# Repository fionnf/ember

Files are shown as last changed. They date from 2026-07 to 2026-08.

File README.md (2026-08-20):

# Ember

Two Raspberry Pi Pico W boards keeping their SK6812 RGBW LED strips in sync over MQTT. Touch one lamp and both shift colour together. Control everything from a web app that works on any phone or browser.

---

## Overview

```
[Web UI] ──MQTT (WebSocket)── [board_a / BOSS] ──sync── [board_b / follower]
                                SK6812 strip               SK6812 strip
```

One board (`board_a`, display name **A**) is the BOSS; the other (`board_b`, **B**) is the follower. Both subscribe to the same MQTT topic and keep their strips in sync. The web UI publishes JSON commands to the same topic and reflects live state from both boards.

---

## Hardware

| Part | Notes |
|---|---|
| Raspberry Pi Pico W (×2) | The W variant — needs WiFi |
| SK6812 RGBW LED strip | 10 LEDs per board, GRBW byte order |
| Data pin | GPIO 5 |
| 300–470 Ω resistor | Series on DIN — prevents ringing |
| 5 V power supply | USB or direct to strip |

### Wiring

```
Pico W GPIO 5 ──[330Ω]──── DIN ────────────── DOUT
5 V / 3.3 V   ─────────── VCC
GND           ─────────── GND

Pico W TOUCH_PIN ──┬──── copper pad / foil
                   └─[1MΩ]── GND
```

> Data flows DIN → DOUT; connect the board's data wire to the **DIN** end of the strip.

If board B connects via the far end (DOUT side), set `REVERSE_LEDS = True` in `config.py` to flip group order in software.

---

## Firmware

### Files

| File | OTA-updated | Purpose |
|---|---|---|
| `boot.py` | Never | OTA bootstrap — downloads firmware from GitHub on every boot |
| `main.py` | Yes | Main loop: WiFi, MQTT, touch, alarms, BOSS sync |
| `colour.py` | Yes | Colour engine: groups, fades, breathing, drift |
| `sk6812.py` | Yes | PIO-based SK6812 RGBW driver |
| `touch.py` | Yes | Capacitive touch detection |
| `config.py` | Never | Per-board constants (never overwritten by OTA) |

### OTA Updates

`boot.py` runs before `main.py` on every boot. It connects to WiFi and downloads the latest `main.py`, `colour.py`, `sk6812.py`, and `touch.py` from the `master` branch of this repo. `config.py` and `boot.py` are never touched. If WiFi is unavailable the board boots from whatever is already on flash.

To update both boards: commit and push to `master`, then click **↺ Reboot Both Boards** in the Settings panel.

Updates are **all-or-nothing**: every file is downloaded and compile-checked before any is installed, so a mid-update network drop can't leave a new `main.py` running against an old `colour.py`.

### Crash-loop rollback

The compile gate rejects firmware that doesn't parse, but valid code can still fail at runtime — a stray function-level `import` once shadowed a module-level one and both boards boot-looped, unreachable until a human pushed a fix. So the boards now keep a way back:

1. `boot.py` increments a counter in `bootfail.txt` on every boot. A **power-on** reset doesn't count — only soft and watchdog resets, which is what a crash loop produces.
2. Once `main.py` has run for a minute it calls `mark_stable()`: the counter is cleared and the running files are promoted to `.ok` backups. Backups are only rewritten when they actually differ, so this costs no flash in steady state.
3. After **3** boots that never reach stability, `boot.py` restores the `.ok` set and skips the update for that one boot — otherwise it would immediately reinstall the firmware that was failing. The lamp comes back on its own in about 15 seconds.
4. The board reports `rolled_back: true` in its heartbeat until it is stable again, so a rejected push is visible rather than silent.

No record is kept of the rejected version: the next scheduled reboot re-downloads `master`, so a pushed fix is picked up with no stale state to clear, and a few quick power cycles can't pin a board to old firmware.

> `boot.py` is **never** updated over the air — a broken bootloader would need USB to recover. Copy it to each board manually once to get this feature (`mpremote connect /dev/ttyACM0 cp boot.py :`).

### Configuration (`config.py`)

```python
BOARD_ID   = "board_a"    # "board_b" on the second Pico
BOSS       = True         # True on board_a only

NUM_LEDS       = 10
LED_PIN        = 5
REVERSE_LEDS   = False

NUM_GROUPS     = 3
GROUP_MIN_LEDS = 1
GROUP_MAX_LEDS = 8

LED_BRIGHTNESS = 0.6
FADE_STEPS     = 60       # steps per colour transition (~1 s at 60 Hz)
BREATHE_SPEED  = 0.0008   # radians/ms
BREATHE_DEPTH  = 0.04     # ±4% brightness oscillation

IDLE_DRIFT_INTERVAL_S = 45

MQTT_BROKER        = "broker.hivemq.com"
MQTT_PORT          = 1883
MQTT_TOPIC_PREFIX  = "ember_CHANGEME"   # ← set to your own unique value

WIFI_NETWORKS = [
    ("YourSSID", "YourPassword"),
]
```

### MQTT

- **Broker:** `broker.hivemq.com:1883` (TCP on device) / `:8884` WSS (web)
- **Events topic:** `<your-prefix>/events`
- **Alarms topic:** `<your-prefix>/alarms` (retained, subscribed by boards)
- **Status topic:** `<your-prefix>/status/<board_id>` (retained, Last-Will)
- **Scenes topic:** `<your-prefix>/scenes` (retained, client-to-client scene library)

All messages are JSON with a `from` field for echo suppression. The full contract is documented in [MQTT Protocol Specification](#mqtt-protocol-specification) — that section is the reference for writing an additional client.

### Colour Engine (`colour.py`)

The `ColourEngine` class manages per-group colour state:

- **Palette position** (`pos`, float 0.0–1.0): maps into a 30-stop hue palette blended with warm white. `0.0` = pure warm white (W channel only); higher values = saturated hues with W fading out.
- **Groups**: the strip is split into 1–N independent colour zones. Each group has a `pos` (hue) and a `w` (warm-white level). Group sizes are stored separately.
- **Fade**: each group independently crossfades from its start colour to its target over `FADE_STEPS` ticks, eased with smoothstep so the transition begins and ends imperceptibly. A fade takes the time it says it does — `fade_steps: 60` really is ~1 s.
- **Breathing**: a per-group sine oscillator adds a slow ±4% brightness pulse with staggered phases.
- **Drift**: optional autonomous colour drift — subtle hue nudges and group-size shifts every `IDLE_DRIFT_INTERVAL_S` seconds. Disabled by default in the web UI (`driftEnabled = false`).
- **Power**: soft on/off with an ~800 ms fade.

### BOSS / Follower Sync

When the BOSS's physical touch sensor fires, it runs `ColourEngine.impulse()` (random colour change), then publishes its new state with `"sync": true`. The follower applies the same groups with a fast fade (`SYNC_FADE_STEPS`) so both strips match immediately.

Every 60 s the BOSS publishes its state with `"sync": true` as a drift-correction heartbeat. The follower applies it with a slow 300-step fade so re-alignment is invisible.

**Independent mode.** That periodic sync would otherwise undo deliberate per-lamp settings — set one lamp with **Send to → B** and it reverted within a minute. So a **targeted** command (one carrying `target`) unlinks the lamps and suppresses the BOSS sync for 30 minutes; a **broadcast** colour command — which sets both lamps to the same thing — re-links them immediately. Boards notice targeted traffic even when it is addressed to the other lamp, so the BOSS knows to stand down.

### Alarms

Each board holds the whole schedule on its own flash (`alarms.json`) and evaluates it against its own clock, so **alarms fire with no client connected**. On each main-loop tick the board compares the current UTC time against enabled alarms and runs:

- **Sunrise** (`type: "sunrise"`): switches on and ramps brightness from 0 to `alarm.brightness` over `duration_min` minutes, sweeping **colour** alongside it — ember red → deep orange → amber → warm white. Because brightness rises together with the colour, the early stops are seen dim and deep, like a real dawn.
- **Bedtime** (`type: "sunset"`): the same sweep in reverse — warm white deepens to ember as it dims — then switches off (restoring the previous brightness so the next power-on isn't dark).

The gradient is `SUNRISE_STOPS` in `colour.py`, deliberately **not** taken from `TINT_PALETTE`: there a single `pos` sets hue and saturation together, so anything warm is also nearly white and a dawn would be an invisible tint.

Stops are evenly spaced by index, so where they sit is what shapes the fade. They are weighted toward the red end: the dawn opens on near-pure red `(255,6,0,0)`, the white LED stays completely dark for the first three fifths, and the turn to warm white happens in the last stretch. Red is never given up — the R channel is full the whole way — so it lands on a warm white with red still under it rather than a cold one. `tests/test_sunrise.py` pins that shape, so the stops stay tunable but the character can't drift back to turning orange almost immediately.

The schedule reaches boards two ways: the **retained** `P/alarms` topic, which boards subscribe to so an offline or rebooting board picks it up on reconnect, and a `set_alarms` message on `P/events` for boards that are already online. Alarms are compared in **UTC**; clients convert local time. See the [protocol spec](#alarms-1) for the exact format.

Two requirements: the board needs a **synced clock** (NTP at boot, retried hourly — the heartbeat's `ntp` field reports this, and the web UI warns when it's false), and it needs to have **received the schedule** (the heartbeat's `alarms` count confirms it). Use the **▶ Test** button on any alarm to run its fade immediately and verify the whole path.

### WiFi Watchdog

If the board loses its MQTT connection (WiFi down or broker unreachable) for more than 10 minutes (`WIFI_OFFLINE_REBOOT_MS = 600000`) it reboots to reconnect and pick up any OTA update. Known networks are the `WIFI_NETWORKS` list in `config.py` plus any saved to `networks.json` on flash, tried in order.

### State Persistence

On/off state and brightness are written to `state.json` and restored on boot before connecting to MQTT — so the lamps come back exactly as they were after the nightly OTA reboot.

Writes are deliberately rationed. The web app includes `on` in every state publish, so persisting on each message meant a flash erase/write on every slider tick (~8 per second while dragging) — needless wear, and each write stalls the render loop. State is now written only when it actually changes: immediately on a power toggle, before any planned reboot, and on a 5-minute flush that bounds what an unexpected power cut can lose.

### Daily OTA reboot

Each board reboots once a day at **17:00 UTC** (`OTA_HOUR_UTC` in `main.py`) to pull the latest firmware. State (on/off + brightness) is saved before the reboot and restored after, so the lamps come back as they were.

### Resilience layers

The firmware is designed to recover from anything without human intervention:

| Layer | Failure it handles |
|---|---|
| Hardware watchdog (8 s) | Firmware *hangs* — stuck DNS, dead socket, lockup → automatic reboot |
| Crash guard | Any unhandled exception → reboot in 5 s, OTA pulls a fix on the way up |
| OTA compile check | A broken push to master, truncated download, or HTML error page is **refused** — boards keep running the last good firmware |
| All-or-nothing OTA | Every file is downloaded and verified before *any* is installed, so a mid-update network drop can't leave a new `main.py` running against an old `colour.py` |
| Flash-write rationing | State is written only when it changes, so slider drags can't wear out the flash |
| Atomic file writes | Power cut mid-write can't corrupt firmware or state/alarm/network files |
| MQTT input validation | The events topic is on a public broker — every field is validated and clamped before touching the engine or flash; malformed messages are logged and dropped |
| MQTT watchdog | Broker unreachable > 10 min → reboot to re-establish everything |
| NTP retry | Failed clock sync at boot retries hourly (otherwise alarms would silently stay dead until the next reboot) |
| State persistence | On/off + brightness restored after any reboot |
| Periodic GC | Heap stays defragmented over weeks of uptime; free memory is reported in every heartbeat |

The watchdog can be disabled per board (`WATCHDOG_ENABLED = False` in `config.py`) while debugging over WebREPL.

---

## Web UI

`index.html` at the repo root is served via **GitHub Pages**. It connects to the HiveMQ broker over WebSockets. No install required — open it in any browser. On a phone you can **Add to Home Screen** to get it as a standalone full-screen app (web manifest included), and the app automatically reconnects when you return to it after backgrounding.

A service worker (`sw.js`) caches the app shell and the mqtt.js library, so the UI keeps working if the CDN is unreachable. HTML is fetched network-first, so a pushed update always lands rather than stranding you on a cached build.

### Controls

| Control | What it does |
|---|---|
| **Power** | Soft on/off; state reflected in board pills immediately |
| **Tap** | Random colour change (same as physically touching the lamp) |
| **Warm White** | Resets all groups to `pos=0.0, w=1.0` (pure warm white) |
| **Brightness** | Global brightness 0–100% |
| **Fade Speed** | Colour transition duration (~0.3 s–10 s) |
| **Send to** | Target Both boards / A only / B only |

### Strip preview

The top card shows the RGBW strip in real time. Click the small divider cells below the strip to split or merge colour groups.

### Groups

Each group gets a numbered handle on the palette bar — drag it along the hue gradient to pick a colour. The **Warm White** slider below each group blends in warm white independently.

### Alarms

Create sunrise/bedtime alarms per lamp with day-of-week selection, duration, and target brightness.

Times are entered in **your local time**; the small `HH:MM UTC` hint beside each one shows what the lamps actually compare against. Because the firmware only knows UTC, the app stores your intended local time and recomputes the UTC value when needed, so an alarm set for 07:00 stays at 07:00 after a daylight-saving change.

Each alarm has a **▶ Test** button that runs its fade on both lamps immediately (20 s) — the quickest way to confirm the whole path works. A warning banner appears if a lamp's clock hasn't synced, since alarms can't fire without it.

### Scenes

Save and load complete lamp states (colours, group layout, brightness, fade speed).

Scenes are stored in `localStorage` **and** mirrored to the retained `P/scenes` topic, so your phone, your laptop and any other client converge on one shared library. The merge is deliberately conservative — no device can destroy another's work:

- scenes merge by `id`, keeping whichever copy has the newer `updated` stamp
- a scene simply missing from another device's list means "not seen yet", never "delete it"
- deletions travel as **tombstones**, so a deleted scene isn't helpfully synced back by a device that still has it (kept to the last 50)

### Settings panel

| Field | Default | Description |
|---|---|---|
| WebSocket URL | `wss://broker.hivemq.com:8884/mqtt` | MQTT broker |
| Topic Prefix | randomly generated per install | Must match `MQTT_TOPIC_PREFIX` on the boards |
| LEDs | `10` | LEDs per strip |
| Groups | `3` | Initial group count |

Also: **Add WiFi Network** (sends credentials to both boards over MQTT), **↺ Reboot Both Boards** (triggers OTA update).

### Board presence pills

The two pills (A / B) at the top right show each board's status. Presence uses MQTT **Last-Will** on a retained per-board topic (`prefix/status/<board_id>`): each board publishes `{"online": true}` (retained) on connect, and the broker itself flips it to `{"online": false}` if the board dies silently (within ~90 s of its last keepalive). Because the status is retained, the pills are correct the instant the page loads. The web app additionally pings both boards on connect and every 2 minutes to refresh their full state.

- **Green (online)** — retained status online (or message seen within 150 s) and lights on
- **Amber (standby)** — same, but lights are off
- **No highlight (offline)** — broker reported the board offline, or nothing heard within 150 s

---

## MQTT Protocol Specification

This is the complete contract. Any client (this web app, another web app,
Home Assistant, a script) only needs these topics — there is no other API.

### Topics

With your `MQTT_TOPIC_PREFIX` (call it `P`):

| Topic | Direction | Retained | Payload |
|---|---|---|---|
| `P/events` | client ⇄ board | no | Command / state object (below) |
| `P/alarms` | client → board | **yes, QoS 1** | Bare JSON **array** of alarm objects |
| `P/status/<board_id>` | board → client | **yes** | `{"online": bool, "fw": str, "ntp": bool}` |
| `P/scenes` | client ⇄ client | **yes** | Shared scene library (below). Boards ignore it entirely |

Board IDs are `board_a` (BOSS, display name A) and `board_b` (follower, B).

A client should subscribe to `P/events`, `P/alarms`, and `P/status/+`.

### Message envelope (`P/events`)

Every message on `P/events` is a JSON **object**. Non-objects are dropped.

| Field | Type | Meaning |
|---|---|---|
| `from` | string | **Required.** Sender ID. A board ignores messages where `from` equals its own ID. IDs starting with `board_` mark board-to-board traffic |
| `target` | string | Optional. If present, only the board with this `board_id` acts on the message |
| `echo` | bool | Optional. Marks an informational state report. **Boards ignore echo-flagged messages** — see below |
| `sync` | bool | Optional. Board-to-board: apply colours with a slow 300-step fade |

> **The `echo` rule matters.** When a board answers a client, it replies with
> its full state plus `"echo": true`. Without that flag the *other* board
> would treat the reply as a real colour change and restart its fade — which
> caused a visible flash on every interaction. If you write a client, never
> set `echo` on commands you send; treat incoming `echo` messages as
> read-only state.

### Commands (client → board, on `P/events`)

All fields are optional; send only what you want to change. Every value is
validated and clamped by the firmware — out-of-range or wrong-typed fields
are ignored, never fatal.

| Field | Type | Range | Effect |
|---|---|---|---|
| `groups` | array | 1…`NUM_LEDS` entries | Per-group colour, below |
| `on` | bool | | Power, with an ~800 ms soft fade |
| `brightness` | number | 0.0–1.0 | Global brightness |
| `fade_steps` | number | 1–2000 | Crossfade length in ~16 ms ticks (60 ≈ 1 s) |
| `drift_enabled` | bool | | Autonomous idle colour drift |
| `drift_interval` | number | 5–86400 | Seconds between drift events |
| `reverse` | bool | | Flip LED order |
| `ping` | any | | Ask boards to reply with their state (`echo: true`) |
| `set_alarms` | array | ≤20 alarms | Install a schedule (see Alarms) |
| `test_alarm` | `"sunrise"` \| `"sunset"` | | Run that fade **immediately** |
| `test_seconds` | number | 2–600 | Duration for `test_alarm` (default 20) |
| `add_network` | object | | `{"ssid": str≤32, "password": str≤64}` — saved to the board's flash |
| `reboot` | truthy | | Save state and restart (triggers an OTA check) |

A `groups` entry:

```json
{"pos": 0.35, "w": 0.8, "size": 3}
```

| Field | Type | Range | Meaning |
|---|---|---|---|
| `pos` | number | 0.0–1.0 | Position in the hue palette. `0.0` = pure warm white (W channel only); higher = saturated tint with W fading out |
| `w` | number | 0.0–1.0 | Warm-white level for this group |
| `size` | integer | ≥1 | How many consecutive LEDs this group covers |

`size` values should sum to `NUM_LEDS`. If they sum to less, the firmware
extends the last group to cover the remainder (so no LED is left showing a
stale colour); if they sum to more, the extra is trimmed. The firmware
resizes its internal group arrays to match the array length, so a per-LED
gradient is simply `NUM_LEDS` groups of `size: 1`.

Example — set three groups and full brightness:

```json
{
  "from": "my_app",
  "groups": [
    {"pos": 0.0,  "w": 1.0, "size": 4},
    {"pos": 0.35, "w": 0.8, "size": 3},
    {"pos": 0.7,  "w": 0.6, "size": 3}
  ],
  "on": true,
  "brightness": 0.6,
  "fade_steps": 60
}
```

### Reports (board → client, on `P/events`)

**State echo** — sent whenever a board acts on a client message (including `ping`):

```json
{
  "from": "board_a", "echo": true,
  "groups": [{"pos": 0.0, "w": 1.0, "size": 10}],
  "on": true, "brightness": 0.6, "fade_steps": 60,
  "drift_enabled": false, "drift_interval": 45
}
```

**Heartbeat** — every 30 s:

```json
{"from": "board_a", "heartbeat": true, "fw": "2026-07-26.5",
 "mem": 102400, "ntp": true, "alarms": 2}
```

| Field | Meaning |
|---|---|
| `fw` | Firmware version |
| `mem` | Free heap bytes — watch for leaks |
| `ntp` | **Clock synced?** If `false`, alarms cannot fire — surface this to the user |
| `alarms` | How many alarms the board currently holds — confirms delivery |

**Impulse / boss sync** — a physical touch, or the BOSS's 60 s sync. Same
shape as a state echo but **without** `echo`, so the other board applies it.
Boss syncs carry `"sync": true`.

### Presence (`P/status/<board_id>`, retained)

```json
{"online": true, "fw": "2026-07-26.5", "ntp": true}
```

Registered as the board's MQTT **Last-Will** with payload `{"online": false}`,
so the *broker* publishes the offline state if a board dies silently
(~90 s, from the 60 s keepalive). Because it is retained, a client knows both
boards' state the instant it subscribes — no waiting for a heartbeat.

Recommended client logic: treat `online: false` as authoritative offline;
otherwise consider a board present if `online: true` or a message arrived
within ~150 s. Show offline if your own broker connection is down.

### Alarms

Two transports, both needed:

1. **`P/alarms`, retained, QoS 1** — the durable schedule. Boards subscribe
   to it, so one that was offline or rebooting when the schedule changed
   receives it on reconnect. Payload is a bare JSON **array**.
2. **`{"set_alarms": [...]}` on `P/events`** — the instant path for boards
   that are already online.

Publish **both** on every change, and **never** set `target` on an alarm
update: which lamp acts is decided by the alarm's own `boards` field.

```json
[
  {
    "enabled": true,
    "type": "sunrise",
    "hour": 5,
    "minute": 0,
    "duration_min": 30,
    "brightness": 1.0,
    "days": [0, 1, 2, 3, 4],
    "boards": ["board_a", "board_b"]
  }
]
```

| Field | Type | Range | Meaning |
|---|---|---|---|
| `enabled` | bool | | Skipped when false |
| `type` | string | `sunrise` \| `sunset` | Fade up, or fade down and switch off |
| `hour` | int | 0–23 | **UTC** — see below |
| `minute` | int | 0–59 | **UTC** |
| `duration_min` | int | 1–180 | Ramp length in minutes |
| `brightness` | number | 0.0–1.0 | Sunrise target (ignored for sunset) |
| `days` | int array | 0=Mon … 6=Sun | Omit or send a non-array for *every day* |
| `boards` | string array | board IDs | Which lamps act. Empty/omitted = all |

Each board evaluates the schedule against **its own** UTC clock and runs its
own ramp, so alarms work even with no client connected. At most one alarm
fires per minute per board; a fired alarm is remembered until the next day
(keyed on hour+minute+type, so a sunrise and a sunset at the same time both
fire).

> **Timezone.** The Pico has no timezone database, so the firmware only
> understands UTC. Clients are responsible for converting. This web app edits
> in local time and stores the user's intent in two extra fields, `lh`/`lm`
> (local hour/minute), recomputing `hour`/`minute` on load so alarms keep
> their wall-clock time across a DST change. The firmware ignores `lh`/`lm`.
> **If you write another client, either use the same convention or send UTC
> directly** — and be aware this app will rewrite `hour`/`minute` from
> `lh`/`lm` if both are present.

To verify a schedule without waiting for the clock, send
`{"from": "my_app", "test_alarm": "sunrise", "test_seconds": 20}` — the
board runs the real alarm code path immediately.

### Scenes (retained on `P/scenes`)

Boards ignore this topic entirely; it exists so multiple clients share one
scene library. Publish **retained** so a client that connects later gets it.

```json
{
  "v": 1,
  "from": "web_app",
  "scenes": [
    {
      "id": "lz4f8x-a91b2c",
      "updated": 1774598400000,
      "name": "Evening",
      "groups": [{"pos": 0.0, "w": 1.0, "size": 10}],
      "boundaries": [], "groupPositions": [0.0], "groupWLevels": [1.0],
      "brightness": 0.4, "fadeSteps": 120, "on": true
    }
  ],
  "deleted": ["old-scene-id"]
}
```

| Field | Meaning |
|---|---|
| `id` | Stable unique string. **Required** for a scene to take part in sync |
| `updated` | Epoch ms of the last edit — the conflict tiebreak |
| `deleted` | Tombstoned ids, capped at the most recent 50 |

Merge rules (implement these and two clients can't fight):

- union by `id`; on a clash keep the higher `updated`
- a scene absent from the other side means "not seen yet", **not** "delete"
- honour incoming tombstones, and keep publishing your own so a delete
  doesn't get synced back by a device that still holds the scene
- if the merge changed nothing, don't republish — otherwise two clients
  ping-pong retained messages forever

Everything except `id`, `updated` and `name` is opaque payload; this app
stores the fields shown, but another client may store whatever it needs.

### Guarantees for client authors

- Malformed messages are logged and dropped; they never crash a board or
  drop its MQTT connection.
- Unknown fields are ignored, so the protocol can be extended safely.
- Boards persist power state, brightness, and alarms to flash and restore
  them after any reboot.
- The events topic is on a **public broker**. Anyone who knows your prefix
  can control your lamps — pick an unguessable `MQTT_TOPIC_PREFIX`, or run
  your own broker with authentication.

---

## First-Time Setup

1. **Flash MicroPython** — download the Pico W UF2 from micropython.org, hold BOOTSEL, drag it on.

2. **Install umqtt** (in Thonny shell or `mpremote`):
   ```python
   import mip
   mip.install("umqtt.simple")
   ```

3. **Upload files** (only once):
   ```bash
   mpremote connect /dev/ttyACM0 cp boot.py config.py :
   ```
   Set your WiFi credentials in `WIFI_NETWORKS` in the board's `config.py`
   (or create `networks.json` on the board — a list of `[ssid, password]` pairs):
   ```json
   [["YourNetwork", "YourPassword"]]
   ```

4. **Edit `config.py`** — set `BOARD_ID`, `BOSS`, `NUM_LEDS`, `LED_PIN`, `MQTT_TOPIC_PREFIX`.

5. **Reboot** — `boot.py` downloads `main.py`, `colour.py`, `sk6812.py`, `touch.py` from master and starts.

---

## Troubleshooting

| Symptom | Cause | Fix |
|---|---|-----|
| Board B LEDs don't light | Connected to DOUT | Run wire to DIN end |
| Wrong colours | Byte-order mismatch | SK6812 uses GRBW — check `sk6812.py` |
| Groups reversed on board B | Far-end connector | `REVERSE_LEDS = True` in `config.py` |
| Touch never fires | Threshold too high | Lower `TOUCH_THRESHOLD` in `config.py` |
| Touch fires constantly | Missing pull-down | 1 MΩ between GPIO and GND |
| Boards not syncing | Different topic prefix | `MQTT_TOPIC_PREFIX` must match on both |
| Board reboots after ~10 min offline | WiFi watchdog | Expected; board reconnects and checks OTA |
| **Alarm fires at the wrong time** | Alarm times are UTC; older clients sent local time as UTC | Times are now edited in local time and converted. Check the small `HH:MM UTC` hint next to each alarm |
| **Alarm never fires** | Board has no clock (NTP failed) | The web UI shows a warning banner; heartbeat `ntp` is false. Retries hourly, or reboot the board |
| **Alarm never fires**, clock is fine | Board never received the schedule | Heartbeat `alarms` count shows 0. Fixed by the retained `P/alarms` topic; press **▶ Test** to confirm the path |
| Alarm only fires on one lamp | Alarm's `boards` list, or a client sending `target` with the update | Enable both lamps on the alarm; never set `target` on alarm updates |
| OTA not updating | `boot.py` not on board | Flash `boot.py` manually once via USB |

---

## Project Structure

```
ember/
├── index.html              # Web UI — single source, served by GitHub Pages
├── sw.js                   # Service worker — caches shell + mqtt.js
├── manifest.json           # PWA manifest (Add to Home Screen)
├── main.py                 # Firmware — main loop (OTA-fetched)
├── colour.py               # Firmware — colour engine (OTA-fetched)
├── sk6812.py               # Firmware — PIO LED driver (OTA-fetched)
├── touch.py                # Firmware — capacitive touch (OTA-fetched)
├── boot.py                 # OTA bootstrap (deployed manually, never overwritten)
├── config.py               # Per-board config TEMPLATE — real credentials live
│                           #   only on the boards, never in the repo
├── hardware_test.py        # Standalone wiring test (no WiFi/MQTT needed)
├── favicon.svg
└── README.md
```

> **Security note:** this repo is public (it serves the web UI via GitHub Pages).
> Never commit real WiFi or WebREPL passwords — edit them only in the `config.py`
> that lives on each board, which OTA never touches.

---

Personal project — no license.

---

## Tests

```bash
python3 tests/test_firmware.py     # boots main(), MQTT commands, flash writes
python3 tests/test_ota.py          # OTA all-or-nothing install
python3 tests/test_rollback.py     # crash-loop rollback
python3 tests/test_sunrise.py      # dawn gradient shape
node    tests/test_scene_sync.js   # scene merge / tombstone rules
```

Runs `main()` against stubbed MicroPython modules (`tests/stubs/`) and checks
that the board boots, arms and feeds the watchdog, subscribes to the events
**and** retained alarms topics, registers its Last-Will, publishes presence and
heartbeats, reboots on command, installs a retained alarm schedule, applies
colour commands, and survives malformed input.

`test_ota.py` drives `boot.py`'s updater against a stubbed HTTP layer and
asserts that a network drop, a syntax error, or an HTTP error part-way
through leaves the existing firmware completely untouched.

Run both before pushing to `master`. `python -m py_compile` only catches syntax
errors — it cannot catch a runtime fault such as a stray function-level
`import`, which once shadowed a module-level import for the whole of `main()`
and put every board into a boot loop.

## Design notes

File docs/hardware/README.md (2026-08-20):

# EM-15 — integrated lamp board

**Ember · EM-15 rev C · designed by Fionn Ferreira**
<https://github.com/fionnf/ember>

> **rev C supersedes the geometry below.** The electronics moved off the end of the strip
> into a rear bulge at the middle so the USB-C plugs in from the back; the LED row stayed
> continuous. The board is now a 228 × 20 mm strip with a 48 × 28 mm bulge, not 282 × 20.
> Everything else — the schematic, the BOM, the power budget, the bring-up plan — is
> unchanged, with two exceptions noted in [`../../hardware/fl11/README.md`](../../hardware/fl11/README.md):
> `R11` becomes 100 Ω, and SENSE runs in a guarded y=18.6 lane. The built KiCad project
> is in `hardware/fl11/`.

This is the hardware design for a single PCB that replaces the discrete build (Pico W + separate SK6812 strip + a foil touch pad on a wire). One piece of FR4 carries the MCU, the radio, eleven SK6812 RGBW LEDs at standard 60 LED/m pitch, power input and protection, and a capacitive touch pad on a break-away tab. It is designed to be ordered from JLCPCB as a panel, assembled turnkey with no hand-soldering and no per-unit calibration, and to run the existing MicroPython firmware with a six-line `config.py` change and one rewritten driver file.

The optimisation target is **total landed cost per assembled board at qty 100**, subject to a hard floor: it has to work on the first batch. A board that needs rework, per-unit tuning, or a revision spin is not cheap at any BOM price. Everything below states what a choice cost and what would break if it were deleted.

**Where it lands: $7.60 landed per assembled board at qty 100, $17.10 for a complete boxed lamp** including a 2.4 A supply and a self-printed enclosure. That is inside the $20 target with $2.90 of room, and the honest electronics-only floor with these features is about $5.60.

---

## 1. Assumptions, and the decisions still open

### Assumptions this design is built on

| Assumption | Consequence if wrong |
|---|---|
| Volume is 10–100 units, friends scale, possible small sale later | The whole cost model is setup-dominated. At qty 500 the fixed costs vanish and different trades open up (injection moulding, 4 layers, a bare RP2040) |
| Turnkey assembly, strong preference for JLCPCB library parts, no hand-soldering | This is what eliminated the Pico W carrier — JLCPCB does not stock the Pico W, so it is consigned or self-reflowed, and self-reflowing 100 castellated modules *is* hand-soldering |
| Pre-certified radio module, not a bare MCU + antenna | Correct, and I did challenge it — see §4. A bare RP2040 + RM2 layout stacked four independent first-article killers and RM2 is not a JLC library part either, so the radio ends up consigned anyway |
| Keep the 10× SK6812 RGBW linear light engine | Kept, at 11 LEDs. RGBW (four channels, GRBW order) is load-bearing: `colour.py`'s entire model is W-channel-dominant (`BASE_WARM_WHITE = (0,0,0,200)`) |
| MicroPython + existing OTA/config keeps working | Drove the pin map (`LED_PIN` stays 5) and the driver strategy (identical class API, capability-detected back end, one file serves both hardware generations) |

### Open decisions — yours, not mine

| # | Decision | My recommendation | What it costs |
|---|---|---|---|
| 1 | **MCU family.** ESP32-C3-MINI-1 vs a Pico W carrier | **ESP32-C3**, gated on Stage 0 passing before any PCB is ordered | Pico W is **+$5.20/unit, +$520 over 100**, and reintroduces the consignment/self-reflow problem. The C3 costs one rewritten file (~40 lines), testable for $15 on a dev board before you spend anything |
| 2 | **Enclosure: printed in-house or bought in?** | In-house if you can commit the machine time; otherwise the $20 target fails and should be moved | Three printed parts (base, 184 mm spine, top cap), ~55–70 g and **~6.5 machine-hours per lamp → ~650 printer-hours for 100 units**, roughly a month of continuous single-machine printing, plus 5–10 % print failures. Outsourced MJF/SLS is $6–9/unit → complete lamp $22–25, **over target** |
| 3 | **Board width 20.0 mm.** Narrowed from 24.0 to fit the diffuser tube with a spine (see §7.3) | 20.0 mm board in a 30 mm OD tube | Free, in fact −$0.15/board of PCB area. The alternative is a 35 mm OD tube (+$1.20) with a 24 mm board |
| 4 | **Ship a 5 V / 2.4 A supply in the box?** | **Yes** | $3.50. If you don't, `MAX_CHANNEL_SUM` must drop from 680 to ~450 so the lamp survives a legacy 500 mA host — visibly dimmer, and a product decision rather than an implementation detail |
| 5 | **White vs green soldermask** | **White**, unless JLC quotes more than $0.15/board | +$0.10/board. The board is the reflector inside a diffuser tube; 10–20 % more light out is the cheapest optical gain available |
| 6 | **Leaded (Sn63Pb37) vs lead-free reflow** | **Leaded** at friends scale | Leaded is JLC's cheaper option **and** its ~217 °C peak is materially kinder to the SK6812 lens and phosphor than 245–250 °C. It is **not RoHS**. Selling into the EU/UK means lead-free (+~$0.30/board) and revalidation |
| 7 | **Certification, if "possible small sale later" becomes real** | Have this conversation before you commit | The module carries FCC/IC/CE/UKCA modular approval, so no intentional-radiator campaign. A commercial sale still needs FCC Part 15B ($1.5–3k) and a CE/RED DoC ($1–3k). **That bill exceeds the entire BOM cost of your first 300 units** |
| 8 | **`GROUP_MAX_LEDS`: 8 or 9?** | **Keep 8.** See §8.2 — I ran the actual partition algorithm 200 000 times | Raising it to 9 to make the constant "honest" makes `(9,1,1)` the single most common partition, once every nine taps. That is a visible aesthetic regression for a cosmetic correctness gain |
| 9 | **Touch pull-down value and overlay thickness** | Fit **4.7 MΩ**, print the cap's touch face at **1.0 mm**, and settle both from Stage 1 measurement | Both are no-respin knobs. Touch is the least-certain subsystem in this design and §7.5 says so plainly rather than quoting modelled numbers as facts |

---

## 2. Architecture

```
                        EM-15  —  282.0 × 20.0 × 1.6 mm, 2 layer, single-sided SMT

 x=0                       56                                              239           250   282
 |<--------- HEAD --------->|<------------- LIT ZONE 183.33 --------------->|<-- gap -->|<-TAB->|
 +--------------------------+------------------------------------------------+---.---+--------+
 | [USB-C]  470uF  Q1  LDO  | (1) (2) (3) (4) (5) (6) (7) (8) (9) (10) (11)  |   .   | SENSE  |
 |          F1   ESD  [C3]  |      16.6667 mm pitch, all on y = 11.0         |   .   | ------ |
 |               [AHCT] [R] |                                                |   .   |  GND   |
 +--------------------------+------------------------------------------------+---.---+--------+
                                                                  break line ----'  (x = 250)

 USB-C 16P sink --+-- VBUS --[PPTC 2A/4A]--+-- AO3401A P-FET --+-- +5V (~4.94 V)
   CC1 -[5k1]-GND |                    S <-|  soft-start,      |
   CC2 -[5k1]-GND |     R 100k G->GND      |  drain to load    |
   D+/D- ---------+-[USBLC6-2SC6]-> IO19/IO18   C 100n G->S    |
                  |                                            |
                  +-- USBLC6 VBUS pin = ESD clamp              |
                                                               |
   +5V --+-- AP2112K-3.3 (EN -> VIN) -- +3V3 --+-- ESP32-C3-MINI-1-N4
         |                                     +-- 22uF + 100nF local at the module
         |
         +--[LK1 cuttable link / DNP S1A]-- LED_5V --+-- 470 uF + 22 uF
                                                     +-- 74AHCT1G125 Vcc  (OE_n -> GND)
                                                     +-- LD1..LD11 V_DD, 11 x 100 nF

   IO5 --+-[5k1]-GND  ->  AHCT in -> out -[47R]-> LD1.DIN -> ... -> LD11.DOUT -> TP7
   IO3 --+-[5k1]------->  SENSE (guarded, 195 mm) ==bridge== SENSE PAD  (tab)
         +-[4M7]-GND                              ==bridge== GND RETURN PAD (tab)
   IO2 -[5k1]-3V3   IO8 -[5k1]-3V3   IO9 -[5k1]-3V3 + tact SW to GND
   No reset button, by design.
```

Three things about this diagram are worth stating up front because they are the load-bearing choices:

**The 74AHCT1G125 is not optional.** SK6812 `V_IH = 0.7 × V_DD = 3.46 V` at a 4.94 V rail. An ESP32-C3 GPIO delivers 3.1–3.3 V. That is unconditionally out of spec and it is the intermittent field failure no firmware update can reach.

**The touch pad is a split pair, not a single pad.** SENSE and a GND return electrode sit side by side under the same overlay, so the finger's displacement current has a local return that does not depend on the power supply being earthed. This is a correction; see §7.5.

**The break-away tab is an internal routed slot in a plain rectangular outline.** The board profile is a 282 × 20 rectangle. The tab costs zero panel area and zero nesting effort, which is a real advantage over a profiled tab.

---

## 3. Governing constants

These numbers are referenced everywhere else in this document and in the firmware. They live here so there is exactly one place to change them. An earlier draft of this design carried the touch pull-down at three different values in three sections; that is how boards get built wrong.

| Constant | Value | Set by |
|---|---|---|
| Board outline | 282.0 × 20.0 × 1.6 mm | §7.1 |
| LED count / pitch | 11 / 16.66667 mm | §7.2 |
| LED row centreline | y = 11.000 mm | §7.2 |
| LED1 centre / LED11 centre | x = 64.000 / x = 230.667 mm | §7.2 |
| Lit zone | x 55.67 → 239.00 (183.33 mm) | §7.2 |
| Break slot centre | x = 250.000 mm | §7.6 |
| Touch pull-down `R_TPD` | **4.7 MΩ** (0402, land also accepts 10 MΩ) | §7.5 |
| Touch series `R_TS` | 5.1 kΩ | §7.5 |
| Touch overlay thickness | 1.0 mm nominal, 0.8–2.0 mm allowed | §7.5 |
| `MAX_CHANNEL_SUM` | 680 of 1020 | §5.4 |
| Unclamped worst-case input current | 1.24 A | §5.3 |
| Input path / copper sized for | 1.6 A | §5.5 |
| Panel | 6-up, 282 × 140 mm, routed slots + mouse bites | §7.8 |

---

## 4. Design decisions

| Decision | Why | What it cost |
|---|---|---|
| **ESP32-C3-MINI-1-N4**, not a Pico W carrier, not a bare RP2040 + RM2 | It collapses MCU, 4 MB flash, crystal, radio, RF layout, regulatory approval and USB-serial into one reflowed, JLC-placeable, pre-certified part. Every assembly-yield risk that sinks a bare-QFN layout and the supply risk that dents a Pico W carrier simply do not exist. Its one liability — `import rp2` dies — is bounded to one file, OTA-recoverable, and **retirable for $15 before a single PCB is ordered.** A risk you can pre-test is worth several dollars a unit under a first-batch gate | −$5.20/unit versus the Pico W. Costs a ~40-line rewrite of `sk6812.py`, plus a night on a dev board |
| **74AHCT1G125 level shifter on DIN** | `V_IH = 3.46 V` required, 3.3 V available. AHCT at 5 V has *TTL* thresholds: `V_IH(min) = 2.0 V` → +1.3 V input margin, `V_OH(min) = 4.4 V` at −8 mA → +0.94 V output margin. Both margins are rail-independent because the buffer and the LEDs share the same rail | **$0.11 + one 100 nF.** The cheapest insurance on the board. Rejected alternatives are priced in §6.5 |
| **AP2112K-3.3 LDO**, not AMS1117, not a buck | Dropout is the argument. Worst realistic case (5 V charger at −10 %, long cheap cable, full white) puts 4.13 V at the LDO input. AMS1117 needs ~0.8 V at 350 mA and brownouts. A buck saves 0.13 W and costs an inductor, two feedback resistors and a 1.5 MHz switching node 10 mm from a certified antenna | $0.06. Three BOM lines and 40 mm² cheaper than a buck |
| **LEDs run directly off the protected 5 V rail** | Putting 0.9 A through a regulator to gain nothing is a 1.5 W thermal problem | Free |
| **AO3401A P-FET, source on the INPUT side** | Reverse blocking and soft-start are mutually exclusive with one P-FET, and **inrush is the failure that ships**. Source-on-load lets the body diode charge 470 µF straight from VBUS the instant the connector mates — no soft-start at all, the source hiccups, and the user learns "it only turns on if I re-plug it". Reverse polarity is physically unreachable through USB-C | $0.04. Reverse protection for the DNP aux pads is restored by a DNP series Schottky the bench user must fit anyway |
| **11 LEDs, 16.66667 mm pitch** | 11 is the only count that hits both the 167 mm length and the 60 LED/m pitch. 10 LEDs spans 150 mm; forcing 167 mm across 10 gives an 18.56 mm pitch that no longer matches a strip | +1 LED placement (~$0.08) and +$0.02 of bypass cap |
| **Break-away tab as an internal routed slot** | V-score cannot make an interior or partial cut — the blade must traverse the whole panel edge to edge. This is geometry, not preference. An internal slot also keeps the outline a plain rectangle, so the tab costs zero panel area | Zero. Internal slots are part of the profiling operation and carry no surcharge |
| **Plain plated through-hole pads at the break, no connector** | Castellated half-holes at a break line are not manufacturable (the plating tears when you snap it). A JST-PH adds a connector, a housing, a crimp op and ~$0.35 to *every* unit to serve a minority configuration. The drills are already in the drill file | Zero. In the default configuration they are unused copper that doubles as the SENSE/GND test points |
| **Split SENSE/GND touch pad** | The usual single-pad self-capacitance sensor assumes the finger's return is mains earth. This lamp ships with a 2-prong Class II adapter and floats. A local GND return electrode under the same fingertip makes ΔC independent of what the board's ground is referenced to | Zero — it reuses guard-ring copper and an existing net. It halves the peak ΔC and removes a 57–80 % supply-dependent loss, which is a good trade |
| **Routed slots + mouse bites between boards in the panel, not V-score** | The module's antenna must sit near a board edge, and a V-score blade cutting 1/3 depth from each face with ±0.15 mm positional tolerance has no clearance to a module can set back under ~1 mm. Routed separation removes the blade entirely | ~$0.05/board of routing time. It also returns the 0.5 mm V-score copper setback to the touch guard rail |
| **Single-sided assembly, 2 layers, 1.6 mm, HASL** | A pre-certified module means there is no antenna to lay out, so 2 layers is sufficient. Everything fits on the LED face. 1.6 mm is standard, free, and load-bearing for stiffness over 282 mm | Saves ~$0.55/board of second-side setup and the $8.18 second setup fee |
| **No reset button** | Verified against the code, correcting a claim that gets repeated: `boot.py:84-85` increments `bootfail.txt` on any non-`PWRON_RESET` boot, **but `main.py:139-166 mark_stable()` writes it back to "0" after 60 s of running.** One reset press is harmless. The real hazard is narrow — three resets inside 60 s each, i.e. an impatient user — but it is real, and recovery by unplug/replug is what `boot.py` actually wants | −$0.04 and one BOM line. TP10 on `EN` replaces it |
| **PPTC 2 A hold / 4 A trip, not 1.5 A** | Hold current derates ~25 % at 50 °C, so a 1.5 A part holds ~1.15 A against a 1.24 A unclamped worst case — a nuisance trip, not protection | $0.06. Kept because it protects the *user's charger or laptop port*, not the board |

---

## 5. Power budget — computed for eleven LEDs

Every figure here is recomputed for 11. None is a ten-LED number reused.

### 5.1 Per LED and per string

The four channels are **not** interleaved inside the SK6812 die — all four sink simultaneously, so currents add. Do not budget on an average.

| | per LED | × 11 |
|---|---|---|
| Absolute worst (4 ch × 20 mA + 1 mA IC) | 81 mA | **891 mA** (4.46 W) |
| Typical real parts, full white (4 × 16 + 1) | 65 mA | 715 mA |
| At `LED_BRIGHTNESS = 0.6`, full white | 49 mA | 539 mA |
| **With the firmware clamp at 0.667** | 54.5 mA | **598 mA** |
| App default `BASE_WARM_WHITE (0,0,0,200)` @ 0.6 | 10.4 mA | **114 mA** |
| All off (IC quiescent) | 1 mA | 11 mA |

### 5.2 MCU rail

| | mA @ 3.3 V |
|---|---|
| C3 @ 160 MHz running MicroPython, modem-sleep, associated | 30–45 |
| Wi-Fi RX active | ~85 |
| **Wi-Fi TX burst, 802.11b @ 20 dBm, ≤ 2 ms** | **~350** |
| Design continuous | **100** |
| Design peak | **350** |

The 350 mA TX burst is *higher* than the CYW43439's ~290 mA. That is a real, if small, cost of the C3 decision, and it is why the LDO choice is a dropout argument rather than a price argument.

### 5.3 Totals at the 5 V input

| Scenario | LEDs | MCU | Total | Power |
|---|---|---|---|---|
| Idle, LEDs off, TX burst | 11 mA | 350 mA | 361 mA | 1.8 W |
| Normal use (warm white @ 0.6, Wi-Fi idle) | 114 mA | 60 mA | **174 mA** | 0.87 W |
| Clamped worst case | 598 mA | 350 mA | **948 mA** | 4.7 W |
| **Unclamped worst case** (100 % RGBW @ brightness 1.0) | 891 mA | 350 mA | **1.24 A** | **6.2 W** |

**Design rule: size the input path, fuse and copper for 1.6 A** — the unclamped case with 30 % headroom, so that removing the clamp in a future OTA cannot damage hardware. `colour.py:239` clamps brightness to [0,1] and MQTT can command 1.0 with full RGBW at any moment.

### 5.4 The clamp, and why it exists

`MAX_CHANNEL_SUM = 680` caps the per-LED sum of R+G+B+W after brightness and **independently of** `LED_BRIGHTNESS`, so a user setting brightness 1.0 over MQTT cannot exceed it.

It is doing double duty. Electrical input per LED at the clamp is 5 V × 54.5 mA = 0.27 W, of which ~30 % leaves as light → **0.19 W of heat per LED, 2.1 W for the string.**

| Source | Clamped | Unclamped full white |
|---|---|---|
| LED string (heat) | 2.1 W | 3.1 W |
| LDO ((5−3.3) × 0.10) | 0.17 W | 0.17 W |
| P-FET | 0.05 W | 0.09 W |
| PPTC | 0.05 W | 0.08 W |
| **Board total** | **2.37 W** | **3.44 W** |

With generous pour on both layers, ≥60 mm² per LED per layer and ≥4 thermal vias per LED, θ_JA is about **140 °C/W** (versus 250–350 °C/W with pad-sized copper only):

- Clamped, in a 39 °C enclosure interior: ΔT_j = 0.27 × 140 = 38 °C → **T_j ≈ 77 °C.** Under the 85 °C comfort line.
- Unclamped sustained full white, 45 °C interior: ΔT_j = 57 °C → **T_j ≈ 102 °C.** Phosphor lumen-maintenance and colour-point degradation territory.

The clamp lives in the LED driver's write path, which *is* OTA-able, so the value can be revised after the first thermal measurement. **The hardware is sized for the unclamped case regardless.**

**Enclosure requirement, and it is a hard one: ≥180 cm² of external surface with at least passive venting.** A 30 mm OD × 220 mm tube gives 210 cm² and qualifies (ΔT ≈ 14 °C clamped, ≈ 20 °C unclamped). A small sealed diffuser at 100 cm² would double the interior rise and push T_j past 110 °C even clamped.

### 5.5 Copper and IR drop

IPC-2221 external, ΔT = 10 °C, k = 0.048, 1 oz:

```
dT^0.44 = 2.754 ;  k*dT^0.44 = 0.1322
I = 1.6 A -> (1.6/0.1322)^1.379 = 12.10^1.379 = 31.1 mil^2
width = 31.1 / 1.378 = 22.6 mil = 0.57 mm minimum
```

**Specified: 7.8 mm 5 V pour and 3.4 mm GND pour along the row** — 6–14× the minimum, free, and doubling as the LED heatsink.

**IR drop to LED11**, which is the 167 mm question everyone asks. Sheet resistance 1 oz = 0.494 mΩ/sq. Bulk cap to LED11 ≈ 200 mm. With a 7.8 mm pour: 200/7.8 = 25.6 squares → 12.7 mΩ per rail, 25.4 mΩ out and back. The load is distributed (LED1 carries eleven LEDs' current, LED11 carries one), so end-of-line drop is `I_total × R / 2`:

```
0.891 A x 0.0254 ohm / 2 = 11 mV
```

**LED11 sees 4.93 V.** Even a bare 1 mm trace would give 88 mV. The 167 mm length is a complete non-issue for IR drop — no injection points, no second feed.

### 5.6 Bulk capacitance

Largest realistic load step is off → full white, 0 → 0.891 A, against an upstream source loop response of ~200 µs:

```
dV = I*dt/C = 0.891 x 200us / 470uF = 0.379 V  -> rail dips to 4.56 V
```

Harmless: SK6812 tolerates 4.5–5.5 V and the LDO still has over a volt of headroom. Scaling from ten LEDs to eleven moves the droop from 0.345 V to 0.379 V — **no part change**, which is worth stating so nobody re-derives it.

**Not 1000 µF.** That figure is folklore for 30–60 LED strips on flying leads; here it would make the inrush problem twice as bad for no benefit.

Paralleled with **22 µF 0805 X5R** for high-frequency ESR — at 5 V DC bias an X5R 22 µF derates to about 11 µF effective, which is exactly what the LED rail wants. This is why a separate 10 µF line was deleted.

**11 × 100 nF 0402 X7R, one per SK6812 V_DD pin, with a via straight to the plane.** Non-negotiable. Each SK6812 switches four constant-current sinks at its internal PWM rate, and an unbypassed neighbour's di/dt is the *actual* cause of "random flicker" that gets endlessly misdiagnosed as a data-timing problem.

### 5.7 Inrush soft-start arithmetic

```
tau = R_G * C_G = 100k * 100nF = 10 ms
I_inrush ~= C_bulk * V_in / tau = 470uF x 5 V / 10 ms = 235 mA   (under the USB 500 mA default)
Conduction loss at 0.95 A = 0.95^2 x 0.060 = 54 mW, drop 57 mV
V_GS steady state = -5 V, well inside the +/-12 V rating. No gate Zener.
```

**Be honest about this figure: 235 mA is an estimate, not a guarantee.** The gate ramp is exponential in V_GS while I_D is quadratic in (V_GS − V_th), so the real peak is realistically 200–400 mA and depends on the AO3401A transfer characteristic. **Stage 1 must scope VBUS and drain current over at least 20 hot-plug cycles.** Two drop-in fixes if it comes in too high, neither needing a respin:

1. `C_G` → 470 nF (τ = 47 ms, inrush ≈ 50 mA). One BOM value change.
2. Fit `C21`, a DNP 100 nF from GATE to DRAIN — a Miller cap gives *deterministic* dV/dt: 35 µA / 100 nF = 350 V/s → 165 mA. The footprint is laid down for free.

Uncontrolled, charging 470 µF through 0.2 Ω of cable is a theoretical 25 A peak. In practice the source hiccups and you get "the lamp doesn't turn on unless I unplug and re-plug it" — a support burden worth far more than $0.03.

---

## 6. Schematic, block by block

Designators, then the netlist per block. Verified against `config.py`, `main.py`, `colour.py`, `sk6812.py`, `touch.py`, `boot.py` and `hardware_test.py` in this repo.

### 6.0 Designator index

| Ref | Part | Package | Qty |
|---|---|---|---|
| U1 | ESP32-C3-MINI-1-N4 | module, 53-pad | 1 |
| U2 | SN74AHCT1G125DBVR | SOT-23-5 | 1 |
| U3 | AP2112K-3.3TRG1 | SOT-23-5 | 1 |
| U4 | USBLC6-2SC6 | SOT-23-6 | 1 |
| Q1 | AO3401A | SOT-23 | 1 |
| LD1–LD11 | SK6812-class RGBW (GRBW) | 5050-4P | 11 |
| F1 | PPTC 2.0 A hold / 4.0 A trip | 1812 | 1 |
| SW1 | Tact switch, SMD | 3×4 mm | 1 |
| J1 | USB-C 2.0 receptacle, 16-pin, THT shield tabs | — | 1 |
| C1 | 470 µF / 10 V alu SMD | 8 × 10.2 mm | 1 |
| C2–C5 | 22 µF / 10 V X5R | 0805 | 4 |
| C6–C20 | 100 nF / 16 V X7R | 0402 | 15 |
| R1–R7 | 5.1 kΩ ±1 % | 0402 | 7 |
| R8, R9 | 100 kΩ ±1 % | 0402 | 2 |
| R10 | 4.7 MΩ ±5 % | 0402 | 1 |
| R11 | 47 Ω ±1 % | 0402 | 1 |
| DNP | D1 (S1A, SMA), D2 (low-leakage ESD, 0402), D3 (1N5819HW, SOD-123), C21 (0402), J2/J3/J4 (THT pads), LK1 (cuttable copper link) | — | 0 |
| Free | TP1–TP11 exposed pads, H1/H2 mounting holes, PAD_S / PAD_G touch copper | — | 0 |

**50 placements. 16 unique BOM lines. ~204 solder joints. Zero THT placements, zero hand-solder operations.**

### 6.1 Net list

| Net | Members |
|---|---|
| `VBUS_RAW` | J1.A4, J1.B4, J1.A9, J1.B9, U4.5, F1.1 |
| `VBUS_F` | F1.2, Q1.2(S), C7.2, D3.K(DNP), TP11 |
| `+5V` | Q1.3(D), C2.1, U3.1, U3.3(EN), LK1.1, C21.2(DNP) |
| `LED_5V` | LK1.2, D1.K(DNP), C1.+, C5.1, U2.5, C6.1, LD1.1 … LD11.1, C10.1 … C20.1, TP1 |
| `+3V3` | U3.5, C3.1, C4.1, C9.1, U1.3V3, R4.1, R5.1, R6.1, R9.1, TP2 |
| `GND` | everything below, both pours, U1 thermal pad |
| `GATE` | Q1.1(G), R8.1, C7.1, C21.1(DNP) |
| `EN` | U1.EN, R9.2, C8.1, TP10 |
| `CC1` / `CC2` | J1.A5 + R1.1 / J1.B5 + R2.1 |
| `USB_DP_CONN` / `USB_DM_CONN` | J1.A6 + J1.B6 + U4.3 / J1.A7 + J1.B7 + U4.1 |
| `USB_DP` / `USB_DM` | U4.4 + U1.IO19 / U4.6 + U1.IO18 |
| `LED_DATA_3V3` | U1.IO5, R3.1, U2.2(A) |
| `LED_DATA_5V` | U2.4(Y), R11.1 |
| `LED_DIN1` | R11.2, LD1.4(DIN), TP5 |
| `D_n_n+1` | LDn.2(DOUT) → LDn+1.4(DIN), n = 1…10 |
| `LD11_DOUT` | LD11.2, TP7 |
| `TOUCH_GPIO` | U1.IO3, R10.1, R7.1, D2.A(DNP) |
| `TOUCH_SENSE` | R7.2, J2.1, TP6, → centre bridge → J3.1, `PAD_S` |
| `BOOT_N` | U1.IO9, R6.2, SW1.1, SW1.2 |
| `STRAP2` / `STRAP8` | U1.IO2 + R4.2 / U1.IO8 + R5.2 |
| `UART_TX` / `UART_RX` | U1.IO21 + TP8 / U1.IO20 + TP9 |

`TOUCH_SENSE` is one continuous net in the attached (default) configuration; J2 and J3 are unpopulated pads either side of the break, in parallel with the copper crossing the centre bridge.

### 6.2 Block A — USB-C input

```
J1.A4/B4/A9/B9  VBUS -> VBUS_RAW
J1.A1/B1/A12/B12 GND -> GND        J1.SH1..SH4 -> GND (direct, no 1M||4n7 network)
J1.A5 CC1 -> CC1                   R1  5.1k  CC1 -> GND
J1.B5 CC2 -> CC2                   R2  5.1k  CC2 -> GND
J1.A6 + J1.B6 -> USB_DP_CONN       (tie under the connector body)
J1.A7 + J1.B7 -> USB_DM_CONN
U4  USBLC6-2SC6:  1 -> USB_DM_CONN, 6 -> USB_DM, 3 -> USB_DP_CONN, 4 -> USB_DP,
                  2 -> GND, 5 -> VBUS_RAW
F1  PPTC 2A/4A:   VBUS_RAW -> VBUS_F
```

**Two separate 5.1 kΩ Rd resistors, one per CC pin.** A single resistor bridging CC1 to CC2 is the single most common USB-C sink error and produces a port that is dead in one cable orientation.

**A6/B6 and A7/B7 must be shorted on the PCB.** The 16-pin part brings D+ and D− out once per orientation. Short them under the connector body with a short trace, not by routing both pairs separately to the ESD array.

**Shield tied directly to GND.** The product is a floating, adapter-powered object with one connector and no second ground reference, so there is no ground loop to break. A direct tie is what gives the shield an ESD path, and it costs zero parts.

**No 27 Ω series resistors on D±.** The ESP32-C3 USB Serial/JTAG reference design connects D+/D− directly; the on-die drivers are already source-terminated.

**Do not delete USB data.** It is the only recovery path when an OTA bricks a unit, and unlike a Pico W carrier there is no second connector to fall back on. Route as a 90 Ω differential pair, matched within 5 mm, over unbroken ground, no vias, no stubs.

**The USBLC6's VBUS pin is an ESD clamp, not a power TVS.** It will not survive a sustained overvoltage. That is the correct level of protection for a 5 V USB sink that never negotiates PD, but do not describe the board as overvoltage-protected. Reverse polarity is a separate matter, handled in §6.3.

**No barrel jack.** It adds a connector, reverse-polarity exposure, and an ORing problem (two Schottkys wasting 0.35 W, or a P-FET mux). J4 — a DNP 2-pin 2.54 mm footprint downstream of F1 with a DNP series Schottky D3 — lets a bench user inject 5 V without a respin, for zero cost, and D3 having no bypass link is deliberate: the aux path is unusable unless the user fits the diode, which is what restores reverse-polarity protection. **The README must say: use USB-C or J4, never both.** They hard-parallel.

### 6.3 Block B — inrush soft-start

```
Q1  AO3401A   (SOT-23: 1 = G, 2 = S, 3 = D)
Q1.2 (S) -> VBUS_F        SOURCE ON THE INPUT SIDE
Q1.3 (D) -> +5V           drain to load
Q1.1 (G) -> GATE
R8  100k    GATE -> GND
C7  100nF   GATE -> VBUS_F     i.e. GATE-TO-SOURCE, not gate-to-GND
C21 DNP 100nF  GATE -> +5V     Miller cap, deterministic dV/dt if needed
```

Two things here are the most commonly copied schematic errors in this circuit, so they are called out explicitly:

**The capacitor goes gate-to-SOURCE.** If it goes gate-to-GND, at power-up the gate sits at 0 V while the source rises to 5 V, V_GS is −5 V immediately, the FET turns fully on, and there is **no soft-start whatsoever.**

**The source is on the INPUT side.** A P-channel body diode has its anode at the drain and cathode at the source. Source-on-load makes the body diode conduct straight from VBUS into 470 µF the instant the connector mates, and the gate RC then only decides when the channel enhances and drops the 0.5 V diode to 50 mV. You get the full uncontrolled inrush the part was added to prevent. Source-on-input reverse-biases the body diode for load current, so the FET must actively enhance and the gate RC genuinely controls turn-on.

The trade is that reverse polarity is not blocked. That is acceptable because reverse polarity is **physically unreachable** on the shipped board — USB-C cannot present reversed VBUS, and the only exposure is J4, a DNP footprint a bench user must deliberately populate and then mis-wire, which D3 covers. Inrush, by contrast, happens on every unit on every plug-in.

If you want both in the populated path, the cheapest correct answer is two AO3401A back-to-back, common-drain, gates tied — same part number so no new BOM line, +$0.03, +1 placement, +60 mΩ. I do not recommend it: it spends money and dropout headroom protecting a footprint that is empty by default.

**Turn-off behaviour matters too.** On unplug, C1 discharges into the load; with LEDs off and the MCU drawing ~45 mA from 5 V, 470 µF falls below the LDO dropout in about 35 ms. A clean, fast rail collapse is what makes unplug/replug the documented recovery, because `boot.py:84` distinguishes `PWRON_RESET` from a crash. No bleed resistor needed.

### 6.4 Block C — 3.3 V regulation

```
U3  AP2112K-3.3TRG1  (SOT-23-5)
U3.1  VIN   -> +5V
U3.2  GND   -> GND
U3.3  EN    -> +5V        <-- TIED TO VIN. NOT to the LDO's own output.
U3.4  NC    -> no connect
U3.5  VOUT  -> +3V3
C2  22uF 0805   +5V  -> GND   (input,  <=3 mm from U3.1)
C3  22uF 0805   +3V3 -> GND   (output, <=3 mm from U3.5)
```

**EN goes to VIN, not to VOUT.** This is worth a paragraph because bootstrapping EN to the LDO's own output is a plausible-looking mistake that produces a 100 %-correlated dead batch: at power-up VOUT is 0 V, so EN is 0 V, so the regulator stays disabled, so VOUT never rises. There is no mechanism to break the latch. AP2112K, ME6211, RT9013 and SGM2212 all specify EN as a high-impedance logic input with **no internal pull-up to VIN** — their datasheets give EN→VIN as the always-on connection. If you want the option of gating the rail later, lay a DNP 0 Ω from EN to a control net; the copper default stays EN→VIN.

**Dropout budget, honestly.** Worst realistic case — 5 V charger at −10 %, long cheap cable, LEDs at full white:

```
4.50 V source
-0.24 V  cable + connector, 0.2 ohm @ 1.2 A
-0.06 V  F1 PPTC, 0.05 ohm
-0.07 V  Q1, 60 mohm
= 4.13 V at U3.1
minus the 0.379 V transient droop from a simultaneous LED turn-on (worst instant): 3.75 V
```

Against that, use the datasheet **maximum** dropout over temperature, not typical. AP2112K is specified at ~400 mV max at 600 mA, so at 350 mA it is comfortably under 300 mV → ≥3.45 V out, and the ESP32-C3's brownout detector sits far below that. ME6211's typical 250 mV at 350 mA looks better on paper but its max-over-temperature figure is thinner, and AMS1117 needs ~0.8 V and brownouts outright — and it is **SOT-223, so it is not a drop-in fallback.** Pin-compatible SOT-23-5 alternates that *are* drop-ins: ME6211C33M5G, RT9013-33GB, SGM2212-3.3. Avoid XC6206P332MR (200 mA — too small for the 350 mA TX burst).

Add "scope 3V3 at TP2 during a Wi-Fi TX burst with the string at full white, from a 4.5 V source through a 2 m cheap cable" to Stage 1. That single measurement settles the whole argument.

**Dissipation:** (5.0 − 3.3) × 0.10 A = 0.17 W continuous. SOT-23-5 with ~100 mm² of pour on the GND pin, θ_JA ≈ 180 °C/W → ΔT ≈ 31 °C, junction ~70 °C in a 39 °C interior. The 350 mA burst adds 0.6 W for 2 ms against a package time constant of seconds — thermally invisible.

### 6.5 Block D — MCU module

```
U1  ESP32-C3-MINI-1-N4
3V3   -> +3V3        GND -> GND (ALL GND pins, including the thermal pad)
EN    -> EN          R9  100k  EN -> +3V3      C8  100nF  EN -> GND
IO5   -> LED_DATA_3V3      <-- LED_PIN = 5, unchanged from config.py:36
IO3   -> TOUCH_GPIO        <-- TOUCH_PINS = [3]
IO2   -> STRAP2   R4 5.1k -> +3V3     (mandatory: IO2 low at reset = invalid, no boot)
IO8   -> STRAP8   R5 5.1k -> +3V3     (required for download boot)
IO9   -> BOOT_N   R6 5.1k -> +3V3, SW1 to GND
IO18  -> USB_DM        IO19 -> USB_DP        (fixed by silicon)
IO20  -> UART_RX (TP9) IO21 -> UART_TX (TP8)
C4  22uF 0805  +3V3 -> GND   <= 5 mm from the module's 3V3 pin
C9  100nF 0402 +3V3 -> GND   <= 2 mm from the module's 3V3 pin
```

**Pin choices, and why each one:**

| Signal | Pin | Reason |
|---|---|---|
| LED DIN | **IO5** | Deliberately identical to `config.py:36`. `config.py` is never OTA'd (`boot.py:5`) and `hardware_test.py:65` hard-codes `LED_PIN = 5`. Keeping GPIO5 means one golden `config.py` flashes to all 100 units. IO5 is a plain GPIO on the C3 — not strapping, not flash, high-Z at reset |
| Touch sense | **IO3** | GPIO12–17 on the C3 are bonded to the internal SPI flash and are not available on MINI-1, so the current `[12]` cannot survive. IO3 is a plain non-strapping GPIO. It does **not** need to be ADC-capable — the `config.py:47` comment claiming "raw ADC" is false; `touch.py:50-66` is pure digital GPIO timing |
| BOOT / straps / USB / UART0 | IO9 / IO2, IO8 / IO18, IO19 / IO20, IO21 | Fixed by silicon |

**C4 is a fourth 22 µF beyond the two the LDO needs, and it earns its $0.02.** A 350 mA, ≤2 ms 802.11b TX burst into an LDO 10 mm away is the single most common cause of "the module resets whenever it transmits". C4 supplies the burst locally; C3 refills C4. Same BOM line, one extra placement, no setup cost.

**R9 = 100 kΩ on EN is coupled to Q1's soft-start and must not be consolidated into the 5.1 kΩ line.** τ_EN = 10 ms against a rail that itself ramps over 10–15 ms means EN lags the rail throughout and crosses ~2.48 V about 30–35 ms after mate, comfortably after the rail is flat. With 5.1 kΩ (τ = 0.5 ms) EN tracks the ramping rail closely and can release the chip while VDD is still ~2 V, producing a brownout-reset loop on plug-in. 100 kΩ is already on the BOM for R8, so it costs nothing. If Stage 1 shows spurious resets, swap to 10 kΩ — one BOM line, not a respin.

**Antenna keep-out is a schematic-level instruction, not a layout detail.** No copper on any layer inside the datasheet keep-out; nothing — pours, traces, the 470 µF body, a metal screw or heat-set insert — within 8 mm of the antenna region. Violating this forfeits the modular approval, which is the entire reason the module was chosen. It is also why 2 layers is sufficient: you are not laying out an antenna.

> **Uncertainty, stated rather than papered over.** Connections above are by **pin name**, which is what the KiCad symbol carries. I do not have the ESP32-C3-MINI-1 numeric pad map to the standard required for a first-article board and will not invent it. Before layout, cross-check every name against Table 3 "Pin Definitions" in the datasheet and use Espressif's official symbol/footprint. Also verify the strapping table and confirm nothing inside the module already pulls IO2 or IO8 — if it does, delete R4 and/or R5. This is the one place the resistor consolidation could produce dead boards rather than saved pennies.

### 6.6 Block E — level shift and the LED chain

```
U2  SN74AHCT1G125DBVR (SOT-23-5)
U2.1 OE_n -> GND       ACTIVE LOW. Tie to GND to enable the output.
U2.2 A    -> LED_DATA_3V3
U2.3 GND  -> GND
U2.4 Y    -> LED_DATA_5V
U2.5 VCC  -> LED_5V    <-- downstream of LK1/D1, same rail as the LEDs
C6  100nF  LED_5V -> GND      <= 2 mm from U2.5
R3  5.1k   LED_DATA_3V3 -> GND      <= 5 mm from U2.2
R11 47R    LED_DATA_5V -> LED_DIN1  <= 5 mm from U2.4

for n = 1..11:
   LDn.1 (VDD) -> LED_5V ;  LDn.3 (VSS) -> GND ;  100nF directly at LDn.1
LD1.4 (DIN) <- LED_DIN1 ;  LDn.2 (DOUT) -> LDn+1.4 (DIN) ;  LD11.2 -> TP7 only
```

**U2's VCC is on `LED_5V`, downstream of the hedge link — not on `+5V`.** In the normal configuration the two nets are the same node through a 2.5 mΩ copper link, so nothing changes. In the hedge configuration (link cut, series diode fitted) powering the buffer from `+5V` would drive DIN to ~4.85 V into an LED whose own V_DD is 4.2 V, forward-biasing LD1's input protection diode into its rail for the whole 422 µs frame, sixty times a second. R11 limits it to a few mA, which is enough for continuous substrate injection and, on a bad lot, latch-up. On `LED_5V` the buffer runs at the same 4.2 V as the LEDs: V_OH ≈ 4.1 V against V_IH = 0.7 × 4.2 = 2.94 V, still +1.16 V of margin and no overdrive.

**R3 is the floating-input pull-down, and it is the cheapest reliability part on the board.** Before MicroPython runs — through the C3's boot ROM, the MicroPython init, and `main.py`'s import chain — IO5 is a high-Z input. An AHCT input left floating near mid-rail self-oscillates, draws crowbar current through both output transistors, and can clock a garbage frame into the string, producing a flash of random colour at every power-up and every one of the frequent reboots (daily at `main.py:431`, offline at `main.py:667-674`, crash at `main.py:876-894`). $0.001 from an existing value.

**R11 = 47 Ω, not 330–470 Ω.** Two different jobs get conflated in the usual advice. The 330–470 Ω folklore value exists for strips on flying leads; here the U2→LD1 run is ~12 mm and never leaves the PCB, and 470 Ω into LD1's ~15 pF plus ~10 pF of trace would add 12 ns of RC for nothing. The real job is damping: AHCT output impedance is 15–25 Ω into a microstrip that on 1.6 mm FR4 at 0.30 mm width is nearer 120 Ω than the 70–90 Ω usually assumed. At a ~3 ns edge rate the critical length is ~75 mm and this trace is 12 mm, so it is **electrically short and termination is not actually required** — the exact value does not matter. Keep 47 Ω anyway: it costs nothing, it damps whatever the trace does do, and it limits U2's output current into LD1's input ESD diode if 3V3 comes up while the 5 V rail is still on its 10 ms ramp.

**Inter-LED DOUT→DIN hops get no series resistor.** Each SK6812 fully regenerates from its own shift register; a resistor there only degrades the edge.

**Part substitution is the number one way to get this circuit wrong.** Mark the BOM line "AHCT/HCT ONLY — DO NOT SUBSTITUTE" and disable auto-substitution at the assembler.

| Part | Verdict |
|---|---|
| `SN74AHCT1G125DBVR` (LCSC C7484), `74HCT1G125GW` | Correct. Pin-identical, TTL thresholds |
| `SN74AHC1G125DBVR` (LCSC **C7468**) | **Wrong.** AHC at 5 V has V_IH = 3.5 V and fixes nothing. One letter, and the whole design. The LCSC codes differ by two digits |
| `74LVC1G125` at 3.3 V | **Wrong.** Outputs 3.3 V and fixes nothing |
| `SN74LVC1T45DBVR` | **Not pin-compatible** — SOT-23-6. Do not plan on it as a drop-in |
| `74AHCT1G126` | Works, but **OE is active HIGH — tie pin 1 to VCC, not GND** |

**Rejected alternatives to the buffer, with the numbers:**

- *Schottky in the LED V_DD path:* V_F collapses to 0.25 V at the 0.1 A normal operating current → rail 4.7 V → V_IH 3.29 V. The fix evaporates precisely where the lamp lives 99 % of its life. Reject.
- *Silicon diode:* works (rail 4.15–4.35 V), but burns 0.75 W at 0.9 A in one package, costs ~15 % brightness, and shifts the white point of a *lamp* — the W die dims disproportionately. DNP hedge only.
- *Dedicated 4.3 V LED buck:* more parts, more area, a switcher next to a certified antenna, for more money than a $0.11 buffer. Reject.
- *First LED as a sacrificial buffer:* LED1's input still sees the same out-of-spec 3.3 V, and if it mis-latches it corrupts the whole downstream chain. You buy twelve unreliable LEDs instead of eleven. Reject.

**The hedge, kept for $0.00.** `LK1` is a cuttable copper link — a 0.4 mm-wide, 2.0 mm-long neck between `+5V` and `LED_5V` with the soldermask opened and a silkscreen `CUT -> D1` scissors mark — bridging a DNP **SMA (DO-214AC)** land pattern. If the AHCT part ever has to be omitted, cut the link and hand-fit an **S1A**. Zero placements, zero BOM lines, ~15 mm² of head area.

> Do **not** use 1N4148W for this. It is a 300 mA part and the string draws 0.89 A; it would fail short (the level-shift fix silently disappears) or open (dead lamp). And a Schottky is wrong for the same reason it is wrong as a primary fix. The land pattern is SMA, not SOD-123. Caveat for whoever ever uses it: an S1A at 0.89 A drops ~1.0 V and dissipates 0.9 W, brightness is down ~15 %, the white point shifts, and the package gets hot. It is an emergency hedge, not an alternative design.

The 0.4 mm link neck carries 0.89 A over 2.5 mm — 5 squares × 0.494 mΩ = 2.5 mΩ, 2.2 mV, 2 mW, with an ~8 °C rise. It must be 0.4 mm, not the full bridge width, so a scalpel can cut it in two or three passes.

**LD11's DOUT goes to a test pad and nowhere else.** If TP7 toggles during a frame, all eleven shift registers latched and passed data — the whole chain verified with one scope probe.

**Data flows LD1 → LD11, head end → tab end.** Firmware index 0 is the first LED to receive data, so `REVERSE_LEDS = False` is correct and becomes permanently correct. It must still **exist as a symbol** in `config.py` — see §8.1.

> **Verify before layout:** SK6812 5050 pad assignment (I have it as 1 = VDD, 2 = DOUT, 3 = VSS, 4 = DIN) against the exact LCSC part's drawing. The 4-pad 5050 footprint is shared with WS2812B but pad-1 orientation and internal pin order have varied between clone lots, and a rotated LED row is a scrap panel.

### 6.7 Block F — touch front end

```
R10 4.7M   TOUCH_GPIO -> GND         at U1, <= 5 mm from IO3
R7  5.1k   TOUCH_GPIO -> TOUCH_SENSE at U1, <= 5 mm from IO3
D2  DNP 0402  TOUCH_GPIO -> GND      low-leakage ESD, empty by default
PAD_S  SENSE electrode, tab, under soldermask
PAD_G  GND return electrode, tab, alongside PAD_S under the same overlay
```

The circuit is small; the reasoning is in §7.5, where the geometry lives. Three schematic-level points:

**R10 sits on the GPIO side of R7, not the sense side.** Same measurement (R7 at 5.1 kΩ is three orders of magnitude below R10, so the two nodes track within ~180 ns of each other against a ~170 µs measurement), but if the sense trace is ever cut or opens, the GPIO still has a defined discharge path, and it puts R7 between the pad and everything fragile, which is the correct R-then-clamp ESD ordering.

**Both resistors live on the MAIN board, never on the tab.** This is a fail-safe, not a convenience. If R10 were on the tab, a builder who snaps it off and does not immediately rewire leaves IO3 floating, and `touch.py` then runs its wait to the safety cap on every main-loop iteration — turning a sub-millisecond measurement into tens of milliseconds inside a 16 ms frame, producing visible stutter and watchdog pressure. With R10 on the main board, an unwired snapped board reads a short stable discharge and simply never triggers. Fails silent, costs nothing.

**D2 stays empty, and if you ever populate it, the usual advice is not sufficient.** The pad is under soldermask *and* behind ≥0.8 mm of plastic, so there is no galvanic path and ESD arrives as heavily attenuated capacitive coupling that R7 and the C3's internal clamps handle. If field failures ever appear, note that on a 4.7 MΩ node the discharge current at 3.3 V is only 700 nA — a general ESD diode with 100 nA–1 µA of reverse leakage is the same order as the signal current and will distort or defeat the measurement. **Specify I_R ≤ 10 nA at 3.3 V in addition to C_j ≤ 1 pF, and re-baseline afterwards.** The commonly cited ESD9B5.0ST5G meets the capacitance spec but its leakage is not tight enough to assume.

### 6.8 Test points — eleven exposed 1.0 mm pads, zero cost

| TP | Net | Purpose |
|---|---|---|
| TP1 | `LED_5V` | rail voltage, droop under load |
| TP2 | `+3V3` | LDO output, dropout margin under Wi-Fi TX |
| TP3 / TP4 | `GND` | head reference / tab-end reference |
| TP5 | `LED_DIN1` | post-buffer data — verify the 5 V swing and bit timing **here**, not at IO5 |
| TP6 | `TOUCH_SENSE` | scope the discharge waveform directly, attached or pigtailed |
| TP7 | `LD11_DOUT` | whole-chain continuity |
| TP8 / TP9 | `UART_TX` / `UART_RX` | ROM bootloader console at 115200 — the fallback when USB enumeration fails |
| TP10 | `EN` | reset stimulus; replaces the deleted button |
| TP11 | `VBUS_F` | current probe for the Stage 1 inrush measurement |

J2 doubles as a SENSE + GND probe point at the far end.

---

## 7. Layout and mechanical

### 7.0 Board drawing

EM-15 rev B, drawn to scale

Top view, to scale. LED centres, pitch, pad extents, break slot, mounting holes and the copper
bands are the specified values from the sections below. Head-section parts are indicative — this
design fixes their nets and clearances, not their exact x/y, which falls out of routing.

### 7.1 Outline and cross-section

**282.0 × 20.0 × 1.6 mm, 2 layer, 1 oz, single-sided SMT, white mask, black silkscreen.**

The board was narrowed from 24.0 mm to 20.0 mm. The reason is not cost, though it saves ~$0.15/board of area: a 24 mm board sitting 5 mm below the axis of a 26 mm bore consumes exactly 24.000 mm of available chord, leaving **zero** for the printed spine that has to capture both long edges. See §7.3 for the inequality that must hold.

Cross-section through the lit zone, y measured from the y = 0 long edge:

| y (mm) | Top layer | Bottom layer |
|---|---|---|
| 0.40 – 8.20 | **5 V pour**, 7.8 mm → LED anodes | solid GND |
| 8.50 – 13.50 | LED bodies (5050), centre y = 11.00 | solid GND, ≥4 thermal vias per LED |
| 13.60 – 17.00 | **GND pour**, 3.4 mm; 11 × 100 nF; DOUT→DIN chain | solid GND |
| 17.30 – 19.30 | guard 0.5 ‖ gap 0.35 ‖ **SENSE 0.30** ‖ gap 0.35 ‖ guard 0.5 | solid GND (the shield) |
| — | 0.40 mm copper setback at both long edges | same |

Putting SENSE on the far side of the LED band from the 5 V pour is a deliberate change from the obvious arrangement. It gives **9.1 mm of separation** between the high-impedance sense trace and the 0.89 A switching rail, with a grounded pour and the LED band in between, instead of the ~3 mm that a shared edge forces. It removes the one credible noise-coupling path in the design at zero cost, and it means no filter capacitor is needed on the sense node.

> If you ever do need to filter that node, **do not fit 1 nF.** At 4.7 MΩ, 1 nF is a 4.7 ms measurement inside a 16 ms frame. Size any filter as a fraction of the ~36 pF already there: 10–22 pF adds 30–60 % to the baseline (calibrated away at boot, delta unchanged) and costs well under a millisecond.

Guard rails are GND-connected and stitched to the bottom plane with vias every 10 mm. The SENSE net is **top layer only, for its entire length, with zero vias** — each via adds ~0.5 pF and a plating-void failure mode on the one net that cannot tolerate an intermittent.

### 7.2 LED geometry

Pitch **16.66667 mm** exactly (60 LED/m). All eleven at **y = 11.000 mm**.

| n | 1 | 2 | 3 | 4 | 5 | 6 | 7 | 8 | 9 | 10 | 11 |
|---|---|---|---|---|---|---|---|---|---|---|---|
| x (mm) | 64.000 | 80.667 | 97.333 | 114.000 | 130.667 | 147.333 | 164.000 | 180.667 | 197.333 | 214.000 | 230.667 |

Span LED1 → LED11 = **166.667 mm**. Note this is 166.67, not 167.7 — ten gaps, not eleven.

End margins are exactly half a pitch (8.333 mm), which puts the **lit zone at x 55.67 → 239.00, i.e. 183.33 mm.** Make the diffuser that length. Make it 166.67 and the two end LEDs sit at the very edge and look clipped.

Each LED's 100 nF sits at (x_n + 3.40, y = 15.50), long axis along y, with its own via straight to the bottom plane.

### 7.3 Optics and the enclosure fit

**16.667 mm is a wide pitch.** The lamp reads as an even line only if the diffuser stands off far enough — rule of thumb for a high-haze opal is 0.7–1.0 × pitch, so 12–17 mm here.

The geometry is forced by the tube. For a bore of radius r, the chord at height z is `2*sqrt(r^2 - z^2)`, and the following must hold:

```
chord(z)  >=  board_width + 2 x spine_wall + 0.6 mm assembly clearance
```

**Specified: 30 mm OD × 2.0 mm wall opal tube (26.0 mm bore), board mounted at z = −4.50 mm, LEDs facing the far wall.**

```
chord(-4.5) = 2*sqrt(13.0^2 - 4.5^2) = 24.39 mm
board 20.00 + 2 x 1.80 spine wall = 23.60 mm      clearance 0.79 mm  OK
LED lens top at z = -4.5 + 1.6 = -2.9
standoff to far wall = 13.0 - (-2.9) = 15.9 mm = 0.95 x pitch
```

**The diffuser material matters more than the standoff.**

| Property | Requirement |
|---|---|
| Haze | **≥85 %** |
| Total transmission | 40–60 % |
| Material | Opal PMMA (best diffusion per unit cost) or opal PC (tougher) |
| Length | ≥190 mm, covering at minimum x 55.67 → 239.00 |
| Reject | clear, surface-etched "frosted", or sandblasted acrylic — these are **low-haze** and show eleven distinct dots at any standoff under ~30 mm |

What the user sees if they get it wrong, and this belongs in the README verbatim:

- ≥15 mm with high-haze opal: a clean, even line.
- ~10 mm with opal: faint scalloping at a glancing angle.
- ≤5 mm, or any low-haze cover under 30 mm: **eleven distinct dots.**

This is not a defect of the board; it is a property of the 60 LED/m pitch. A real 60/m strip looks like dots too unless deeply diffused.

**Rejected optical options, with costs.** Milled slots between LEDs help *edge-lit* designs where light travels through the substrate — here the LEDs emit normal to the board, so slots would remove copper (thermal), weaken a 282 mm strip (mechanical), and buy nothing. An acrylic light pipe is $2.00–3.50 and needs ±0.3 mm alignment to eleven LEDs. Per-LED printed reflector cells are actively harmful — cell walls sharpen the boundary between LEDs and make scalloping *worse*. White soldermask plus a white printed spine is the cheapest optical gain available: 10–20 % more light out for $0.10 and a filament choice.

### 7.4 Mechanical stack and mounting

```
                     +-------- opal tube, 30 OD x 26 ID x 220 mm --------+
   +----------+      |                                                   |   +---------+
   |   BASE   |======|   PCB in printed white spine, z = -4.5            |===| TOP CAP |
   | (printed)|      |   LEDs facing UP toward the far wall              |   | + flat  |
   |  head    |      +---------------------------------------------------+   | TOUCH   |
   | x 0->56  |                     x 56 -> 240                              | FACE    |
   +----------+                                                              | x250-282|
     USB-C <-
```

| Part | Specification |
|---|---|
| **Base** | Printed. Internal cavity ≥58 × 22 × 14 mm (14 mm depth clears the 10 mm electrolytic plus board and tolerance). Two M2.5 bosses at H1/H2. **No metal within 8 mm of the antenna region** — use plastic self-tapping M2.5 × 6 screws, or heat-set inserts only at H1/H2, which are 27 mm away. A Ø3.5 mm access hole aligned to SW1, labelled `BOOT`, reachable with a paperclip. A cable clamp: a 3.2 mm channel pinched to 2.8 mm capturing the jacket 15 mm behind the plug, closed by the base lid, zero parts |
| **Spine** | Printed channel, white PETG or PLA, **1.80 mm slot engaging 2.00 mm of each long board edge**, outer width 23.60 mm, running **x 56 → 240 only** — it must never reach the head (antenna) or the tab. Print in two 100 mm halves with a lap joint if the bed is short. Doubles as the reflector. A 2.5 × 2.5 mm wire channel on the y = 0 side carries the pigtail in the snapped configuration, as far from the 5 V pour as the geometry allows |
| **Tube** | Opal, 30 OD × 2.0 wall × 220 mm, spec per §7.3 |
| **Top cap** | Printed, housing the 31.25 mm tab. **It is not a round continuation of the tube.** It carries a locally flat, raised **touch face** — see §7.5 |
| **H1, H2** | Ø2.70 NPTH at (4.50, 4.50) and (4.50, 15.50), 0.50 mm copper clearance both layers, M2.5 pan head Ø4.7 max |

H1 and H2 flank the USB-C receptacle deliberately: **the axial force from a yanked cable passes into the screws, not into the connector's solder joints.** Together with the THT shield tabs, a base aperture that the plug body bottoms against (receptacle mating face 0.5 mm proud), and the cable clamp, that is four independent strain-relief measures, all free or near-free.

**No mounting holes anywhere in the lit zone** — they would collide with the row and puncture both pours. The two long edges captured in the spine handle the flex of 282 mm of 1.6 mm FR4, which is why 1.6 mm is specified and 1.2 mm must not be substituted.

**No mounting holes on the tab either.** There is no room alongside the pad pair, and a metal screw within 8 mm of the pad would wreck the baseline. Fix a snapped-off tab with double-sided foam tape, which conveniently also provides the standoff if the pad is mounted copper-side-in.

### 7.5 Touch pad — geometry, and an honest account of the margin

This is the least-certain subsystem in the design. It is also the one with the most no-respin escape hatches. Both facts are stated here rather than buried.

#### What the firmware does

`touch.py:50-66` drives the pad node to 3.3 V for 10 µs, floats the pin, and waits for it to fall through the input's logic-low threshold, discharging entirely through the external pull-down. `_is_currently_touched()` compares the result against a baseline auto-measured at boot. Two properties of that follow:

```
t_total = k * R * C_total       <- pad self-C, trace, guard, wire: all live HERE
dt      = k * R * dC_finger     <- depends ONLY on the electrode geometry and the overlay
```

Since the baseline is re-measured on the board at every boot, **wire and trace capacitance shift the baseline, which is calibrated away, and do not shift the delta at all.** That is what makes one threshold cover both tab configurations, and it is why the guarded channel is specified with GND on both sides *and* a solid plane beneath rather than following the usual "minimise parasitics" instinct. On this algorithm, parasitic capacitance to ground is free.

#### Two corrections that change the numbers

**(a) The constant is not 0.7·R·C.** That is the ln 2 half-way figure. The wait ends when the input crosses its logic-low threshold, so `k = ln(V_DD / V_T)`. But V_T is *not* the datasheet `V_IL(max) = 0.25 V_DD` either — that is the guaranteed-low limit, not the actual switching point, which sits somewhere between 0.83 V and 2.48 V and varies part to part and with temperature. `k` therefore ranges from 1.39 down to 0.72, nearly a factor of two, **and it scales the delta, which per-boot baseline calibration does not remove.** The design's central "one shipped constant" claim would fail on that alone.

The fix is structural and costs nothing: **compare against a fraction of the baseline, not an absolute count.** `k`, R tolerance, CPU clock and bytecode speed all appear identically in numerator and denominator and cancel exactly, leaving only ΔC/C_total. See §8.3.

**(b) The finger's return path is not mains earth.** The usual justification — "a human body has 100–200 pF to earth, so it is effectively a short" — is false for the supply this lamp ships with. A $3.50 5 V USB-C adapter is a 2-prong Class II part with no earth pin; board GND floats, coupled to earth only through a Y-capacitor (1–2.2 nF if fitted, often omitted) or transformer interwinding capacitance (~10–30 pF). On a power bank or a laptop running on battery there is no earth path at all, and ΔC collapses by 57–80 %. The lamp would work on the bench and be unresponsive in a user's hand.

The fix is a **split electrode pair**: SENSE and a GND return, side by side, both under the same overlay and both inside the fingertip footprint, so the finger bridges sense → finger → GND *locally*. It costs nothing — it reuses guard copper and an existing net. It roughly halves the best-case ΔC and removes the supply dependency entirely, which is a good trade for a product you post to friends.

#### Geometry

Tab is 20.0 mm wide, x 250.75 → 282.00 (31.25 mm long). All top layer, **covered by soldermask** (prevents corrosion and surface leakage; 25 µm of mask is a 1.7 % series-dielectric effect, negligible). **No copper on either layer beneath either electrode.**

| Element | Extent |
|---|---|
| `PAD_G` (GND return) | x 254.0 → 279.0, y 1.20 → 9.20 → 200 mm² |
| gap | 1.40 mm |
| `PAD_S` (SENSE) | x 254.0 → 279.0, y 10.60 → 18.60 → 200 mm² |
| Guard rail | 1.00 mm GND, along the y = 19.3 edge and the free end at x = 280.5, 1.50 mm clearance to `PAD_S` |
| Bottom-layer mirror ring | same U, stitched to the top ring with Ø0.30 vias every 8 mm; bare FR4 inside |

Equal areas are correct: for two electrodes in series the coupling `C ∝ s(A−s)/A` maximises at `s = A/2`.

#### The numbers, with their uncertainty stated

A fingertip covers roughly 150 mm², split across the pair. Through a **1.0 mm** overlay at ε_r ≈ 2.9:

```
C_pad-finger  = 8.854e-12 x 2.9 x 75e-6 / 1.0e-3 = 1.93 pF per electrode
series pair   = 1.93/2                           = 0.96 pF        <- FLOATING source, worst case
with an earthed / Y-capped adapter the earth path adds in parallel: 2-4 pF typical

C_total (baseline) = pad self-C to guard ~8 pF + 195 mm guarded trace ~25 pF + pin/R node ~3 pF
                   ~= 36 pF

fraction dC/C_total = 0.96 / 36 = 2.7 %  worst case
                    = 3.0 / 36  = 8.3 %  typical
```

With R = 4.7 MΩ and `k` in its mid-range (~1.0), the baseline is about **170 µs** and the worst-case delta about **4.5 µs**, measured with `utime.ticks_us()` at 1 µs resolution.

**That is 4–5 LSB of margin in the worst case, and I am not going to dress it up as more.** It is workable and it is the honest floor; the typical case is 3–4× better. There are four independent knobs, none of which needs a respin:

| Knob | Effect | Cost |
|---|---|---|
| Thin the cap's touch face from 1.5 → 1.0 → 0.8 mm | ΔC ∝ 1/d: +50 %, +88 % | Print setting |
| R10 4.7 MΩ → 10 MΩ | Doubles absolute µs (does **not** change the fraction) | 0402 stuffing value |
| Burst timing: N charge/discharge cycles between two `ticks_us` reads | N× absolute µs, same fraction | Config constant, costs N × 170 µs of frame time |
| `TOUCH_SAMPLES` min-of-N | Lowers the noise floor | ~0.2 ms per extra sample |

**Why 4.7 MΩ and not the 22 MΩ that would look better on paper.** The pull-down current at the decision point is `V_T / R`. At 22 MΩ that is 45–50 nA — the same magnitude as the ESP32-C3's guaranteed GPIO input leakage. If a given part leaks *into* the node, the node asymptotes at `I_leak × R` = 50 nA × 22 MΩ = 1.1 V, above the low threshold; the pin never reads 0, the wait runs to its safety cap on every call, and a sub-millisecond measurement becomes tens of milliseconds inside a 16 ms loop. The lamp stutters and touch is permanently dead. Because leakage is part-to-part and temperature dependent, that hits a *fraction* of the batch — the worst possible distribution, since one good prototype proves nothing. At 4.7 MΩ the asymptote is 0.24 V, comfortably clear, and the rate error is ~20 % rather than ~100 %. **Stage 1 must measure the settled DC voltage on the pad node with the pin floated**; if it is below 0.3 V, 10 MΩ is available for the extra absolute margin.

Also do not go above ~10 MΩ for a second reason: FR4 surface leakage with flux residue at 60 % RH is 10⁸–10⁹ Ω and starts to be a meaningful fraction of R. Use standard cleaning; do not conformally coat unless Stage 1 shows humidity drift.

#### The overlay, and the enclosure change it forces

**This is the part that a round tube quietly breaks.** The pad is top-layer copper in the board plane at z = −4.5, facing +z. If the top cap simply continued the tube, the nearest surface in that direction would be the inner wall at z = +13.0 — **17.5 mm of air plus 2 mm of plastic**, not 1 mm of plastic. ΔC would fall by more than an order of magnitude and the lamp would never register a touch anywhere on its enclosure. No assembly adjustment fixes that; every unit would have to have its tab snapped and taped to the cap wall, which destroys the whole premise of the attached default.

**Requirement on the top cap: a locally flat, raised touch face that brings 1.0 mm of plastic down onto the pad plane over the full 25 × 17 mm electrode pair.** The cap is printed, so this is a modelling change and costs nothing. Additional rules:

| Rule | Value |
|---|---|
| Overlay thickness over both electrodes | 1.0 mm nominal, **0.8–2.0 mm** allowed |
| Air gap between soldermask and plastic | **≤0.3 mm.** 1 mm of air behaves like ~2.6 mm of plastic (ε_r 1 vs 2.9). Either the face presses the pad, or a 1 mm closed-cell foam pad fills the gap |
| Metal near the pad | **None within 8 mm.** No screw, no insert, no foil |
| Marking | Printed texture or colour change on the touch face so the user knows where to press |

Never expose the copper.

#### The hazard this board does not fix

`touch.py:37` captures the baseline at construction and `main.py:595` re-captures once after MQTT connect. **There is no drift tracking.** A finger resting on the pad during boot — including the daily 17:00 UTC OTA reboot — bakes in a touched baseline and touch stays dead until the next reboot.

Hardware mitigation: the tab is at the **opposite end from the USB connector**, so the hand that plugs the cable in is never on the pad. That helps; it does not close it. The real fix is about fifteen lines of OTA-able firmware (§8.3), and it must ship with the first batch.

### 7.6 The break-away tab

**Mouse bites, not V-score, and this is geometry rather than preference.** A V-groove is cut by a circular blade that must traverse the whole panel edge to edge; it cannot make an interior or partial cut. Our break is an internal separation inside a rectangular outline, so V-score there is not manufacturable at all. Internal routed slots are part of the profiling operation and carry no surcharge.

**Break line at x = 250.000, a 1.50 mm routed slot (x 249.25 → 250.75) across the full 20 mm width, interrupted by three bridges:**

| Bridge | y extent | Width | Mouse bites (Ø0.60 NPTH, drilled on x = 250.000) | Webs | Residual FR4 |
|---|---|---|---|---|---|
| Lower | 2.30 → 4.70 | 2.40 | y = 3.00, 4.00 | 0.40 / 0.40 / 0.40 | 1.20 mm |
| **Centre** | 7.80 → 12.20 | 4.40 | y = 8.70, 11.30 | 0.60 / **2.00** / 0.60 | **2.80 mm** |
| Upper | 15.30 → 17.70 | 2.40 | y = 16.00, 17.00 | 0.40 / 0.40 / 0.40 | 1.20 mm |

**Every web is ≥0.40 mm and every hole edge is ≥0.40 mm from the slot edge.** That is not a detail — a 0.20 mm web (which is what you get if you space three holes evenly across a 3.0 mm bridge) is below standard fab capability *and* below the scale of a single FR4 glass bundle, so those webs are unreinforced resin. They blow out on router exit, the residual cross-section becomes a lottery, and the break force figure becomes meaningless. Worse, a partially fractured bridge that still holds the sense trace across cracked substrate gives an intermittent high-impedance connection on the one net that cannot tolerate one — presenting in the field as touch that works until the lamp is moved.

**The centre bridge is deliberately solid across its middle 2.00 mm** and carries the two crossing conductors. This makes the *attached* configuration — the default, which most builders will ship — genuinely strong.

```
SENSE   y = 9.50, 0.30 mm wide   ->  0.35 mm to the nearest mouse-bite hole edge
GND     y = 10.50, 0.30 mm wide  ->  0.35 mm to the nearest hole edge
gap between them 0.70 mm
```

0.35 mm exceeds JLC's 0.30 mm copper-to-hole minimum. This is a deliberate local exception to the 1.50 mm pour setback: these two traces are sacrificial by design and are knife-cut before the snap.

**Break force — estimated from cross-section and FR4 flexural strength, not measured.**

```
Z = sum(b*h^2)/6 = 5.20 x 1.6^2 / 6 = 2.219 mm^3
M = sigma * Z    = 415 N/mm^2 x 2.219 = 921 N.mm
F at a 25 mm lever = 921/25 = 36.8 N  = 3.8 kgf   (intact, all three bridges)

after nipping the centre bridge (residual 2.40 mm):
Z = 1.024 mm^3, M = 425 N.mm, F = 17.0 N = 1.7 kgf
```

**Hand-snappable at roughly 3.8 kgf over a table edge, comfortably easy at 1.7 kgf after nipping the centre bridge with flush cutters.** No vice, no pliers required. Range across FR4 lots: 2.7–4.6 kgf. **Snap one prototype and measure it before writing a number into the build guide.**

Knife-cutting the two traces is a purely *electrical* operation — it removes 35 µm of copper and contributes nothing to the mechanical break.

#### Keepouts — the snapping-stress question, answered concretely

| Rule | Value | Why |
|---|---|---|
| Component keepout, main side | **15.00 mm** from the slot edge (x ≤ 234.25) | MLCC flex cracking is the failure mode most likely to pass at the assembler and die at the builder, intermittently and nearly undiagnosably |
| Actual nearest component | LED11 pads end at x ≈ 233.2 → **16.0 mm clear**; its 100 nF is *upstream* at x = 234.07 → 15.2 mm clear | |
| Component keepout, tab side | **the entire tab** | Zero components on the tab. Removes the failure mode rather than mitigating it |
| MLCC long-axis orientation | **parallel to the break line (along y)** within 25 mm | All eleven LED bypass caps are along y anyway |
| 0805 and the electrolytic | all in the head, ≥215 mm from the break | Not a factor |
| Copper pour setback | **1.50 mm** from every slot edge and every mouse-bite hole, both layers | Copper tears and lifts pads when snapped |

#### The electrical crossing

**Two plated through-hole pairs, 2.54 mm pitch, Ø1.00 mm drill / Ø1.60 mm pad.**

| Ref | Side | x | y | Nets |
|---|---|---|---|---|
| J2 | main | 245.00 | 8.73 / 11.27 | SENSE, GND |
| J3 | tab | 254.00 | 8.73 / 11.27 | SENSE, GND |

J2's copper edge is 3.45 mm from the slot, J3's is 2.45 mm. Both clear the 1.50 mm setback. A through-hole with no component on it cannot crack, so the 15 mm keepout — which applies to *placed components* — does not bind here.

**Two conductors, SENSE + GND, is the right count.** The GND wire twisted with SENSE *is* the guard; a third conductor would need to be actively driven to beat it, and the firmware has no driven-shield capability.

#### The snapped configuration

| Configuration | C_total | Baseline @4.7 MΩ | Fractional delta | Frame cost |
|---|---|---|---|---|
| **Attached** (default) | ~36 pF | ~170 µs | **2.7 % worst / 8.3 % typical** | ~1.1 % |
| Snapped + 100 mm twisted pair | ~42 pF | ~198 µs | 2.3 % / 7.1 % | ~1.3 % |
| **Snapped + 200 mm (maximum)** | ~48 pF | ~226 µs | **2.0 % / 6.3 %** | ~1.5 % |

Baseline shift is about **+2.8 µs per cm of wire**; the absolute delta does not move at all. With the **proportional** threshold of §8.3 the fraction does shrink slightly with wire length, so **set the threshold against the 200 mm case** and both configurations are covered by one constant with margin to spare.

Mandatory rules for the snapped case, and they belong in the README:

- 28 AWG **twisted** pair, ~2 twists/cm, **maximum 200 mm**.
- SENSE twisted with GND, routed in the spine's wire channel on the y = 0 side, **away from the LED power feed** and not draped along it.
- **The 200 mm limit is set by noise immunity, not capacitance.** A 200 mm run beside a switching LED supply, sampled once with no filtering, will produce false taps. The min-of-N sampling in §8.3 is what makes 200 mm honest rather than optimistic.
- **Do not use shielded cable.** It runs ~1 pF/cm and its shield must be grounded at one end only, which builders get wrong. If someone insists, cap it at 120 mm.
- `TOUCH_FRACTION` does **not** change. The build instructions must not offer a second value.

#### Silkscreen at the break

```
   scissors CUT BOTH TRACES FIRST
   ===+===   SENSE
   ===+===   GND
   THEN BEND DOWN - NEVER TWIST
```

Text height 1.0 mm, black on white mask, printed on the main side at x ≈ 240–249 where it stays readable after the snap. This is the one place where silkscreen prevents a warranty return.

### 7.7 Assembly rules the fab needs

| Rule | Value | Why |
|---|---|---|
| **Thermal relief on every 0402/0805 pad connecting to a pour** | 4 spokes, 0.4 mm wide, 0.25 mm gap | Every LED bypass cap sits inside the 5 V pour with one terminal flooded and the other on a via to the plane. That thermal-mass asymmetry on the smallest package on the board is textbook tombstoning, and on *this* board a tombstoned cap is invisible at bring-up — it presents as exactly the "random LED flicker" the cap exists to prevent. It is a KiCad zone property and costs nothing |
| **LED pads: solid connection, no relief** | 4 thermal vias per LED, ≥60 mm²/layer | Deliberate, for θ_JA. See the rework note below |
| **LED rework note** | Bottom-side preheat to 120 °C before any hot air; mask adjacent lenses with Kapton | An LED whose ground pad is bonded to a full plane through four vias needs enough hot-air energy to soften the PPA lens of its neighbours 16.7 mm away. In practice a bad LED is a scrapped board, which is why the scrap allowance is 6 % rather than 3 % |
| Reflow | **Leaded Sn63Pb37, ~217 °C peak** | Cheaper at JLC *and* materially kinder to the SK6812 lens and phosphor than 245–250 °C |
| Cleaning | Standard no-clean, standard cleaning process. **Do not skip cleaning near the tab** | Surface leakage on a multi-MΩ node |
| Depanel | Routed-slot mouse bites between boards. **The internal break slot is NOT to be broken at the factory** | |

> **On LED moisture sensitivity, be realistic about what is available.** SK6812-class 5050 parts are typically MSL 3, and the standard remedies are not on offer at Economic PCBA: JLC does not run per-customer reflow profiles, free-text notes about peak temperature are not actioned on the line, and the standard MSL3 rebake at 125 °C for 24 h is **above** the deformation threshold of the PPA lens (these parts usually cap storage at 60 °C), so it would damage them. The three controls that actually exist are: select the leaded paste option, which is the only profile lever exposed; buy the LEDs on a single sealed in-date dry-pack reel and consign it with the desiccant and humidity indicator intact so floor life is not consumed in JLC's stores; and manage the rest by inspection — photograph the first article's white point against a reference and check it again on the qty-100 batch. Say so in the README rather than implying process control you do not have.

### 7.8 Panelisation

The outline is a **plain 282 × 20 mm rectangle** — the tab is an internal slot, not an outline feature — so there is nothing to nest and zero panel waste from the tab.

```
 PANEL 282.0 x 140.0 mm, 2-layer, 1.6 mm

 +--------------------------------------------------------------+  <- 5 mm rail
 | (+)                        [o] fiducials                 (+)  |
 |==============================================================|  <- 2.0 mm routed slot
 |  board 1   [HEAD]-------LEDs-------[gap][slot][TAB]           |  20 mm
 |==============================================================|
 |  board 2                                                      |  20 mm
 |==============================================================|
 |  boards 3, 4, 5, 6                                            |
 |==============================================================|
 | (+)                                                      (+)  |  <- 5 mm rail
 +--------------------------------------------------------------+
   ^ NO transverse rails. Board ends ARE panel ends.
```

| Parameter | Value |
|---|---|
| Boards per panel | **6** |
| Panel size | **282.0 × 140.0 mm** (6 × 20 + 5 × 2.0 slots + 2 × 5 rails) |
| Panel area / board area | 394.8 cm² / 56.4 cm² |
| **Utilisation** | 6 × 56.4 / 394.8 = **85.7 %** |
| Separation | **2.0 mm routed slots with mouse-bite tabs** between boards, three per boundary, at x = 40, 141, 242 |
| Rails | 5.0 mm on the two **282 mm** long edges only |
| Fiducials | 3 × Ø1.00 mm bare copper, Ø2.00 mm mask opening, asymmetric triple in the rails |
| Tooling holes | 2 × Ø3.00 mm NPTH in the rails |
| Panel ID | Silkscreen `EM-15 REV A 6UP ^` on a rail |
| Panels for 100 boards | **17** (102 boards) |

Two things about this arrangement are corrections worth stating:

**No V-score anywhere.** The module's antenna must sit near a board long edge, and a V-score blade cutting to ~1/3 depth from each face with ±0.15 mm positional tolerance and a ~0.28 mm surface groove has no usable clearance to a module can set back under about 1.0 mm. Either the fab flags it and the order stalls, or it runs and shears the shield, cracks the module's outermost solder joints, or nicks the antenna feed — invalidating the modular approval that the whole architecture exists to obtain, and doing it invisibly, as degraded RF rather than a dead board. Routed separation removes the blade entirely. It costs a little routing time and no material, and it hands back the 0.5 mm V-score copper setback to the touch guard rail.

**No transverse rails.** J1 sits at x = 0.00 with its mating face required to stand 0.5 mm proud of the base aperture, and the touch pad's free end is at x = 282. A rail at either end would have to be separated by mouse bites, and a 0.3 mm nub on the USB-C end face fouls plug insertion or stops the base closing. Conveyor grip is along the two 282 mm rails, which is what the design relies on anyway. Deleting the end rails also raises utilisation and leaves both board ends as clean routed profile.

### 7.9 Routing order

Each step depends on the previous one; reworking an earlier step is what turns a 14-hour layout into a 30-hour one. Do not autoroute — there are about 60 nets and three of them (SENSE, the 5 V path, D±) have hand-routing constraints no autorouter respects.

1. Outline, break slot, mouse bites, H1/H2, and **every keep-out as a rule area, not a graphic** — antenna, break, pad backside, pour setbacks.
2. Place the eleven LEDs at their exact x coordinates, y = 11.000, rotated 90°. Every other dimension derives from this row.
3. Place `PAD_S`, `PAD_G`, the guard ring and J3 on the tab; J2 in the gap. This fixes the SENSE endpoint.
4. Place U1 and verify the antenna keep-out against the datasheet figure, with the antenna end at the y = 0 long edge.
5. Place J1 at x = 0 and H1/H2 at x = 4.50.
6. Place C1, then F1 → Q1 → U3 around it. C1's position sets the star node.
7. Place U2 + R11 + R3 + C6 as a tight cluster between the module and LED1.
8. Place R7, R10, D2 (DNP) and TP6 at the head end of the guarded channel.
9. Place the eleven 100 nF at (x_n + 3.40, 15.50), then the remaining passives, SW1 and test points.
10. **Route SENSE first**, end to end, top layer, zero vias, with its two guard rails as one locked group. It is the fussiest net and the least tolerant of being squeezed by whatever routes first.
11. Route the DOUT→DIN chain, then U2 → R11 → LD1.DIN.
12. Route VBUS → F1 → Q1 → star node → the 5 V bridge across the head at y 8.6–10.6, 2.0 mm wide, clearing the antenna keep-out, then into the 5 V pour.
13. Route D+/D− as a 90 Ω pair through U4 to IO18/IO19: matched within 5 mm, no stubs, **no vias**, no series resistors.
14. Route 3V3, EN, straps, IO9/SW1.
15. Pour GND (bottom, whole board) with all keep-outs active; then 5 V (top, y 0.40–8.20) and GND (top, y 13.60–17.00).
16. Stitching and thermal vias. Then silkscreen: LED1 arrow, polarity marks, the break-line block, `CUT -> D1`, `BOOT`, rev, test-point labels.
17. DFM sweep (§9.4) and a 3D render against the base/spine/cap STLs.

**KiCad rules beyond the standard set:**

```
Rule area ANTENNA_KO   : per datasheet, both layers, forbid track/via/pad/zone/footprint
Rule area PAD_BACK_KO  : under PAD_S and PAD_G, B.Cu, forbid track/via/zone
Rule area BREAK_KO     : x 234.25 -> 282.0, all layers, forbid footprint
Rule area POUR_SETBACK : 1.5 mm around the slot and every mouse-bite hole, both layers, forbid zone
Net class SENSE        : width 0.30, clearance 0.35, VIA COUNT MUST BE ZERO (check manually)
Net class POWER_5V     : min 2.00 on discrete tracks, pours exempt
Net class USB          : diff pair 90 ohm, skew <= 5 mm, via count zero
```

Manual checks DRC will not catch: SENSE via count, MLCC long-axis orientation within 25 mm of the break, thermal-relief application, and pour continuity in the lit zone.

---

## 8. Firmware

### 8.1 `config.py` deltas

`config.py` is per-board and **never OTA'd** (`boot.py:5`), so this is the golden file flashed to all units, and anything wrong in it is a manual edit on every board forever. That is why `LED_PIN` was deliberately kept at 5.

| Constant | Now | EM-15 | Why |
|---|---|---|---|
| `LED_PIN` | `5` | **`5` — unchanged** | IO5 chosen on the C3 specifically so this and `hardware_test.py:65` never move |
| `NUM_LEDS` | `10` | **`11`** | |
| `TOUCH_PINS` | `[12]` | **`[3]`** | GPIO12–17 are internal flash pins on the C3, not bonded out on MINI-1 |
| `TOUCH_THRESHOLD` | `1` | *(legacy path only)* | Superseded by `TOUCH_FRACTION` on EM-15; kept present for old boards |
| `TOUCH_FRACTION` | — | **new, set at Stage 1** | Proportional threshold. See §8.3 |
| `TOUCH_METHOD` | — | **`"ticks"`** | Selects the µs-timed measurement. Absent ⇒ legacy loop counting |
| `TOUCH_SAMPLES` | — | **`5`** | min-of-N. Absent ⇒ single sample, i.e. legacy |
| `TOUCH_BASELINE_TRACKING` | — | **`True`** | Absent ⇒ off, i.e. legacy |
| `GROUP_MAX_LEDS` | `8` | **`8` — keep** | See §8.2 |
| `REVERSE_LEDS` | `False` | **`False` — MUST REMAIN PRESENT** | `colour.py:15` does a bare `from config import REVERSE_LEDS` with no try/except. Delete the symbol and the board does not boot. It is also a live runtime feature (`main.py:331`, `colour.py:242`), so it is not just a build constant |
| `MAX_CHANNEL_SUM` | — | **`680`** | Hard power/thermal clamp, §5.4 |
| `BOARD_REV` | — | `"EM-15"` | Optional, telemetry only, guarded import. Lets you tell an EM-15 from a discrete build in the MQTT status without a serial console |
| `LED_BRIGHTNESS`, `NUM_GROUPS`, `GROUP_MIN_LEDS`, `HOLD_TIME_MS`, `WATCHDOG_ENABLED`, palette, MQTT, WiFi, WebREPL | | unchanged | |

**Every new symbol read by an OTA'd file must have an `except ImportError` fallback that restores legacy behaviour.** `boot.py:16` syncs `main.py`, `colour.py`, `sk6812.py` and `touch.py` to *every* board, old and new, and an old board's `config.py` cannot be updated to add a flag. This is not politeness — the discrete boards run `TOUCH_THRESHOLD = 1` against a ±1-count noise floor, and switching them to proportional thresholds or aggressive baseline tracking would cause false taps.

There is a related hazard worth knowing about: `main.py:50-52` imports `sk6812`/`touch`/`colour` at module level, **outside** the crash-guard try/except at `main.py:880-894`. An `ImportError` there does not trigger the crash reboot — MicroPython prints a traceback and drops to the REPL, the board sits there, and on the next power cycle `boot.py:84` sees `PWRON_RESET` and resets the fail counter, so the crash-loop rollback never fires either. **A wrong-platform push is a permanent brick requiring USB.** The mitigation is in `boot.py` (§8.4).

### 8.2 `GROUP_MAX_LEDS` — keep 8, and here is the data

`colour.py:52` does `sizes[-1] += remaining` unconditionally, so the declared cap is not enforced on the last group. With `NUM_LEDS = 10` the worst case is `(1,1,8)` and the cap happens to be respected exactly; with 11, `(1,1,9)` becomes reachable. Benign — sizes still sum to 11, `strip.set()` bounds-checks, nothing crashes.

The obvious fix is to raise the constant to 9 so it is honest. Running the actual algorithm 200 000 times per option says don't:

| `NUM_LEDS`, `GROUP_MAX_LEDS` | mean largest group | P(a 9-LED group) | most common shape |
|---|---|---|---|
| 10, 8 *(today, the look you have)* | 5.96 | 0 % | (8,1,2) 6.4 % |
| **11, 8 (recommended)** | 6.28 | **1.6 %** | (8,1,2) 6.4 % |
| 11, 9 | 6.61 | **13.7 %** | **(9,1,1) 11.1 %** |

Raising the cap makes nine of eleven LEDs in one flat block the single most common partition, once every nine taps. Leaving it at 8 keeps the largest-group distribution closest to the ten-LED lamp you already like, and the 1.6 % over-run is cosmetically identical to a partition you would get anyway. It also means **no change to `index.html`**, which hard-codes `randomPartition(cfg.numLeds, n, 1, 8)`.

If you want the constant literally true, the fix belongs in `_random_partition`, not in config — but that file is OTA'd to ten-LED boards too, so don't.

**Confirmed against the code:** `NUM_LEDS` is imported at module scope (`colour.py:12`) and used only for the partition, the group-sum clamp (`colour.py:201-210`), the pixel walk (`colour.py:350-354`), `main.py:228-229`'s RAM cap, and the driver's preallocated buffer. **No hardcoded LED count anywhere else.** 10 → 11 really is a config change.

`index.html:585` defaults `numLeds` to `"10"`. Mismatch is benign in both directions — `colour.py:203-210` pads or clamps the trailing group — but change the default to `11` when you cut over.

### 8.3 `touch.py` — the measurement rewrite

Four changes, all gated on guarded config imports so legacy boards are byte-for-byte unaffected.

**(1) Measure with `utime.ticks_us()`, not by counting interpreted loop iterations.** The loop counter is a scale factor set by MicroPython bytecode speed and CPU clock, which is why the repo currently carries `TOUCH_THRESHOLD = 1` in `config.py` and `50` in `hardware_test.py` — an order of magnitude apart, in the same repo. A µs timer is immune to both.

**(2) Take the minimum of N samples, not the median or the mean.** This is the important one and it turns a liability into a strength. The ESP32-C3 is single-core: the Wi-Fi and lwIP FreeRTOS tasks preempt the interpreter on the same core, and any preemption inside the wait lets wall-clock time advance past the crossing. **With `ticks_us`, every form of corruption is one-sided — preemption can only make the reading larger.** The true value is therefore a floor, and `min` over a handful of samples is a near-perfect denoiser. (With the old loop counter the corruption was one-sided *downward*, which is far worse: it drags the baseline toward the low tail and then a clean sample reads as a touch.)

A finger is present for the whole ~1 ms burst, so min-of-5 still captures a touch.

**(3) Compare against a fraction of the baseline.** `k = ln(V_DD/V_T)`, R tolerance, and any residual timing scale all appear identically in the baseline and the delta and cancel exactly:

```python
def _is_currently_touched(self):
    val = self._measure()                      # min-of-N, microseconds
    return (val - self._baseline) > self._baseline * TOUCH_FRACTION
```

Set `TOUCH_FRACTION` from Stage 1 against the **snapped 200 mm** case, which is the smallest fraction, and it covers both configurations with one constant.

**(4) Baseline tracking, rate-limited and outlier-rejected.** Slow drift tracking is the only fix for boot-time baseline poisoning (§7.5), but a naive asymmetric tracker is dangerous. Rules:

- Reject any sample below ~60 % of the current baseline before it reaches the tracker — with min-of-N that should never happen, and if it does, something is wrong rather than drifting.
- Step the baseline by **at most ±1 µs per second**, symmetric. No proportional steps.
- Clamp the baseline to a plausible band derived from the boot calibration.
- Force a re-baseline if "touched" persists past 30 s. That alone closes the boot-poisoning hazard and has no failure mode of its own.

Also: `pin.init(machine.Pin.IN)` → `pin.init(machine.Pin.IN, None)`. The ESP32 port may leave a previously configured pull in place when `pull` is omitted, and a stray pull-up makes the wait run to its safety cap on every call. Probe the argument once at construction so a port that rejects it still works. **Confirm in Stage 0** — a baseline pinned at the cap is the signature.

### 8.4 `sk6812.py`, `boot.py`, and the rest

**`sk6812.py` is the one rewritten file.** `rp2` appears only there and in `hardware_test.py` — `main.py`, `boot.py`, `colour.py` and `touch.py` never import it, so they need no changes. Keep the class API byte-identical (`__init__(pin, num_leds, brightness)`, `set`, `set_all`, `set_brightness`, `show`, `off`) so nothing else moves, and select the back end by **capability detection at import**, not a config flag — the file is OTA'd to boards whose `config.py` cannot be updated, so a flag would be unreachable on exactly the boards that need it:

```python
try:
    import rp2
    _HAVE_PIO = True
except ImportError:
    _HAVE_PIO = False
# rp2 path: the existing PIO program, byte-identical to what is in the field.
# otherwise:  machine.bitstream(pin, 0, (300, 900, 600, 600), buf)   # ns T0H,T0L,T1H,T1L
```

The bitstream path is **strictly better than the shipped driver.** Tracing the current PIO program at its 10 MHz clock gives timings that do not match its own comment and are all outside the SK6812 windows: T0H 500 ns (spec 150–450), T0L 700 (750–1050), T1H 900 (450–750), T1L 300 (450–750). It works only because genuine parts are tolerant, and it is a latent part-substitution landmine. An explicit ns tuple removes it permanently. **Do not "fix" the rp2 path in the same change** — every deployed lamp depends on the current timing and there is no upside to changing behaviour on hardware you cannot easily reach. Ship it separately, or not at all.

**Do not shortcut with `neopixel.NeoPixel(pin, 11, bpp=4, timing=1)`.** Its byte order is right (`ORDER = (1,0,2,3)` → G,R,B,W, matching the existing `(G<<24)|(R<<16)|(B<<8)|W`), but `timing=1` is the **WS2812B** preset `(400, 850, 800, 450)` and T1H = 800 ns is 50 ns outside the SK6812 window. Call `machine.bitstream` directly. `neopixel` remains a working fallback.

**The power clamp lives in `SK6812.show()`, not in `colour.py`.** `show()` is the single choke point for every LED write on the board — the colour engine, the boot pulse, `hardware_test.py`, and `strip.off()` on the crash path. Putting it in `colour.py` would leave the boot pulse and any future path uncapped. Guard the config import so boards without `MAX_CHANNEL_SUM` get `cap = None` and byte-identical output to today.

Frame time: 11 × 32 bits × 1.2 µs = **422 µs**, 2.6 % of a 16 ms frame. The ≥80 µs latch is supplied incidentally by the inter-frame gap. **Verify in Stage 0** that 422 µs of interrupts-off does not disturb Wi-Fi; the fallback is `esp32.RMT` (the C3 has 2 TX channels), but RMT means building a ~700-entry pulse list per frame in MicroPython, which is much worse for 60 fps, so prove bitstream first.

**`boot.py` gets four changes.** It is not OTA'd, so this must be flashed manually — free on new boards, once over WebREPL on existing ones *before* the first cross-platform push.

1. **An import smoke test.** The existing `compile()` gate proves a file *parses*; `import rp2` parses perfectly and then raises on an ESP32. Add `SMOKE_FILES = ("sk6812.py", "touch.py", "colour.py")` and `exec()` the staged copy of each before committing. All three have side-effect-free module bodies (constants, class definitions, a PIO assembly on rp2 — no hardware is claimed), so this is safe, and it catches a wrong-platform driver, a new config symbol imported without a fallback, and any top-level `NameError` a syntax check cannot see. `main.py` is deliberately **not** in the list — its module body constructs the strip and the touch manager.
2. **Move the identity check before `compile()`, and compare in 512-byte chunks.** The common case — the daily 17:00 reboot with nothing changed — currently compiles a 36 KB `main.py` in RAM for no reason *and* holds two full copies of it while comparing. On a C3 with the Wi-Fi and mbedTLS stacks already on the heap, that is the tightest moment in the whole firmware. After the change, a no-change boot does zero compiles and never holds more than one 36 KB string. Straight win on RP2040 too.
3. `import gc`, with `del` and `gc.collect()` between files and immediately after the response is closed.
4. No change to `REPO_RAW` or `SYNC_FILES`.

**`main.py` needs no changes.** Confirmed by inspection: it never imports `rp2`, and its only port-specific calls (`machine.WDT`, `unique_id`, `reset`, `reset_cause`, `network.WLAN`, `webrepl`, `ntptime`, `umqtt.simple`) all exist on the esp32 port. Leave `WDT(timeout=8000)` alone — it sits at the RP2040's ~8.388 s ceiling and has headroom on ESP32, and keeping it identical keeps both platforms behaving the same. The optional `BOARD_REV` addition follows the existing `WATCHDOG_ENABLED` pattern at `main.py:35-38`.

**`hardware_test.py` needs a rewrite**, not a tweak. It currently hard-codes `TOUCH_PIN = 12` and `NUM_LEDS = 8` — the LED count is already wrong for the existing ten-LED build — and carries its own inline PIO copy of the driver. Structure in §9.2.

**Operational recommendation, zero code change: canary via a staging branch.** `boot.py` is per-board and not OTA'd, so point one discrete Pico W and one EM-15 at a `staging` branch by editing one line of their `boot.py`. Push to `staging`, wait one daily reboot cycle, confirm both canaries came back, then fast-forward `master`. It costs nothing and it is the only mechanism you have that tests both platforms before the fleet sees a change.

---

## 9. Bill of materials, ordering, and the prototype plan

### 9.1 BOM

Prices are per placement at the LCSC tier you land in buying for that quantity, including 5–10 % spares.

| # | Ref | Qty | Part | LCSC | Package | @10 | @100 | @500 | JLC tier |
|---|---|---|---|---|---|---|---|---|---|
| 1 | U1 | 1 | **ESP32-C3-MINI-1-N4** | C2838502 | module | 3.470 | **2.920** | 2.920 | Extended |
| 2 | LD1–11 | **11** | **SKC6812RGBW-WS** (OPSCO) | C5378724 | SMD5050-4P | 0.1024 | **0.0821** | 0.0821 | Extended |
| 3 | U2 | 1 | **SN74AHCT1G125DBVR** | **C7484** | SOT-23-5 | 0.060 | 0.045 | 0.038 | Extended |
| 4 | U3 | 1 | AP2112K-3.3TRG1 | verify | SOT-23-5 | 0.090 | 0.065 | 0.055 | Basic |
| 5 | Q1 | 1 | AO3401A | C15127 | SOT-23 | 0.040 | 0.025 | 0.020 | Basic |
| 6 | J1 | 1 | TYPE-C-31-M-12, THT shield tabs | C165948 | USB-C 16P | 0.250 | 0.140 | 0.120 | Basic |
| 7 | U4 | 1 | USBLC6-2SC6 | verify | SOT-23-6 | 0.120 | 0.075 | 0.065 | Basic |
| 8 | F1 | 1 | PPTC 2 A hold / 4 A trip, ≤0.06 Ω | search | 1812 | 0.070 | 0.045 | 0.038 | likely Ext |
| 9 | SW1 | 1 | SMD tact switch | search | 3×4 mm | 0.050 | 0.035 | 0.030 | likely Basic |
| 10 | C1 | 1 | 470 µF / 10 V alu, ≤10 mm, ESR ≤0.2 Ω | search | 8×10.2 | 0.150 | 0.100 | 0.085 | likely Ext |
| 11 | C2–C5 | **4** | 22 µF 0805 X5R ≥10 V | verify | 0805 | 0.025 | 0.012 | 0.010 | Basic |
| 12 | C6–C20 | **15** | 100 nF 0402 X7R **16 V** | verify | 0402 | 0.003 | 0.0015 | 0.0012 | Basic |
| 13 | R1–R7 | **7** | 5.1 kΩ 0402 1 % | verify | 0402 | 0.002 | 0.0008 | 0.0006 | Basic |
| 14 | R8, R9 | 2 | 100 kΩ 0402 1 % | verify | 0402 | 0.002 | 0.0008 | 0.0006 | Basic |
| 15 | R10 | 1 | **4.7 MΩ 0402 5 %** | search | 0402 | 0.006 | 0.003 | 0.002 | verify tier |
| 16 | R11 | 1 | 47 Ω 0402 1 % | search | 0402 | 0.002 | 0.0008 | 0.0006 | Basic |
| — | DNP | 4 | D1 (SMA), D2 (0402), D3 (SOD-123), C21 (0402), J2/J3/J4 (THT), LK1 | — | — | 0 | 0 | 0 | — |
| — | free | 11 | TP1–TP11, H1/H2, PAD_S/PAD_G | — | — | 0 | 0 | 0 | — |

**16 unique lines. 50 placements. ~204 joints. Zero THT placements, zero hand-solder operations, zero consigned parts.**

Component subtotal per board: **@10 $5.62, @100 $4.43, @500 $4.34**, before attrition. The module and the LEDs are 78 % of it.

**Line-level notes that matter:**

- **The LEDs are the number one live risk.** The "reference" `SK6812RGBW-NW` (C5160656) already shows unavailable at LCSC. `SKC6812RGBW-WS` (C5378724) is the primary because it is the one positively confirmed in the JLC *assembly* library, and warm white matches `BASE_WARM_WHITE`. `SKC6812RGBW-NW` (C5348912) is the second source and is cheaper below 1000 pcs, so use it for prototypes regardless. **`SKC` is not `SK`** — data order, bit timing, V_IH and per-channel current are unconfirmed and are a mandatory Stage 0 gate. **Buy all ~1,200 pieces in one PO, one date code, one bin, and tick "do not substitute".** An RGB three-channel part drops into the same footprint and would silently break `colour.py`'s entire W-dominant model — the one substitution that produces 100 boards that light up and are still wrong.
- **C7484 is AHCT. C7468 is AHC.** Two digits apart, and the wrong one fixes nothing. Put the note in the schematic as text, not just the BOM.
- **100 nF at 16 V, not 50 V.** The highest rail is 5 V; 16 V X7R 0402 is Basic and cheap, the 50 V equivalent is often Extended. At 5 V bias a 16 V part loses ~20 %, irrelevant for a bypass cap.
- **R10 is the line that must not be value-engineered.** It converts `TOUCH_FRACTION` from a per-unit measurement into a shipped constant. If 4.7 MΩ 0402 is thin, use 4.7 MΩ 0603 or 10 MΩ 0402 (§7.5). **Do not fall back to 1 MΩ** — that collapses the delta and reintroduces per-unit calibration on all 100 boards.
- For the passive lines the C-number is not load-bearing; pick whatever JLC currently lists as **Basic** in that value, package and tolerance. That is exactly why they are cheap.

### 9.2 PCB, assembly and landed cost

**PCB:** 2 layer, FR-4, standard T_g, **1.6 mm**, **1 oz**, **HASL with lead**, **white mask / black silk**, 2.0 mm routed inter-board slots, internal break slot and NPTH mouse bites, order number "specify a location" on a rail (free; removal costs ~$1.50).

**Assembly:** JLCPCB **Standard** PCBA, single-sided. (This section originally modelled Economic. It is not available: the SK6812s are MSL 3 and need baking, which §7.7 predicted and the first order confirmed. Standard adds ~$25 setup and charges a loading fee on every component, not only Extended ones, so **every figure below is optimistic** and must be re-quoted before a volume order.) Published Economic rates were: Published rates: setup $8.18, stencil $1.53, $0.0016/joint, $3.07 per unique Extended part, $0.00 for Basic. Assuming 5 Extended lines:

```
fixed    = 8.18 + 1.53 + 5 x 3.07 = $25.06
variable = 204 joints x $0.0016   = $0.326 per board
```

| | qty 10 | qty 30 (5 panels) | qty 100 (17 panels) | qty 500 |
|---|---|---|---|---|
| Components (+3 %) | 5.79 | 5.35 | **4.56** | 4.47 |
| PCB | 4.00 | 1.40 | **0.82** | 0.56 |
| Assembly | 2.83 | 1.16 | **0.58** | 0.38 |
| Freight (DHL, CN→CH) | 2.50 | 1.05 | **0.45** | 0.30 |
| Swiss import VAT @8.1 % | 1.22 | 0.72 | 0.52 | 0.46 |
| Customs clearance (~$22 flat) | 2.20 | 0.73 | 0.22 | 0.04 |
| Scrap / DOA allowance **6 %** | 0.91 | 0.52 | 0.44 | 0.37 |
| **TOTAL LANDED, ASSEMBLED BOARD** | **$19.45** | **$10.93** | **$7.59** | **$6.58** |
| *(ex-VAT/duty, e.g. shipped to a US address)* | *$16.03* | *$9.48* | *$6.85* | *$6.08* |

**Honest quotable ranges: qty 10 → $18–23. qty 30 → $10–13. qty 100 → $7.00–9.00. qty 500 → $6.00–7.50.** PCB pricing is a model, not a quote, and is ±25 %.

The **6 % scrap allowance** is not padding. An eleven-deep series-data chain of parts that cannot practically be reworked (§7.7) at a typical 0.3 % per-LED assembled defect rate gives 3.3 % of boards with at least one dead LED, and each is a whole-board write-off, not a component loss. Add normal SMT fallout and 6 % is the honest number.

At qty 10, fixed cost is 89 % of the assembly bill and ~45 % of the landed total. **Note the shape of the curve: with a 6-up panel, JLC's five-panel minimum means ordering "10" gets you 30 boards for about 56 % more money.** Order 30.

### Complete boxed lamp, qty 100

| Item | $ |
|---|---|
| Assembled EM-15 board | 7.59 |
| Opal diffuser tube, 30 mm OD × 220 mm, cut from extrusion | 2.50 |
| Printed base + spine + top cap, in-house (**filament only**) | 1.90 |
| 5 V / 2.4 A USB-C supply | 3.50 |
| USB-C cable, 1 m | 1.00 |
| Packaging | 0.60 |
| **TOTAL** | **$17.09** |

**Is the $20 target real? Plainly:**

- Bare assembled board at qty 100: **$7.59.** Comfortably inside.
- Complete boxed lamp with a supply, enclosure printed by you: **$17.09.** Inside, with $2.90 of room.
- Without a supply in the box: **$13.59.**
- **With an outsourced printed enclosure (MJF/SLS at $6–9): $22–25. Over target.**
- Injection moulding is not viable at 100 units — tooling alone is $1,500+, i.e. $15/unit.
- Honest floor for the electronics alone with these features, no hand-soldering, green mask, no PPTC, cheapest LED tier, ex-VAT: **≈$5.60/board at qty 100.** Below that you are deleting the level shifter or the bulk cap, which buys pennies and costs a revision.

**Two costs are not in that table and both are larger than the BOM.** The enclosure line prices filament, not machine time: base + 184 mm spine + top cap is roughly 6.5 hours per lamp, so **100 lamps is ~650 printer-hours — about a month of continuous single-machine printing — plus a 5–10 % print-failure rate.** And your own time: the driver port plus Stage 0 is ~6 h, KiCad layout ~14–18 h (a 282 mm board with a guarded high-impedance net and a panel is not a quick one), bring-up ~4 h, README rewrite ~2 h. At any honest rate that dwarfs the qty-100 BOM, which is itself the strongest argument for the architecture with the fewest ways to need a second spin.

### 9.3 What was deleted, and what breaks

| Deleted or consolidated | Saved | What breaks |
|---|---|---|
| USB-UART bridge + its crystal | $0.35, 2 lines | Nothing — the C3 has native USB Serial/JTAG |
| External crystal + load caps + QSPI flash | $0.27, 3 lines | Nothing — inside the module |
| Separate VBUS TVS | $0.04, 1 line | Nothing measurable — U4 clamps ESD, C1 is a better hot-plug clamp |
| Touch TVS → DNP | $0.05, 1 line | Nothing — the pad is under mask *and* behind plastic, no galvanic path |
| RESET button | $0.04, 1 line | Nothing — and it removes the three-presses-in-60 s rollback path. TP10 replaces it |
| Power indicator LED + resistor | $0.02, 2 lines | Nothing — it is a light leak inside a lamp; the eleven RGBW LEDs *are* the indicator |
| Barrel jack → DNP pads | $0.20, 1 line | Nothing — and it deletes the ORing problem (2 Schottkys at 0.35 W, or a P-FET mux) |
| Connector at the break → bare THT pads | $0.35, 1 line, 1 crimp op | Nothing — a soldering iron is already required to rewire |
| USB 27 Ω series pair | 1 line | Nothing — the C3 reference design connects D± directly |
| Guard conductor at the break (3rd pad pair) | — | Nothing — GND twisted with SENSE *is* the guard |
| Series diode → DNP + cuttable link | $0.02, 1 line | Nothing — the hedge is preserved at zero cost |
| Separate 10 µF LED-rail line → reuse 22 µF | $0.01, 1 line | Nothing — 22 µF X5R at 5 V bias is ~11 µF effective, exactly what the rail wants |
| Second-side assembly | ~$0.55 | Nothing — everything fits on one side |
| Second PCB / flex tail for the LED bar | ~$1.50 | Nothing — the break-away tab is the right answer |
| Resistors → 4 values, capacitors → 3 values | ~6 lines ≈ $18 one-off setup | Nothing |

**Refused to cut — $0.42 total, and this is the price of not needing a revision:**

| Kept | $ | Because |
|---|---|---|
| U2 + C6 (74AHCT1G125) | 0.11 | 3.3 V into a 5 V SK6812 is unconditionally out of spec; intermittent field failure no OTA can reach |
| C10–C20 (11 × 100 nF) | 0.02 | Unbypassed LED neighbours are the *actual* cause of "random flicker" |
| C1 (470 µF) | 0.10 | 0.379 V droop on a 0→0.891 A step |
| Q1 + R8 + C7 | 0.04 | Uncontrolled 470 µF inrush = "only works if I replug it" |
| F1 (PPTC 2 A) | 0.06 | Protects the *user's charger*, not the board |
| U4 (USBLC6) | 0.07 | Protects the only OTA-brick recovery path |
| C4 (4th 22 µF at the module) | 0.02 | Wi-Fi TX brownout is the classic ESP32 module failure |
| R10 + defined electrode geometry | 0.003 | Converts the threshold from a per-unit measurement into a shipped constant |
| R3 (5.1 kΩ on IO5) | 0.001 | Stops a floating AHCT input latching garbage at power-up |
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

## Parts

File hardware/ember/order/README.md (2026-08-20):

# Ordering EM-15 from JLCPCB

Everything in this folder is what you upload. Nothing else.

| File | Where it goes |
|---|---|
| `ember-gerbers.zip` | PCB tab — "Add gerber file" |
| `ember-bom.csv` | Assembly — BOM file |
| `ember-cpl.csv` | Assembly — CPL / pick-and-place file |

The annotated BOM with sourcing notes lives at `../ember-bom.csv`; the one in here is
trimmed to the four columns JLC's parser wants.

## Settings

**PCB tab** — dimensions should auto-read **187.1 × 52.1 mm**; check it.

- Layers 2 · Thickness **1.6 mm** · Copper **1 oz**
- Surface finish **HASL with lead** (cheapest, and its ~217 °C reflow is kinder to the
  LED lenses than lead-free's 245–250 °C)
- Solder mask **white** if it is within ~$0.15/board, else green. The board is the
  reflector inside the diffuser; white buys 10–20 % more light out.
- Silkscreen **black**
- Via covering: **tented**
- **PCB Qty 5** for a first run. Single boards, not panelised — panelising only pays
  from ~30 up.
- **Confirm Production File: YES.** Worth the day it costs on a first article.

**Assembly tab**

- **Standard PCBA**, **Top side only** (there is nothing on the bottom)

  Not a choice: JLC forces Standard here. The SK6812 LEDs are MSL 3 and the ESP32-C3
  module is moisture-sensitive too, so both need **baking before reflow** — a process
  step the Economic line does not run. §7.7 of the design doc called this before the
  first order was ever placed.

  What it costs: roughly **+$25 setup**, and a loading fee on *every* component rather
  than only the Extended ones. That erases most of the value of the four BASIC lines,
  though those still guarantee stock and no MOQ, which was the real reason for them.
  At 5 boards fixed cost dominates anyway. One consolation: double-sided assembly is
  no longer a premium, so a future revision can use the back for free.
- Tooling holes: **Added by JLCPCB**
- **Confirm Parts Placement: YES**

## The two screens where boards get killed

**Parts review.** Resolve every "part not found" and never accept a suggested
alternative silently — that is exactly how a 0402 pad gets an 01005 part. Two lines
matter more than the rest:

- **LD1–LD15 must be C5378724**, a 4-channel RGBW in GRBW order, warm white. A
  3-channel RGB part fits the same footprint and is silently wrong.
- **U2 must be C7484** (SN74AHCT1G125). C7468 is the AHC version, two digits apart,
  and it fixes nothing — 3.3 V in, 3.3 V out, and the LEDs stay out of spec.

**Placement preview.** Check **all fifteen LED rotations** are identical. LED rotation is
the most common JLC PCBA error, because the reel convention often differs from the
footprint's. Zoom LD1 and LD15 and confirm DIN faces the previous LED's DOUT. Also check
J1's overhang at the board edge, and **Q1's source toward the input, drain toward the
load** — a reversed P-FET conducts through its body diode permanently and deletes the
soft-start silently.

## Order separately from LCSC, same week

Spares you will want: 20 LEDs, and 3 each of the module, the AHCT buffer, the LDO and
the FET. Also a **JST-PH 3-pin cable** for J4 and a TTP223 touch module.

## Known risks on this order

- **The firmware is not ported.** `NUM_LEDS` is still 10, `sk6812.py` still imports
  `rp2` (the C3 has no PIO) and `touch.py` still does charge-time timing rather than
  reading a TTP223. The boards will arrive before the software that drives them.
- **Stage 0 was skipped.** `machine.bitstream`, the GRBW order and a full OTA cycle on
  the C3 are unproven. That is the risk this order is buying information about.
- **C7429690 is a JST-PH clone.** Check its drawing against the land pattern.

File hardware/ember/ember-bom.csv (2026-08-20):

Comment | Designator | Footprint | LCSC Part # | Note
470uF/10V | C1 | CP_Elec_8x10 | C47023096 | Extended. 7.4k stock, D8 x 10.5mm - thinnest stock on the board after the LED
22uF | C2,C3,C4,C5 | C_0805_2012Metric | C6119897 | 0805 10V X5R, 184k stock, $0.020 vs $0.119 for the 25V BASIC part C45783 - the single biggest safe saving on the board, $0.39/unit across four places. DC bias at 5V derates it to ~10-12uF effective, which is fine here: the LDO needs >=1uF, and C1's 470uF carries the bulk
100nF | C6,C7,C8,C9,C10,C11,C12,C13,C14,C15,C16,C17,C18,C19,C20,C21,C22,C23,C24 | C_0402_1005Metric | C1525 | BASIC. 16.4M stock, 16V X7R
PPTC 2A/4A | F1 | R_1812_4532Metric | C883156 | Extended. BSMD1812-200-16V, 2A hold / 4A trip, 76k stock - the section 6.2 spec. At 15 LEDs worst case is ~1.69 A
USB-C 16P | J1 | USB_C_Receptacle_HRO_TYPE-C-31-M-12 | C165948 | HRO TYPE-C-31-M-12, 90k stock, $0.186. The $0.087 GT-USB-7010ASV was rejected: its footprint has 0.175 mm copper-to-hole, under JLC's 0.25 mm minimum. TOP side, plug enters from the rear board edge
IO/VCC/GND | J4 | JST_PH_S3B-PH-SM4-TB_1x03-1MP_P2.00mm_Horizontal | C7429690 | ZX-PH2.0-WT3P, 3-pin 2.0mm right-angle SMD, 17k stock, $0.053. Genuine JST S3B-PH-SM4-TB is C265101 at $0.377 if the clone footprint disappoints - CHECK the chosen part's drawing against the JST land pattern before ordering
SK6812RGBW | LD1,LD2,LD3,LD4,LD5,LD6,LD7,LD8,LD9,LD10,LD11,LD12,LD13,LD14,LD15 | LED_WS2812B_PLCC4_5.0x5.0mm_P3.2mm | C5378724 | SKC6812RGBW-WS = WARM WHITE (the -NW suffix, C5348912, is neutral and would fight BASE_WARM_WHITE). *** STOCK NOT VERIFIED - section 9.1 number one live risk. 4-channel RGBW, GRBW order. An RGB part fits the same footprint and is silently wrong ***
AO3401A | Q1 | SOT-23 | C15127 | P-FET. Source to INPUT side, drain to load
5k1 | R1,R2,R3,R4,R5,R6,R7 | R_0402_1005Metric | C25905 | BASIC. 8.4M stock, 1%
100k | R8,R9,R10 | R_0402_1005Metric | C25741 | BASIC. 15.4M stock, 1%. Replaces C25086 - JLC now lists that Extended, 0 stock, MOQ 700
100R | R11 | R_0402_1005Metric | C25076 | BASIC. 9.8M stock
BOOT | SW1 | SW_SPST_EVQP7C | C49234124 | 3x4x2mm SMD tact, 101k stock, $0.019 - half the price of C18078117 with 5x the stock
ESP32-C3-MINI-1-N4 | U1 | ESP32-C3-MINI-1 | C2838502 | Extended. 26k stock, $3.84 - doc modelled $2.92, budget ~$0.9/board more
SN74AHCT1G125 | U2 | SOT-23-5 | C7484 | AHCT/HCT ONLY. C7468 is AHC and fixes nothing - two digits apart
AP2112K-3.3 | U3 | SOT-23-5 | C23380830 | Extended. 31k stock. EN ties to VIN, not VOUT
USBLC6-2SC6 | U4 | SOT-23-6 | C2687116 | Extended. 150k stock

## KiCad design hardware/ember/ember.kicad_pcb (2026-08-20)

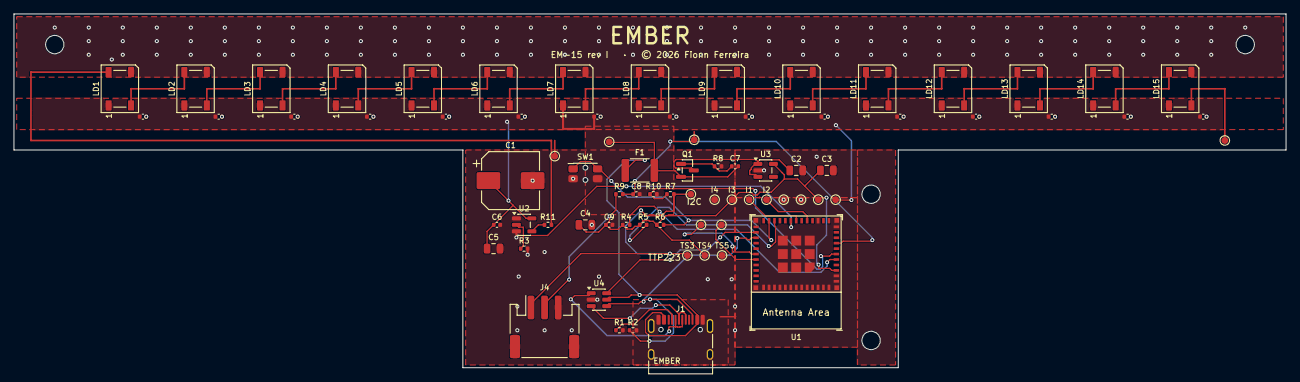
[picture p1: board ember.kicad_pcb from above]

Board: 2 copper layers, 187.0 x 52.0 mm, 81 parts (0 on the bottom side), 41 nets.

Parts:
C1: 470uF/10V; CP_Elec_8x10
C2, C3, C4, C5: 22uF; C_0805_2012Metric
C6, C7, C8, C9, C10, C11, C12, C13, C14, C15, C16, C17, C18, C19, C20, C21, C22, C23, C24: 100nF; C_0402_1005Metric
F1: PPTC 2A/4A; R_1812_4532Metric
H1, H2, H3, H4: M2.5; MountingHole_2.7mm_M2.5
I1: I2C_SDA; TestPoint_Pad_D1.0mm
I2: I2C_SCL; TestPoint_Pad_D1.0mm
I3: +3V3; TestPoint_Pad_D1.0mm
I4: GND; TestPoint_Pad_D1.0mm
J1: USB-C 16P; USB_C_Receptacle_HRO_TYPE-C-31-M-12
J4: IO/VCC/GND; JST_PH_S3B-PH-SM4-TB_1x03-1MP_P2.00mm_Horizontal
LD1, LD2, LD3, LD4, LD5, LD6, LD7, LD8, LD9, LD10, LD11, LD12, LD13, LD14, LD15: SK6812RGBW; LED_WS2812B_PLCC4_5.0x5.0mm_P3.2mm
Q1: AO3401A; SOT-23
R1, R2, R3, R4, R5, R6, R7: 5k1; R_0402_1005Metric
R8, R9, R10: 100k; R_0402_1005Metric
R11: 100R; R_0402_1005Metric
SW1: BOOT; SW_SPST_EVQP7C
TP1: LED_5V; TestPoint_Pad_D1.0mm
TP2: +3V3; TestPoint_Pad_D1.0mm
TP3, TP4: GND; TestPoint_Pad_D1.0mm
TP5: LED_DIN1; TestPoint_Pad_D1.0mm
TP6: TOUCH_SENSE; TestPoint_Pad_D1.0mm
TP7: LD11_DOUT; TestPoint_Pad_D1.0mm
TP8: UART_TX; TestPoint_Pad_D1.0mm
TP9: UART_RX; TestPoint_Pad_D1.0mm
TP10: EN; TestPoint_Pad_D1.0mm
TP11: VBUS_F; TestPoint_Pad_D1.0mm
TS3: TOUCH_SENSE; TestPoint_Pad_D1.0mm
TS4: +3V3; TestPoint_Pad_D1.0mm
TS5: GND; TestPoint_Pad_D1.0mm
U1: ESP32-C3-MINI-1-N4; ESP32-C3-MINI-1
U2: SN74AHCT1G125; SOT-23-5
U3: AP2112K-3.3; SOT-23-5
U4: USBLC6-2SC6; SOT-23-6

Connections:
+3V3: C3.1, C4.1, C9.1, I3.1, J4.2, R4.1, R5.1, R6.1, R9.1, TP2.1, TS4.1, U1.3, U3.5
+5V: C2.1, Q1.3, U3.1, U3.3
BOOT_N: R6.2, SW1.1, U1.23
CC1: J1.A5, R1.1
CC2: J1.B5, R2.1
D_1_2: LD1.2, LD2.4
D_2_3: LD2.2, LD3.4
D_3_4: LD3.2, LD4.4
D_4_5: LD4.2, LD5.4
D_5_6: LD5.2, LD6.4
D_6_7: LD6.2, LD7.4
D_7_8: LD7.2, LD8.4
D_8_9: LD8.2, LD9.4
D_9_10: LD9.2, LD10.4
D_10_11: LD10.2, LD11.4
D_11_12: LD11.2, LD12.4
D_12_13: LD12.2, LD13.4
D_13_14: LD13.2, LD14.4
D_14_15: LD14.2, LD15.4
EN: C8.1, R9.2, TP10.1, U1.8
GATE: C7.1, Q1.1, R8.1
GND: C1.2, C2.2, C3.2, C4.2, C5.2, C6.2, C8.2, C9.2, C10.2, C11.2, C12.2, C13.2, C14.2, C15.2, C16.2, C17.2, C18.2, C19.2, C20.2, C21.2, C22.2, C23.2, C24.2, I4.1, J1.A1, J1.A12, J1.B1, J1.B12, J1.SH, J4.3, J4.MP, LD1.3, LD2.3, LD3.3, LD4.3, LD5.3, LD6.3, LD7.3, LD8.3, LD9.3, LD10.3, LD11.3, LD12.3, LD13.3, LD14.3, LD15.3, R1.2, R2.2, R3.2, R8.2, R10.2, SW1.2, TP3.1, TP4.1, TS5.1, U1.1, U1.2, U1.11, U1.14, U1.36, U1.37, U1.38, U1.39, U1.40, U1.41, U1.42, U1.43, U1.44, U1.45, U1.46, U1.47, U1.48, U1.49, U1.50, U1.51, U1.52, U1.53, U2.1, U2.3, U3.2, U4.2
I2C_SCL: I2.1, U1.16
I2C_SDA: I1.1, U1.18
LD11_DOUT: LD15.2, TP7.1
LED_5V: C1.1, C5.1, C6.1, C10.1, C11.1, C12.1, C13.1, C14.1, C15.1, C16.1, C17.1, C18.1, C19.1, C20.1, C21.1, C22.1, C23.1, C24.1, LD1.1, LD2.1, LD3.1, LD4.1, LD5.1, LD6.1, LD7.1, LD8.1, LD9.1, LD10.1, LD11.1, LD12.1, LD13.1, LD14.1, LD15.1, TP1.1, U2.5
LED_DATA_3V3: R3.1, U1.19, U2.2
LED_DATA_5V: R11.1, U2.4
LED_DIN1: LD1.4, R11.2, TP5.1
STRAP2: R4.2, U1.5
STRAP8: R5.2, U1.22
TOUCH_GPIO: R7.1, R10.1, U1.6
TOUCH_SENSE: J4.1, R7.2, TP6.1, TS3.1
UART_RX: TP9.1, U1.30
UART_TX: TP8.1, U1.31
USB_DM: U1.26, U4.6
USB_DM_CONN: J1.A7, J1.B7, U4.1
USB_DP: U1.27, U4.4
USB_DP_CONN: J1.A6, J1.B6, U4.3
VBUS_F: C7.2, F1.2, Q1.2, TP11.1
VBUS_RAW: F1.1, J1.A4, J1.A9, J1.B4, J1.B9, U4.5

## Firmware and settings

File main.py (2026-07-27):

# ============================================================
#  main.py  —  Entry point, runs on BOTH boards identically
#  Only config.py differs between boards.
# ============================================================

import gc
import math
import sys
import os
import utime
import ujson
import machine
import network
from umqtt.simple import MQTTClient

from config import (
    BOARD_ID, BOSS,
    WIFI_NETWORKS,
    MQTT_BROKER, MQTT_PORT, MQTT_USER, MQTT_PASSWORD,
    MQTT_TOPIC_PREFIX,
    LED_PIN, NUM_LEDS, LED_BRIGHTNESS,
    TOUCH_PINS,
    RECONNECT_DELAY_MS,
    WEBREPL_PASSWORD,
)

FIRMWARE_VERSION       = "2026-07-27.2"
FRAME_MS               = 16
SYNC_INTERVAL_MS       = 60_000
SYNC_FADE_STEPS        = 300
WIFI_OFFLINE_REBOOT_MS = 10 * 60 * 1000   # reboot after 10 min offline

# Boards keep their own (never-OTA'd) config.py, so new config flags must
# be imported with a fallback or older boards would ImportError on boot.
try:
    from config import WATCHDOG_ENABLED
except ImportError:
    WATCHDOG_ENABLED = True

# ── Hardware watchdog ────────────────────────────────────────
# The crash guard catches exceptions, but not HANGS (stuck DNS lookup,
# dead socket, PIO lockup). The RP2040 watchdog reboots the board if the
# main loop stops feeding it for 8 s — a hang becomes a 1-off restart
# instead of a dead lamp.
wdt = None

def feed_wdt():
    if wdt:
        wdt.feed()
from sk6812 import SK6812
from touch   import TouchManager
from colour  import ColourEngine

# ── MQTT topics ─────────────────────────────────────────────
# All boards publish to and subscribe from the same shared topic.
# They ignore messages that carry their own BOARD_ID (echo prevention).
TOPIC_EVENTS = (MQTT_TOPIC_PREFIX + "/events").encode()
# Retained per-board presence topic. A Last-Will makes the BROKER flip it
# to offline if the board dies silently; retained delivery means a web
# client knows each board's state the instant it subscribes.
TOPIC_STATUS = (MQTT_TOPIC_PREFIX + "/status/" + BOARD_ID).encode()
# Retained alarm schedule, shared by all clients and boards. Subscribing to
# it is what makes alarms durable: a board that was offline (or rebooting)
# when the schedule changed still receives it the moment it reconnects.
TOPIC_ALARMS = (MQTT_TOPIC_PREFIX + "/alarms").encode()

ntp_ok = False        # module-level so status/heartbeat can report clock health
_test_alarm = None    # set by MQTT test_alarm, consumed by the main loop

# The BOSS re-publishes its state every 60 s so the lamps converge. That
# also silently undid deliberate per-lamp settings ("Send to → LS" reverted
# within a minute). A targeted command therefore unlinks the lamps, and a
# broadcast command — which sets both to the same thing — re-links them.
INDEPENDENT_MS   = 30 * 60 * 1000
_independent_until = None   # ticks_ms deadline, or None when linked

# ── Module-level objects ─────────────────────────────────────
strip  = SK6812(pin=LED_PIN, num_leds=NUM_LEDS, brightness=LED_BRIGHTNESS)
touch  = TouchManager(TOUCH_PINS)
engine = ColourEngine()
client = None   # MQTTClient, initialised after WiFi

# ── WiFi ─────────────────────────────────────────────────────

NETWORKS_FILE = "networks.json"

def _write_json(fname, obj):
    """Atomic JSON write: temp file + rename, so a power cut mid-write
    can never leave a truncated/corrupt file on flash."""
    tmp = fname + ".tmp"
    with open(tmp, "w") as f:
        ujson.dump(obj, f)
    os.rename(tmp, fname)

def load_extra_networks():
    """Load user-added networks from networks.json (junk entries dropped)."""
    try:
        with open(NETWORKS_FILE) as f:
            nets = ujson.load(f)
        return [n for n in nets
                if isinstance(n, (list, tuple)) and len(n) == 2
                and isinstance(n[0], str) and isinstance(n[1], str)]
    except Exception:
        return []

def save_network(ssid, password):
    """Append a new network to networks.json, avoiding duplicates."""
    nets = load_extra_networks()
    if any(n[0] == ssid for n in nets):
        print(f"[wifi] {ssid} already saved")
        return
    nets.append([ssid, password])
    _write_json(NETWORKS_FILE, nets)
    print(f"[wifi] saved new network: {ssid}")

def all_networks():
    return WIFI_NETWORKS + load_extra_networks()


# ── Crash-loop rollback (paired with boot.py) ────────────────
# boot.py counts boots that never reach stability and restores `.ok`
# backups after too many. Our job is to declare this firmware good once it
# has actually run for a while. Constants mirror boot.py, which is not
# OTA-updated and so cannot be imported from.
STABLE_MS     = 60_000
FAIL_FILE     = "bootfail.txt"
ROLLBACK_FLAG = "rolledback.txt"
OK_SUFFIX     = ".ok"
SYNCED_FILES  = ("main.py", "colour.py", "sk6812.py", "touch.py")

def _rolled_back():
    try:
        open(ROLLBACK_FLAG).close()
        return True
    except OSError:
        return False

def mark_stable():
    """This firmware has run long enough to be trusted: clear the crash
    counter and promote the running files to known-good backups."""
    try:
        with open(FAIL_FILE, "w") as f:
            f.write("0")
    except Exception as e:
        print(f"[boot] could not clear fail counter: {e}")
    try:
        os.remove(ROLLBACK_FLAG)     # recovered; stop reporting it
    except OSError:
        pass
    for fname in SYNCED_FILES:
        try:
            with open(fname) as f:
                current = f.read()
            try:
                with open(fname + OK_SUFFIX) as f:
                    if f.read() == current:
                        continue         # backup already matches — no write
            except OSError:
                pass                     # no backup yet
            tmp = fname + OK_SUFFIX + ".tmp"
            with open(tmp, "w") as f:
                f.write(current)
            os.rename(tmp, fname + OK_SUFFIX)
            print(f"[boot] known-good backup updated: {fname}")
        except Exception as e:
            print(f"[boot] backup of {fname} failed: {e}")
    print("[boot] firmware marked stable")

def connect_wifi(tick=None):
    wlan = network.WLAN(network.STA_IF)
    wlan.active(True)
    if wlan.isconnected():
        return wlan

    print("[wifi] scanning...")
    visible = set()
    try:
        for ap in wlan.scan():
            visible.add(ap[0].decode("utf-8", "ignore"))
    except Exception:
        pass
    print(f"[wifi] visible networks: {visible}")

    for ssid, password in all_networks():
        if visible and ssid not in visible:
            print(f"[wifi] {ssid} not in range, skipping")
            continue
        print(f"[wifi] trying {ssid}...")
        wlan.connect(ssid, password)
        deadline = utime.ticks_add(utime.ticks_ms(), 12_000)
        while not wlan.isconnected():
            if utime.ticks_diff(deadline, utime.ticks_ms()) <= 0:
                print(f"[wifi] {ssid} timed out")
                wlan.disconnect()
                utime.sleep_ms(500)
                break
            if tick:
                tick()
            utime.sleep_ms(50)
        if wlan.isconnected():
            print(f"[wifi] connected to {ssid} — IP {wlan.ifconfig()[0]}")
            return wlan

    raise OSError("No known WiFi network found")


# ── MQTT ─────────────────────────────────────────────────────

# ── Input validation ─────────────────────────────────────────
# The events topic lives on a PUBLIC broker — anything can be published to
# it. Every field is validated/clamped before it touches the engine or,
# worse, gets persisted to flash. (Before this, one malformed set_alarms
# message would be saved to alarms.json and crash the main loop on every
# boot — a permanent remote boot-loop.)

def _num(v, lo, hi, default=None):
    """Coerce to float and clamp to [lo, hi]; default if not a number."""
    try:
        f = float(v)
    except Exception:
        return default
    return max(lo, min(hi, f))

def _sanitise_groups(groups):
    """Validated copy of a groups list, or None if unusable."""
    if not isinstance(groups, list) or not groups:
        return None
    if len(groups) > NUM_LEDS:          # cap — huge lists would exhaust RAM
        groups = groups[:NUM_LEDS]
    clean = []
    for g in groups:
        if not isinstance(g, dict):
            return None
        pos = _num(g.get("pos"), 0.0, 1.0)
        w   = _num(g.get("w"),   0.0, 1.0)
        size = g.get("size")
        if pos is None or w is None or not isinstance(size, (int, float)) or size < 1:
            return None
        clean.append({"pos": pos, "w": w, "size": int(size)})
    return clean

def _sanitise_alarms(data):
    """Validated copy of an alarm list, or None if not a list."""
    if not isinstance(data, list):
        return None
    clean = []
    for a in data[:20]:                 # cap alarm count
        if not isinstance(a, dict):
            continue
        try:
            clean.append({
                "enabled":      bool(a.get("enabled", True)),
                "type":         "sunset" if a.get("type") == "sunset" else "sunrise",
                "hour":         max(0, min(23, int(a.get("hour", 0)))),
                "minute":       max(0, min(59, int(a.get("minute", 0)))),
                "duration_min": max(1, min(180, int(a.get("duration_min", 30)))),
                "brightness":   _num(a.get("brightness", 1.0), 0.0, 1.0, 1.0),
                "days":   [d for d in a["days"] if isinstance(d, int) and 0 <= d <= 6]
                          if isinstance(a.get("days"), list) else list(range(7)),
                "boards": [b for b in a.get("boards", []) if isinstance(b, str)],
            })
        except Exception:
            continue                    # skip one bad alarm, keep the rest
    return clean


def on_message(topic, msg):
    """Called by the MQTT library when a message arrives.
    Must NEVER raise — an exception here tears down the MQTT connection,
    so a single bad message could trigger a reconnect storm."""
    try:
        data = ujson.loads(msg)
    except Exception:
        return
    try:
        # The alarms topic carries a bare JSON array (retained schedule)
        if topic == TOPIC_ALARMS:
            _apply_alarms(data)
            return
        if not isinstance(data, dict):
            return
        _handle_message(data)
    except Exception as e:
        sys.print_exception(e)
        print("[mqtt] bad message ignored")


def _apply_alarms(data):
    """Install a new alarm schedule from either transport."""
    clean = _sanitise_alarms(data)
    if clean is None:
        return
    save_alarms(clean)
    print(f"[alarm] schedule updated — {len(clean)} alarm(s)")
    for a in clean:
        if a["enabled"] and (not a["boards"] or BOARD_ID in a["boards"]):
            print("[alarm]   {:02d}:{:02d} UTC {} days={}".format(
                a["hour"], a["minute"], a["type"], a["days"]))


def _handle_message(data):
    # Ignore our own echoed messages
    if data.get("from") == BOARD_ID:
        return

    # Note independence BEFORE the target filter, so the BOSS also sees
    # commands aimed at the follower and stops overwriting them.
    target = data.get("target")
    sender = data.get("from", "")
    if sender and not sender.startswith("board_"):
        global _independent_until
        if target is not None:
            _independent_until = utime.ticks_add(utime.ticks_ms(), INDEPENDENT_MS)
        elif data.get("groups") is not None:
            _independent_until = None   # both lamps just got the same state

    # Ignore messages targeted at a different board
    if target is not None and target != BOARD_ID:
        return

    # State echoes are for web clients only. Without this, every web
    # command made each board re-apply the OTHER board's echo and restart
    # its fade — the visible stutter/flash on every interaction.
    if data.get("echo"):
        return

    print(f"[mqtt] recv: {data}")
    groups         = _sanitise_groups(data.get("groups"))
    on             = data.get("on")
    brightness     = _num(data.get("brightness"), 0.0, 1.0)
    reverse        = data.get("reverse")
    fade_steps     = _num(data.get("fade_steps"), 1, 2000)
    drift_enabled  = data.get("drift_enabled")
    drift_interval = _num(data.get("drift_interval"), 5, 86400)

    if on is not None:
        # Only touch flash when the power state actually flips. The web app
        # includes `on` in every state publish, so persisting unconditionally
        # meant a flash erase/write on every slider tick (~8/s while dragging)
        # — needless wear, and each write stalls the render loop.
        was_on = engine._powered_on
        engine.set_power(bool(on))
        if engine._powered_on != was_on:
            save_state()
    if brightness is not None:
        engine.set_brightness(float(brightness))
    if reverse is not None:
        engine.set_reverse(bool(reverse))
    if fade_steps is not None:
        engine.set_fade_steps(int(fade_steps))
    if drift_enabled is not None:
        engine.set_drift_enabled(bool(drift_enabled))
    if drift_interval is not None:
        engine.set_drift_interval(int(drift_interval))
    if groups is not None and on is not False:
        fade_override = SYNC_FADE_STEPS if data.get("sync") else None
        engine.force_colour(groups, fade_steps_override=fade_override)

    add_net = data.get("add_network")
    if (isinstance(add_net, dict)
            and isinstance(add_net.get("ssid"), str)
            and 0 < len(add_net["ssid"]) <= 32
            and isinstance(add_net.get("password"), str)
            and len(add_net["password"]) <= 64):
        save_network(add_net["ssid"], add_net["password"])

    if "set_alarms" in data:
        _apply_alarms(data["set_alarms"])

    # Run an alarm ramp immediately, so the schedule can be verified
    # without waiting for the wall clock. Value: "sunrise" | "sunset".
    ta = data.get("test_alarm")
    if ta in ("sunrise", "sunset") or ta is True:
        global _test_alarm
        secs = _num(data.get("test_seconds"), 2, 600, 20)
        _test_alarm = {"type": "sunset" if ta == "sunset" else "sunrise",
                       "dur_ms": int(secs * 1000)}
        print(f"[alarm] test requested — {_test_alarm['type']} over {secs:.0f}s")

    if data.get("reboot"):
        print("[mqtt] reboot requested — saving state and rebooting")
        save_state()
        machine.reset()

    # Echo current state back to web clients so the UI stays in sync.
    # Only echo messages that didn't come from another board (avoids loops).
    if sender and not sender.startswith("board_"):
        payload = engine.get_event_payload()
        payload["echo"] = True
        publish_event(payload)


def connect_mqtt() -> MQTTClient:
    import ubinascii, machine
    uid = ubinascii.hexlify(machine.unique_id()).decode()
    client_id = f"{BOARD_ID}_{uid}".encode()
    c = MQTTClient(
        client_id,
        MQTT_BROKER,
        port=MQTT_PORT,
        user=MQTT_USER.encode() if MQTT_USER else None,
        password=MQTT_PASSWORD.encode() if MQTT_PASSWORD else None,
        keepalive=60,
    )
    c.set_callback(on_message)
    c.set_last_will(TOPIC_STATUS, b'{"online": false}', retain=True)
    c.connect()
    c.subscribe(TOPIC_EVENTS)
    c.subscribe(TOPIC_ALARMS)   # retained → schedule redelivered on every connect
    c.publish(TOPIC_STATUS,
              ujson.dumps({"online": True, "fw": FIRMWARE_VERSION,
                           "ntp": ntp_ok}),
              retain=True)
    print(f"[mqtt] connected — client_id={client_id}, topic={TOPIC_EVENTS}")
    return c


def publish_event(payload: dict):
    """Publish a colour/power event to the shared topic."""
    global client
    if client is None:
        return
    payload["from"] = BOARD_ID
    try:
        client.publish(TOPIC_EVENTS, ujson.dumps(payload))
    except Exception as e:
        print(f"[mqtt] publish error: {e}")
        client = None   # trigger reconnect


OTA_HOUR_UTC = 17   # 5 pm UTC — daily reboot triggers boot.py OTA

STATE_FILE  = "state.json"
ALARM_FILE  = "alarms.json"

# ── Alarms ───────────────────────────────────────────────────

_alarms = []

def load_alarms():
    global _alarms
    try:
        with open(ALARM_FILE) as f:
            # Re-sanitise on load — protects against legacy junk on flash
            _alarms = _sanitise_alarms(ujson.load(f)) or []
    except Exception:
        _alarms = []

def save_alarms(data):
    global _alarms
    _alarms = data
    try:
        _write_json(ALARM_FILE, data)
    except Exception as e:
        print(f"[alarm] save failed: {e}")

_saved_state = None

def save_state():
    """Persist power + brightness. Skips the write when nothing changed, so
    callers can invoke it freely without wearing out the flash."""
    global _saved_state
    snap = (engine._powered_on, round(engine._brightness, 3))
    if snap == _saved_state:
        return
    try:
        _write_json(STATE_FILE, {"on": snap[0], "brightness": snap[1]})
        _saved_state = snap
    except Exception as e:
        print(f"[state] save failed: {e}")

def restore_state():
    global _saved_state
    try:
        with open(STATE_FILE) as f:
            d = ujson.load(f)
        br = d.get("brightness")
        if br is not None:
            engine.set_brightness(float(br))
        if not d.get("on", True):
            engine.set_power(False)
            engine._power_level = 0.0  # instant off, no fade-in
            print("[state] restored: off")
        else:
            print(f"[state] restored: on, brightness {br}")
        # Seed the snapshot so an unchanged state never rewrites flash
        _saved_state = (engine._powered_on, round(engine._brightness, 3))
    except Exception:
        pass  # no saved state — use default (on)

def sync_ntp():
    try:
        import ntptime
        ntptime.settime()
        print(f"[ntp] time synced: {utime.localtime()}")
        return True
    except Exception as e:
        print(f"[ntp] sync failed: {e}")
        return False


# ── Setup pulse ──────────────────────────────────────────────

class SetupPulser:
    """Soft warm-white pulse played on the strip during boot setup.
    Call tick() as often as possible inside blocking setup loops.
    Call stop() once setup is complete — it fades out cleanly.
    """
    _SPEED  = 0.004   # radians per ms — ~1.5 s per full breath
    _W_MID  = 60      # midpoint brightness (0-255 W channel)
    _W_AMP  = 50      # amplitude around midpoint

    def __init__(self):
        self._phase    = 0.0
        self._last_ms  = utime.ticks_ms()
        self.active    = True

    def tick(self):
        feed_wdt()   # setup's blocking waits call tick — keep the WDT fed
        if not self.active:
            return
        now = utime.ticks_ms()
        dt  = utime.ticks_diff(now, self._last_ms)
        self._last_ms = now
        self._phase  += self._SPEED * dt
        w = int(self._W_MID + self._W_AMP * math.sin(self._phase))
        strip.set_all(0, 0, 0, w)
        strip.show()

    def stop(self):
        """Fade out over ~400 ms then hand off to the engine."""
        self.active = False
        w = int(self._W_MID + self._W_AMP * math.sin(self._phase))
        for step in range(20):
            w = int(w * (1 - step / 20))
            strip.set_all(0, 0, 0, w)
            strip.show()
            utime.sleep_ms(20)
        strip.off()


# ── Main loop ────────────────────────────────────────────────
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

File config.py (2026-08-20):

# ============================================================
#  config.py  —  Edit this file for EACH board individually
# ============================================================

# ── Board identity ──────────────────────────────────────────
BOARD_ID = "board_a"          # Change to "board_b" on the second Pico
BOSS     = True               # True on board_a (boss), False on board_b (follower)

# ── WiFi credentials ────────────────────────────────────────
# List all known networks — the board will try each in order until one connects.
# NOTE: this repo copy is a TEMPLATE. Put real credentials only in the
# config.py on the board itself — OTA never overwrites it. Do NOT commit
# real passwords: this repo is public (it serves the GitHub Pages web app).
WIFI_NETWORKS = [
    ("YourNetwork",   "YourPassword"),
    # ("iPhone",      "hotspotpass"),
]

# ── MQTT broker ─────────────────────────────────────────────
# Both boards must be able to reach this address.
# Free public option: "broker.hivemq.com"  (no auth, port 1883)
# Self-hosted (e.g. Raspberry Pi running Mosquitto): use its LAN/public IP
MQTT_BROKER   = "broker.hivemq.com"
MQTT_PORT     = 1883
MQTT_USER     = ""             # Leave empty if not required
MQTT_PASSWORD = ""             # Leave empty if not required

# Pick a unique prefix so you don't clash with other people on the public broker.
# broker.hivemq.com is open to the world: anyone using the same prefix shares
# your lamps. Change this before first boot, and make it unguessable — it is
# the only thing separating your lights from a stranger's. The web app shows
# the random prefix it generated for you; paste that same value here.
MQTT_TOPIC_PREFIX = "ember_CHANGEME"   # ← REQUIRED: change this

# ── LED strip ───────────────────────────────────────────────
LED_PIN        = 5             # GPIO pin connected to DIN of SK6812 strip
NUM_LEDS       = 10            # Number of LEDs on the strip
LED_BRIGHTNESS = 0.6           # 0.0 – 1.0  global brightness cap
REVERSE_LEDS   = False         # Set True on board_b if connected to the far end of the strip

# ── Capacitive touch sensors ────────────────────────────────
# List all GPIO pins that have a touch sensor attached.
# You can attach as many as you like — any sensor can trigger events.
TOUCH_PINS = [12]              # e.g. [14, 15]  for two sensors

# Touch detection threshold: lower = more sensitive.
# Raw ADC on the Pico reads charge/discharge time via a resistor.
# Typical resting value ~5–50; touch raises it significantly.
# Tune this per your setup (see README for calibration tip).
TOUCH_THRESHOLD   = 1        # counts above baseline = "touched"
HOLD_TIME_MS      = 3000        # ms held before it counts as a "long press" (toggle off/on)

# ── Colour palette ──────────────────────────────────────────
# Base warm-white RGBW values  (R, G, B, W)  — 0-255 each
# W channel carries most of the warmth; RGB adds tint.
BASE_WARM_WHITE = (0, 0, 0, 200)       # W channel only — pure warm white LED

# Palette of possible hue tints blended on top of warm white.
# Each entry is (R, G, B) normalised 0-255.  Order matters — adjacent
# entries interpolate smoothly, so the more entries the more unique
# in-between colours are possible on every touch.
TINT_PALETTE = [
    (255, 200,  80),   #  0  golden yellow
    (255, 160,   0),   #  1  warm amber
    (255, 120,   0),   #  2  deep amber
    (255,  60,   0),   #  3  orange-red
    (255,   0,   0),   #  4  pure red
    (255,   0,  60),   #  5  red-pink
    (255,   0, 140),   #  6  hot pink
    (200,   0, 200),   #  7  magenta
    (140,   0, 255),   #  8  violet
    ( 80,   0, 255),   #  9  indigo
    (  0,   0, 255),   # 10  pure blue
    (  0,  60, 255),   # 11  blue
    (  0, 140, 255),   # 12  sky blue
    (  0, 200, 255),   # 13  cyan-blue
    (  0, 255, 220),   # 14  cyan
    (  0, 255, 160),   # 15  cyan-green
    (  0, 255,  80),   # 16  green
    (  0, 220,   0),   # 17  pure green
    ( 80, 255,   0),   # 18  yellow-green
    (160, 255,   0),   # 19  lime
    (220, 255,   0),   # 20  yellow-lime
    (255, 240,   0),   # 21  yellow
    (255, 180,  40),   # 22  sunflower
    (255, 100,  80),   # 23  coral
    (255,  80, 160),   # 24  salmon-pink
    (180,  40, 255),   # 25  purple
    ( 40, 100, 255),   # 26  periwinkle
    (  0, 180, 180),   # 27  teal
    ( 20, 255, 120),   # 28  mint
    (255, 220, 120),   # 29  pale gold
]

# Number of independent colour groups the strip is divided into.
# Group sizes are randomised on every tap for an organic feel.
# MIN and MAX control how small or large a single group can be (in LEDs).
NUM_GROUPS    = 3
GROUP_MIN_LEDS = 1    # a group can be as small as a single LED
GROUP_MAX_LEDS = 8    # a group won't consume more than this many LEDs
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

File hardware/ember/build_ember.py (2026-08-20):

# EM-15 rev B. Electronics moved off the strip into a rear bulge so the cable enters
# from the back at the middle. The LED row is continuous and unbroken.
#   strip  x 0..228, y 0..20      LEDs at y=11.000, 16.66667 pitch, x 10.000..176.667
#   bulge  x 74..118, y 20..46    MCU, power, USB-C (bottom side), touch front end
import os, sys, json
import pcbnew
from pcbnew import VECTOR2I, FromMM as MM

OUT, ESP, PADMAP = sys.argv[1], sys.argv[2], sys.argv[3]
KI = os.path.expanduser("~/Applications/KiCad.app/Contents/SharedSupport/footprints")

VERSION  = "rev I"
DESIGNER = "Fionn Ferreira"
# The repo URL is deliberately NOT on the silkscreen - it will outlive the URL.
COPYRIGHT= "\u00a9 2026 Fionn Ferreira"

W, H = 187.0, 20.0
# rev I: the etched comb sensor is gone. A TTP223 module plugs into J4 instead, which
# deletes the pad section, the break-away, the bridges and the touch front end.
BX1, BX2, BY = 66.0, 130.0, 52.0          # electronics bulge, 64 x 32
# 15 LEDs at 11.13333 mm pitch. Fifteen at that spacing give a lit zone of exactly
# 167.00 mm - the lamp length stays put - while worst-case current drops to ~1.69 A,
# back under the 2 A PPTC hold and inside a 2.4 A supply. 20 LEDs needed neither.
NLED, PITCH = 15, 11.13333
# Centred on the strip: equal headroom both ends, so the lit row sits square.
LED_X = [(187.0 - (NLED-1)*PITCH)/2 + PITCH*i for i in range(NLED)]
LED_Y = 11.000

board = pcbnew.BOARD()
board.GetDesignSettings().SetBoardThickness(MM(1.6))
nets = {}
def N(name):
    if name not in nets:
        ni = pcbnew.NETINFO_ITEM(board, name); board.Add(ni); nets[name] = ni
    return nets[name]
for n in ["I2C_SDA","I2C_SCL","GND","VBUS_RAW","VBUS_F","+5V","LED_5V","+3V3","GATE","EN","CC1","CC2",
          "USB_DP_CONN","USB_DM_CONN","USB_DP","USB_DM","LED_DATA_3V3","LED_DATA_5V",
          "LED_DIN1","LD11_DOUT","TOUCH_GPIO","TOUCH_SENSE","BOOT_N","STRAP2","STRAP8",
          "UART_TX","UART_RX"]: N(n)
for i in range(1,NLED): N(f"D_{i}_{i+1}")

placed = {}
def put(ref, lib, fpname, x, y, rot=0, value="", bottom=False):
    path = ESP if lib == "Espressif" else f"{KI}/{lib}.pretty"
    fp = pcbnew.FootprintLoad(path, fpname)
    if fp is None: raise SystemExit(f"MISSING {lib}:{fpname}")
    fp.SetPosition(VECTOR2I(MM(x), MM(y)))
    fp.SetReference(ref); fp.SetValue(value or ref)
    board.Add(fp)                       # must be owned by the board before Flip
    if bottom: fp.Flip(VECTOR2I(MM(x), MM(y)), pcbnew.FLIP_DIRECTION_TOP_BOTTOM)
    if rot: fp.SetOrientationDegrees(rot)
    placed[ref] = fp; return fp

R0402=("Resistor_SMD","R_0402_1005Metric"); C0402=("Capacitor_SMD","C_0402_1005Metric")
C0805=("Capacitor_SMD","C_0805_2012Metric")

# ── The strip: LEDs and their bypass caps. Nothing else lives here.
for i, x in enumerate(LED_X, start=1):
    put(f"LD{i}","LED_SMD","LED_WS2812B_PLCC4_5.0x5.0mm_P3.2mm", x, LED_Y, 90, "SK6812RGBW")
    # Cap sits fully inside the 5 V pour, long axis along x so it intrudes least on the
    # pour's 4.6 mm height. Pad 1 takes 5 V from the fill; pad 2 vias to the GND plane.
    put(f"C{9+i}", *C0402, x + 3.40, 15.10, 0, "100nF")

# ── The bulge. Antenna keep-out lands at x 93.4-106.6, y 38.9-44.3, pointing at the
# free y=46 edge - 21.9 mm clear of the nearest LED copper.
# U1 moves aside so the USB-C can sit dead centre in the bulge. Its antenna keep-out
# then lands at y 40.9-46.3 facing the free y=52 edge, 23.9 mm from any LED copper.
put("U1","Espressif","ESP32-C3-MINI-1", 115.0, 38.0, 180, "ESP32-C3-MINI-1-N4")
# Stays on the HRO TYPE-C-31-M-12 (C165948) despite costing $0.10 more. The cheaper
# GT-USB-7010ASV footprint puts its own mounting posts 0.175 mm from its own GND pads,
# under JLC's 0.25 mm hole-to-copper minimum - not worth a fab flag on the power inlet.
put("J1","Connector_USB","USB_C_Receptacle_HRO_TYPE-C-31-M-12", 98.0, 49.0, 0, "USB-C 16P")

put("C1","Capacitor_SMD","CP_Elec_8x10", 73.0, 24.5, 0, "470uF/10V")
put("SW1","Button_Switch_SMD","SW_SPST_EVQP7C", 84.0, 23.5, 0, "BOOT")
put("F1","Resistor_SMD","R_1812_4532Metric", 92.0, 23.0, 0, "PPTC 2A/4A")
put("Q1","Package_TO_SOT_SMD","SOT-23", 99.0, 23.0, 0, "AO3401A")
put("R8",*R0402, 103.5, 22.4, 0, "100k"); put("C7",*C0402, 106.0, 22.4, 0, "100nF")
put("U3","Package_TO_SOT_SMD","SOT-23-5", 110.5, 23.0, 0, "AP2112K-3.3")
put("C2",*C0805, 115.0, 23.0, 0, "22uF"); put("C3",*C0805, 119.5, 23.0, 0, "22uF")
put("R9",*R0402, 89.0, 26.5, 0, "100k"); put("C8",*C0402, 91.5, 26.5, 0, "100nF")
# R10 was 4.7M for the etched sensor's discharge measurement. With a module doing the
# sensing it is only a pull-down, so it becomes 100k - which deletes the thinnest-stock
# line on the BOM.
put("R10",*R0402, 94.0, 26.5, 0, "100k"); put("R7",*R0402, 96.5, 26.5, 0, "5k1")

put("U2","Package_TO_SOT_SMD","SOT-23-5", 75.0, 31.0, 0, "SN74AHCT1G125")
put("C6",*C0402, 71.0, 31.0, 0, "100nF"); put("R11",*R0402, 78.5, 31.0, 0, "100R")
put("R3",*R0402, 75.0, 34.5, 0, "5k1"); put("C5",*C0805, 70.5, 34.5, 0, "22uF")
put("C4",*C0805, 84.0, 31.0, 0, "22uF"); put("C9",*C0402, 87.5, 31.0, 0, "100nF")
put("R4",*R0402, 90.0, 31.0, 0, "5k1"); put("R5",*R0402, 92.5, 31.0, 0, "5k1")
put("R6",*R0402, 95.0, 31.0, 0, "5k1")

put("U4","Package_TO_SOT_SMD","SOT-23-6", 86.0, 42.0, 0, "USBLC6-2SC6")
put("R1",*R0402, 89.0, 46.5, 0, "5k1"); put("R2",*R0402, 91.0, 46.5, 0, "5k1")
put("H1","MountingHole","MountingHole_2.7mm_M2.5", 126.0, 48.0, 0, "M2.5")
put("H2","MountingHole","MountingHole_2.7mm_M2.5", 126.0, 26.5, 0, "M2.5")
# A screw at each end of the LED strip, so the whole length is held, not just the bulge.
put("H3","MountingHole","MountingHole_2.7mm_M2.5", 6.0, 4.5, 0, "M2.5")
put("H4","MountingHole","MountingHole_2.7mm_M2.5", 181.0, 4.5, 0, "M2.5")

TP = {"TP1":("LED_5V",120.78,27.3),"TP2":("+3V3",118.24,27.3),"TP3":("GND",115.70,27.3),
      "TP4":("GND",113.16,27.3),"TP5":("LED_DIN1",79.5,20.9),"TP6":("TOUCH_SENSE",99.5,26.5),
      "TP7":("LD11_DOUT",178.0,18.6),"TP8":("UART_TX",104.0,31.0),"TP9":("UART_RX",101.0,31.0),
      "TP10":("EN",100.0,18.5),"TP11":("VBUS_F",87.5,18.8)}
for ref,(net,x,y) in TP.items():
    fp = put(ref,"TestPoint","TestPoint_Pad_D1.0mm", x, y, 0, net)
    for p in fp.Pads(): p.SetNet(N(net))
JST3 = ("Connector_JST","JST_PH_S3B-PH-SM4-TB_1x03-1MP_P2.00mm_Horizontal")
# J4: a TTP223-class module plugs straight in, pin order IO / VCC / GND.
# VCC is 3V3 and not 5V on purpose - these modules drive their output rail-to-rail and
# the ESP32-C3 is not 5V tolerant (3.6 V absolute max). At 3V3 the output is safe, and
# R7's 5.1 k stays in series as belt and braces.
fp = put("J4", *JST3, 78.0, 46.0, 0, "IO/VCC/GND")
for pd in fp.Pads():
    pd.SetNet(N({"1":"TOUCH_SENSE","2":"+3V3","3":"GND"}.get(pd.GetNumber(),"GND")))
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

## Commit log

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2026-05-13 Add: Enhanced control features and idle drift synchronization via MQTT
    Expanded ColourEngine with brightness, reverse, fade steps, and drift controls. Integrated board-targeted MQTT messaging and synchronized idle drift impulses across boards.
    [colour.py, main.py]
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2026-05-13 Make auto drift subtle: tiny hue nudges, occasional ±1 LED resize, slow fade
    [colour.py, main.py]
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2026-05-14 Increase default animation speed to 3×, fix alarm board targeting, fix LED overflow
    - Default anim_speed raised from 1.0 to 3.0× (slider range 0.5–10×) so animations
    are visible even at low tick rates; built-in scene speeds updated to match
    - Sunrise alarms: add per-alarm board selector in UI; firmware checks BOARD_ID
    against alarm.boards list before firing
    - Strip preview: split LED row and divider row into separate containers so
    overflow group sizes from MQTT can never add phantom LED cells
    - Clamp incoming MQTT group boundaries to stay within cfg.numLeds
    [main.py]
2026-05-14 Fix frame rate: hardcode 16ms tick in main.py, remove FADE_DELAY_MS import from config
    config.py is never updated by OTA so FADE_DELAY_MS=160 was stuck on boards.
    Moving the tick interval to main.py means the 60fps fix deploys automatically.
    [main.py]
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2026-05-14 Add remote reboot, publish flash indicator, reboot OTA trigger
    - main.py: handle reboot:true MQTT message — saves state then machine.reset()
    so both boards can be force-updated from the web app immediately
    - Web app: status dot flashes on every publish() so user can confirm
    messages are actually being sent
    - Settings: "Reboot Both Boards" button sends reboot command and triggers OTA
    [main.py]
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2026-05-17 Fix critical typo: uxxtime → utime causes tick never to run (no LED updates)
    Also fix Static Rainbow: use anim_mode null so per-LED colour positions
    display statically instead of being overridden by animated rainbow mode.
    [main.py]
2026-05-17 QA fixes: dynamic groups, drift default, static rainbow, candle layout
    - colour.py: force_colour now dynamically resizes per-group arrays so
    Static Rainbow (1 group per LED) works correctly on physical boards.
    Remove unused FADE_DELAY_MS import.
    - web_app: driftEnabled now initialises to true (matches board default)
    so first publishState doesn't silently disable drift on the boards.
    - Candle and Warm White builtins reset to 3 even groups so their
    hardcoded 3-element colour arrays align with group count.
    - Static Rainbow scene sets anim_mode null (already fixed) so per-LED
    colour positions display statically.
    [colour.py]
2026-05-17 Reliability, UX and feature improvements
    Firmware (main.py / colour.py):
    - WiFi reconnect attempted before each MQTT retry — boards recover
    from router restarts without manual intervention
    - Power state now saved to flash on every MQTT on/off command, not
    just before OTA reboots, so unexpected power cuts restore correctly
    - Sunset alarm type: ramps brightness down over duration then powers
    off; toggle per-alarm with 🌅/🌙 button in web UI
    - Candle mode flicker is now temporally smoothed (low-pass drift
    toward random targets, fast drop / slow recovery) — looks like a
    real flame instead of white-noise strobing
    - _fade_steps_per initialised in __init__; lazy hasattr guards rem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
    [colour.py, main.py]
2026-05-17 Add on-board animation library — save once, play with a short message
    Firmware (main.py):
    - animations.json stores named animation presets on the board
    - {save_anim: {name, groups, anim_mode, anim_speed, ...}} saves an entry
    - {play_anim: "name"} triggers it with a tiny payload (no full group data)
    - {delete_anim: "name"} removes an entry
    - {list_anims: true} requests the current library
    - Board publishes anim_library dict once after each MQTT connect so the
    web app syncs automatically; also announces after save/delete
    - load_animations() called at boot — board can play saved animations
    entirely offline after the first save
    Web app:
    - "Board Library" card shows all animations stored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
    [main.py]
2026-05-17 Fix 4 bugs found in full audit
    - boot.py: print status_code before r.close(), not after
    - index.html btn-sync-groups: was using click event as button reference
    (btn.target) — now correctly references the button by ID
    - index.html alarm-type-btn: was mutating DOM directly and not calling
    renderAlarms(), so the sunrise-only brightness slider would stay
    visible after switching to sunset mode; now calls renderAlarms()
    - index.html MQTT scenes handler: updateTargetBtns() now called when
    board names arrive via retained MQTT, so "Send to FF/LS" buttons
    always reflect current board names
    [boot.py]
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2026-05-26 Add top-level crash guard and firmware version string
    The uxxtime typo caused main() to throw NameError on the first loop
    iteration. Because there was no crash handler, the board hung permanently
    — MQTT polling stopped, the reboot button couldn't be received, and the
    only recovery was a physical power-cycle.
    Fix: wrap main() in a try/except at the top level. Any unhandled exception
    now prints a full traceback, turns off the LEDs, waits 5 s, then calls
    machine.reset(). boot.py runs on every reboot and pulls the latest
    firmware from GitHub, so a pushed fix is automatically applied on the
    next crash-reboot cycle.
    Also add FIRMWARE_VERSION printed at boot so you can confirm which
    version a b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
    [main.py]
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2026-06-23 Add WiFi watchdog reboot and remove broken custom animation builder
    - main.py: reboot after 10 min offline (client None); state saved
    before reset so lights restore on/off after reboot; bump firmware date
    - web_app: remove custom animation builder panel and tile (4-col grid);
    strip all dead JS and CSS for custom builder
    Claude-Session: https://claude.ai/code/session_01J826Gf1vVMY1u1ZaURnD6C
    [main.py]
2026-06-23 Remove all animation code from firmware and web UI
    Strips out rainbow/wave/candle/custom animation modes, the board
    animation library (save/play/delete/list), the animation speed slider,
    and the 30fps web preview loop. Only static colour groups with breathing
    and idle drift remain.
    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
    [colour.py, main.py]
2026-06-30 Fix 7 bugs found by high-effort code review
    - main.py: save_alarms now treats null as [] and only updates _alarms
    after a successful disk write (fixes TypeError crash + RAM/disk diverge)
    - main.py: publish state after MQTT reconnect so web UI stays in sync
    when the board drops and reconnects while the browser is already open
    - colour.py: wrap _breathe_phase modulo 2π to prevent float precision
    loss that would freeze the breathing effect after ~36 hours
    - colour.py: remove early return in force_colour when powered off so
    boss sync packets still update target colour state; follower now shows
    correct colour when turned back on instead of stale pre-sync colour
    - index.html: change dri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
    [colour.py, main.py]
2026-07-01 Restore working state — revert animation removal, keep WiFi watchdog
    Brings back full animation support (rainbow/wave/candle/custom) in
    colour.py and main.py, and restores the animation UI in the web app.
    The WiFi watchdog (10-min offline → reboot) introduced earlier is
    retained. Boards will pick up this code on the next OTA reboot.
    [colour.py, main.py]
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2026-07-03 Remove all animation code — clean surgical removal from working state
    Removes rainbow/wave/candle/custom animation modes, animation speed
    slider, board library (save/play/delete), and all related web UI.
    Keeps all other features: scenes, alarms, WiFi management, drift,
    board pills, scenes, power/brightness/fade controls, boss sync.
    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
    [colour.py, main.py]
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2026-07-26 Project cleanup: remove leaked credentials, fix sunset bug, dedupe web UI
    Security:
    - config.py: replace real WiFi passwords and WebREPL password with
    placeholders — this repo is public (GitHub Pages). Boards keep their
    own config.py (never OTA'd), so nothing breaks.
    - main.py: sunset alarm left brightness at 0 after fading out, so the
    next power-on came up dark. Now restores pre-sunset brightness and
    persists the off state. FIRMWARE_VERSION bumped to 2026-07-26.
    - colour.py: drop unused HUE_SHIFT_MIN/MAX import (also removed from
    config template along with unused FADE_DELAY_MS).
    - touch.py: initialise _hold_fired in __init__.
    - hardware_test.py: LED packing didn't mat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
    [colour.py, config.py, hardware_test.py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]
2026-07-26 Fix flash root cause, instant presence via Last-Will, smoother UI
    The flicker/flash on every web interaction had a real cause: boards
    echo their full state after each web command, and the OTHER board could
    not distinguish that echo from a genuine touch impulse — so it re-applied
    the colours and restarted its fade. Every command = fade, then re-fade.
    - Echoes now carry "echo": true and boards skip echo-flagged messages.
    Touch impulses and boss syncs (unflagged) still sync both lamps.
    - MQTT Last-Will presence: each board publishes retained
    {"online": true} on prefix/status/<board_id>; the broker flips it to
    false automatically if the board dies. Web pills are now correct th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
    [colour.py, main.py]
2026-07-26 Smoothness round 2: GC stutter, frozen reconnects, alarm leak, PWA
    - sk6812.py: preallocate the frame word-buffer once instead of allocating
    it at 60 Hz in show() — the per-frame allocation caused periodic GC
    pauses visible as micro-stutter in the breathing.
    - main.py: LEDs keep rendering during blocking WiFi reconnects (tick
    callback) instead of freezing mid-breath for up to ~12 s.
    - main.py: alarm publishes now carry echo:true — an alarm targeting one
    board no longer leaks its state onto the other board.
    - main.py: brightness persisted in state.json alongside on/off, restored
    on boot — survives the nightly OTA reboot.
    - main.py: daily OTA reboot moved 17:00 → 04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
    [boot.py, main.py, sk6812.py]
2026-07-26 Bomb-proof firmware: watchdog, input validation, OTA compile gate
    Defence layers added so the boards recover from anything unattended:
    - Hardware watchdog (8 s): the crash guard catches exceptions but not
    HANGS (stuck DNS, dead socket, lockup). The RP2040 WDT now reboots
    through those. Fed from the main loop, setup pulser, and blocking
    reconnect paths. WATCHDOG_ENABLED=False in config.py for WebREPL
    debugging (guarded import — older per-board configs default to on).
    - MQTT input validation: the events topic is on a PUBLIC broker. Before
    this, one malformed set_alarms message (e.g. [42]) got persisted to
    alarms.json and crashed the main loop on every boot — a permanent
    rem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
    [boot.py, config.py, main.py]
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2026-07-27 Fix alarms: boards never received the schedule, and times were UTC
    Two independent bugs meant alarms effectively did not work.
    1. DELIVERY. Boards subscribed only to the events topic, never to the
    retained alarms topic. The schedule therefore reached a board only if
    it happened to be online at the instant the user pressed a button —
    and the web app's set_alarms went through publish(), which attaches
    `target` when the "Send to" selector is not "Both", so a board could
    be excluded entirely. Boards now subscribe to the retained P/alarms
    topic (bare JSON array, topic-aware dispatch in on_message), so the
    schedule is redelivered on every reconnect, and alarm updates are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
    [main.py]
2026-07-27 Fix fade curve, strip coverage, breathing drift; cache app shell
    colour.py — the fade was interpolating from the CURRENT colour toward the
    target by a growing fraction each step, which compounds. Measured: a
    nominal 1 s fade was 99% complete in 0.35 s, moving 22% -> 62% -> 89% in
    the first quarter and then stalling. That lurch is what made transitions
    feel unsmooth, and it made the Fade Speed slider mostly cosmetic — every
    duration collapsed to ~37% of its nominal length. Fades now interpolate
    from a stored start colour with smoothstep easing: exact duration,
    symmetric ease-in-out, monotonic, lands precisely on target. Same fix
    for the warm-white channel, via a new _start_w_fade helper t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
    [colour.py, main.py, sw.js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]
2026-07-27 Remove dead code
    Found by sweeping every declared symbol and CSS rule for references, not
    by eye:
    - sk6812.py: fill_from_list() had no callers anywhere.
    - touch.py: self._pin_num became write-only when the reusable Pin object
    replaced per-measurement construction.
    - index.html: the /scenes topic was subscribed to, but nothing ever
    published to it and its handler was a no-op that pointlessly refreshed
    the board pills — vestigial from when scenes were MQTT-synced instead
    of stored in localStorage. Removed the subscribe, the handler and
    topicScenes(); the README now marks the topic reserved and unused by
    this client, so another client is still free to claim it.
    Checked and clean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
    [sk6812.py, touch.py]
2026-07-27 Fix boot loop that made the boards unreachable
    `main()` contained two function-level `import machine` statements (the
    daily-OTA and WiFi-watchdog reboot paths). In Python that makes `machine`
    a local for the ENTIRE function, so arming the watchdog near the top of
    main() —
    wdt = machine.WDT(timeout=8000)
    — raised UnboundLocalError before the import ever executed. The crash
    guard caught it, waited 5 s, rebooted, and hit the same error again:
    a permanent boot loop. Boards never reached the MQTT loop, so they
    received nothing at all — which is why the Reboot button appeared dead.
    Introduced in 2026-07-26.4 along with the watchdog.
    Removed all three redundant function-level imports;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
    [config.py, main.py, test_firmware.py]
2026-07-27 Stop flash wear, make OTA all-or-nothing, make per-lamp targeting stick
    Flash wear (main.py): the web app includes `on` in every state publish, so
    the firmware rewrote state.json on every message — roughly 8 flash
    erase/write cycles per second while dragging a slider. That is needless
    wear on a finite-endurance part, and each write stalls the render loop
    on RP2040. State is now written only when it actually changes: immediately
    on a power toggle, before planned reboots, and on a 5-minute flush that
    bounds what an unexpected power cut can lose. save_state() is idempotent,
    so every caller is now free. Measured: 40 slider messages -> 0 writes,
    while real toggles still persist every time.
    All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
    [boot.py, main.py, test_firmware.py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]
2026-07-27 Crash-loop rollback, real sunrise gradient, cross-device scene sync
    Crash-loop rollback (boot.py + main.py): the compile gate rejects firmware
    that doesn't parse, but valid code can still fail at runtime — a stray
    function-level import shadowed a module-level one and both boards
    boot-looped, unreachable until a human pushed a fix. Boards now keep a way
    back. boot.py counts boots that never reach stability (power-on resets
    don't count; only soft/watchdog resets, which is what a crash loop makes).
    main.py clears the counter after a minute of running and promotes the
    running files to .ok backups, rewriting them only when they differ. After
    3 unstable boots the backups are restored and the upd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
    [boot.py, colour.py, main.py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]
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2026-08-20 Make this a self-serve public build
    Nothing here should be able to reach the original pair of lamps, and a
    stranger's install should not be able to reach another stranger's.
    - boot.py pulls OTA firmware from this repo, not the private one, so the
    original boards never see a commit made here.
    - The MQTT topic prefix was a single shared constant. broker.hivemq.com has
    no auth, so that constant was the only separation between installs — every
    public user would have landed on the same lamps. config.py now ships a
    CHANGEME placeholder and the web app generates a random prefix per install,
    storing it in localStorage and showing it in Settings to copy onto boards.
    An emptied prefix f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
    [boot.py, config.py]
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2026-08-20 Add the FL-11 KiCad project, generated and DRC-clean
    Turns the written design into an actual board: 67 footprints at the section 7
    coordinates, 35 nets with every pad assigned, the pours, and the routing that
    section 7.9 says to do first -- SENSE end to end, the LED chain, the tab
    electrodes. kicad-cli reports 0 DRC errors.
    It is NOT orderable yet. 101 connections in the head are unrouted: the power
    path, the USB pair and the module I/O, all of which carry constraints an
    autorouter ignores. The gerbers are a verification artifact, not a fab order.
    hardware/fl11/README.md says so plainly and lists what remains.
    Building it surfaced four things the prose could not:
    - The LED package puts VD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
    [fl11-B_Adhesive.gbr, fl11-B_Courtyard.gbr, fl11-B_Cu.gbr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]
2026-08-20 FL-11 rev B: electronics into a rear bulge, cable enters from the back
    The LED row is untouched -- eleven at 16.66667 mm pitch, continuous, nothing
    breaking the lit line. Everything else moved off the strip into a 48 x 28 mm
    bulge below the middle, with the USB-C on the underside so the plug goes in
    from the back.
    Deleting the old 56 mm head nearly pays for the bulge: 5640 -> 5904 mm2,
    +4.7%. The antenna comes out better than it was, at 21.9 mm from the nearest
    LED copper against a rule of 8. The costs are honest ones: one bottom-side
    part means a second assembly setup, about +$0.63/unit at qty 100, and the
    outline is no longer a plain rectangle so the 6-up panel needs re-nesting.
    Two elec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
    [fl11-B_Adhesive.gbr, fl11-B_Courtyard.gbr, fl11-B_Cu.gbr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]
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2026-08-20 FL-11 rev C: touch terminals join the electronics in the middle
    The touch pad was a break-away tab at the far end, which meant SENSE -- a
    high-impedance node the design calls its least-certain subsystem -- ran the
    length of a strip carrying a 0.89 A switching rail. Moving the pad to a
    snap-off section beside the bulge cuts that run from ~70 mm to ~13 mm, keeps
    it inside the bulge's GND pour, and stops it crossing the LED data channel.
    That crossing was the awkward part of rev B: every x between LEDs carries a
    DOUT-to-DIN hop, so the only legal crossing point was x=188, past
    LD11_DOUT's end. Both the guarded y=18.6 lane and that climb are now gone.
    Deleting the end tab shortens the strip fr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
    [fl11-B_Adhesive.gbr, fl11-B_Courtyard.gbr, fl11-B_Cu.gbr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]
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2026-08-20 FL-11 rev D: single-sided, a break that actually breaks, real part numbers
    Three fixes, each from something that was wrong.
    J1 goes back to the top side. It is a horizontal receptacle, so the plug
    enters along the board plane from the rear edge whichever face it sits on --
    bottom-mounting bought flushness and cost a second assembly setup for it.
    Rear entry is unchanged and the CPL now has zero bottom-side parts, so the
    ~$0.63/unit second-setup charge is gone.
    The touch pad could not have been snapped off. It touched the rest of the
    board on two edges, the bulge at x=120 and the strip along y=20, and only the
    first was cut. The strip is now notched away over y 20-22 so the pad hangs
    off the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
    [fl11-B_Adhesive.gbr, fl11-B_Courtyard.gbr, fl11-B_Cu.gbr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]
2026-08-20 Fix the BOM against live JLCPCB stock, and add the copyright silkscreen
    C25086 was wrong. The dataset I checked reported it Preferred with 469k in
    stock; JLC lists it Extended, 0 stock, MOQ 700. I presented that as verified
    and it was not. Every line is now taken from endpoints that expose the real
    is_basic flag and live stock, and BASIC parts are preferred even where an
    Extended part is nominally cheaper, because BASIC carries no feeder fee and
    no MOQ -- which is the actual problem here.
    100k C25086 -> C25741 BASIC, 15.4M stock
    100R C22369194 -> C25076 BASIC, 9.8M stock
    4M7 C49655641 -> C474132 389k stock, was 9.8k
    22uF C6119897 -> C45783 BASIC, 1.73M stock
    F1 (blank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
    [fl11-bom.csv, fl11.kicad_pcb]
2026-08-20 FL-11 rev E: comb touch electrodes, a fallback header, and the silkscreen that was missing
    Correction first: the rev C and rev D commit messages said the silkscreen carried
    the name, version and repo URL. It did not. The silk() calls were lost in an
    earlier edit and no identity text was on the board at all. They are there now,
    verified in the render: name, version, copyright and repo URL, with the
    copyright repeated on the snap-off pad so it survives the break.
    Interdigitated electrodes, for sensing through plastic. Two solid plates couple
    mostly through the overlay's thickness; a comb pushes the field out of the
    surface as fringing, which is what a finger behind a cover actually intercepts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
    [fl11-B_Adhesive.gbr, fl11-B_Courtyard.gbr, fl11-B_Cu.gbr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]
2026-08-20 FL-11 rev F: 20 LEDs, and two silent routing bugs fixed
    20 LEDs at 8.33333 mm, which is 120 LEDs/m and a standard strip density.
    Twenty at that pitch give a lit zone of exactly 166.67 mm -- the same lamp
    length as eleven at 60/m, at double the density, so the dots blend. The
    outline is unchanged; LED20 lands at x=168.33 on a 187 mm strip.
    F1 becomes 3A hold / 5A trip. Twenty LEDs put worst case at ~2.25 A and the
    2 A part would nuisance-trip. Same 1812 footprint. Two consequences that are
    NOT handled and must not be skipped: the supply has to be 3 A rather than the
    2.4 A the cost model assumed, and the copper was sized for 1.6 A -- the 4.6 mm
    pour probably carries 2.5 A but that sum has not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
    [fl11-B_Adhesive.gbr, fl11-B_Courtyard.gbr, fl11-B_Cu.gbr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]
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2026-08-20 FL-11 rev H: JST plugs, comb fix, fully routed
    Three things you asked for, plus a real bug the review caught.
    JST-PH plugs on the bulge: J2 for the touch pad pair and J4 for a
    commercial sensor, rotated so cables leave along the strip axis in line
    with the LEDs. Solder terminals sit beside both, so the board still works
    with no connectors at all. The comb block keeps bare copper plus back-side
    terminals rather than a plug.
    The comb was wrong. SENSE fingers started at 31.6 and GND at 34.6 on a
    3.0 mm pitch, which puts them on identical y positions -- stacked, not
    interleaved, so half the sensor was shorted geometry rather than a comb.
    GND now sits at the half pitch.
    J4 carries 5V/GND/SIG w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
    [fl11-B_Adhesive.gbr, fl11-B_Courtyard.gbr, fl11-B_Cu.gbr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]
2026-08-20 FL-11 rev I: a TTP223 module replaces the etched sensor
    This is the biggest simplification in the design. A TTP223-class module plugs
    into J4 in IO / VCC / GND order and does the sensing, which deletes the comb
    electrodes, the snap-off pad section, the break line, the webs, both bridges,
    and R10's 4.7M -- the thinnest-stock line on the BOM, now a 100k that was
    already there. It also deletes section 7.5's entire uncertainty: the
    charge-time measurement, the per-unit threshold, the overlay dependence, and
    the note calling touch the least-certain subsystem in the design. touch.py
    becomes a digital read.
    VCC is 3V3 and not 5V on purpose. These modules drive their output
    rail-to-rail and the ESP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
    [fl11-B_Adhesive.gbr, fl11-B_Courtyard.gbr, fl11-B_Cu.gbr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]
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

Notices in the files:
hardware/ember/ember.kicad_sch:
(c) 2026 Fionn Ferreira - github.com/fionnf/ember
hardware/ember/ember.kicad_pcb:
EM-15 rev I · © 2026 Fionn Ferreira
